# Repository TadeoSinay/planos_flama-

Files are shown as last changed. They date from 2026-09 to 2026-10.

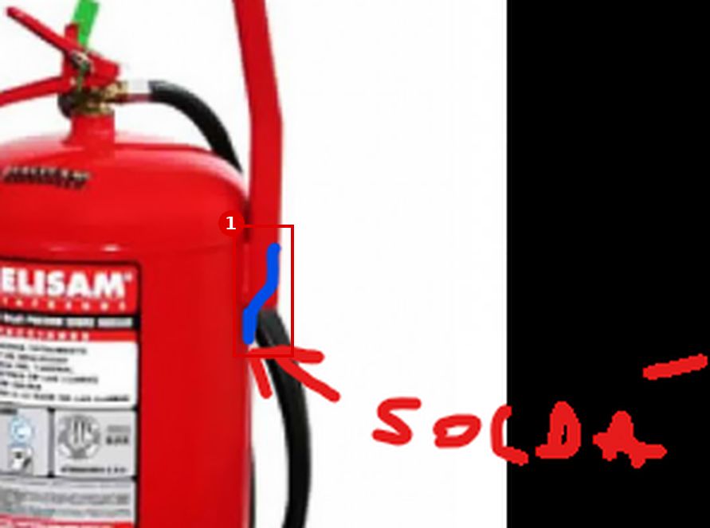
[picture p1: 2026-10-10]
tools/justificacion/figs/F43_c.jpg

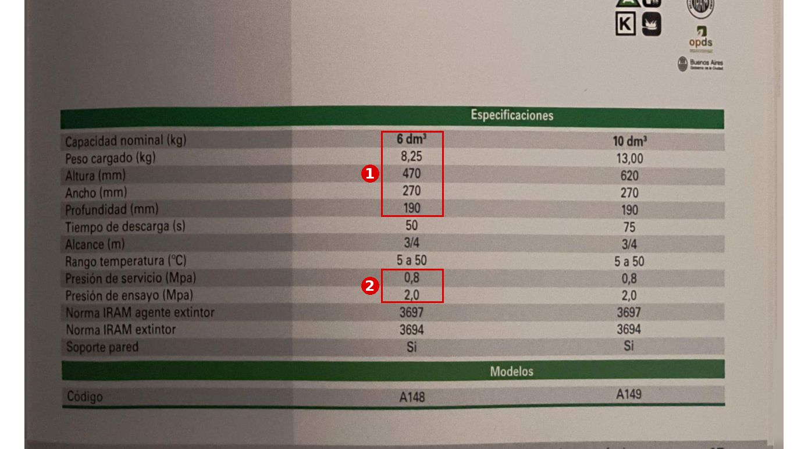
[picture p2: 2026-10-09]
tools/justificacion/figs/F21_c.jpg

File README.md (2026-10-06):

# planos_flama — Planos técnicos de la línea de extintores FLAMA S.A.

Planos de conjunto, cortes, detalles ampliados y modelos 3D de los 17 extintores
del catálogo FLAMA, con rótulo FLAMA S.A. y representación según las normas IRAM
de dibujo técnico y sus equivalentes ISO.

Todo se genera por código a partir de sólidos 3D reales (kernel OpenCascade):
las vistas salen de proyectar esos sólidos con eliminación de líneas ocultas.
Por eso las tres vistas, la isometría, el corte y los detalles son coherentes
entre sí y con el modelo 3D.

## Contenido por modelo (`salida/FL_MAT_<TIPO>_<tamaño>/`)

Nomenclatura: `FL_MAT_<TIPO>_<tamaño>`, por ejemplo `FL_MAT_ABC_10kg`, `FL_MAT_CO2_2kg`,
`FL_MAT_AFFF_50l`. El mismo código figura como N° de plano en el rótulo.

| Archivo | Contenido |
|---|---|
| `FL_MAT_….dxf` | **El plano**: las 3 láminas en un solo dibujo, una presentación por lámina: **Hoja1_Conjunto** (vistas anterior, superior y lateral izquierda en método ISO E, isometría, cotas, números de posición y lista de piezas), **Hoja2_Corte_Detalles** (A2: corte A-A del recipiente y detalles ampliados A–E) y **Hoja3_Especificaciones** (tabla técnica y normas) |
| `FL_MAT_….pdf` | El mismo plano en PDF de 3 páginas a tamaño real (A3/A2) |
| `FL_MAT_….dwg` | Se genera en tu PC con `autocad\1_convertir_DXF_a_DWG.bat` o con el MCP (`autocad_convert_flama_to_dwg`). DWG es un formato cerrado y en este entorno no hay conversor disponible |
| `FL_MAT_….step` | Ensamble 3D con sólidos exactos por pieza (AutoCAD: `IMPORT`) |
| `FL_MAT_…_3D.dxf` | Modelo 3D con una malla por pieza (AutoCAD: `CONVTOSOLID`) |

`salida/FLAMA_planos_completos.pdf` junta los 17 planos (51 láminas) y `salida/validacion.json`
tiene la verificación dimensional.

Los scripts para AutoCAD 2027 están en `autocad/` (ver `autocad/LEAME_AutoCAD.txt`):
convierten los DXF a DWG y abren los modelos 3D con
`"C:\Program Files\Autodesk\AutoCAD 2027\acad.exe" /product ACAD /language "es-ES"`.
Los scripts usan comandos con prefijo `_` (nombres globales en inglés), así que
funcionan igual con AutoCAD en español o en inglés.

## Planos y documentos complementarios

Base normativa leída en su texto completo: **IRAM 3517-2:2020** (dotación, elección, instalación,
señalización, control, mantenimiento y recarga) y **IRAM de Emergencia 3504:2001** (extintores de gases
limpios). Cada lámina y documento cita el apartado. Los PDF de las normas tienen licencia de IRAM y
**no se incluyen en el repositorio**.

Se generan con `python generar.py --complementarios` (o con `python generar.py` sin argumentos).
`salida/FLAMA_complementarios.pdf` junta las 22 láminas y los 5 documentos.

| Carpeta | Código | Contenido |
|---|---|---|
| `salida/cilindros/` | `FL_REC_ABC_1kg` … `FL_REC_ABC_100kg` + `despiece/FL_DES_REC_*` + `FLAMA_cilindros.pdf` | **Cilindros (recipientes ABC sueltos)**, plano de 3 hojas: (1) fabricación: vista, corte A-A, vista D, detalles, cotas con tolerancias; (2) verificación normativa contra IRAM 3523 / 3550 (material, espesor y fórmula 3550 4.1.3, costuras, abertura, estanquidad, expansión, rotura, niebla salina, marcado) y plan de inspección y ensayos por lote; (3) identificación, tapón, protocolo de ensayo y embalaje. Despiece con globos ligado al BOM. DXF + PDF + STEP |
| `salida/sustituto/` | `FL_SUS_00` … `FL_SUS_<tipo>` + `FLAMA_sustitutos.pdf` | **Extintores sustitutos** (IRAM 3517-2:2020 9.4.5; Res. 349/07 art. 32; Res. AGC 32/15): por modelo, faja amarilla ≤ 40 mm en la pollera acotada y desarrollada con sus 3 leyendas, isometría y lista; tarjeta DPS «sustituto habilitado» (PBA) y AGC «Es sustituto» (CABA). FL_SUS_00: equivalencias (igual clase, capacidad ≥) y ciclo de préstamo |
| `salida/senaletica/` | `FL_SEN_01` | Chapa baliza vertical 350 × 870 (y 260 × 870): franjas de 100 mm a 45°, borde fotoluminiscente de 15 mm, tipos de fuego 140 × 140, datos del PRS y n° de puesto (7.2.5, fig. 3); puesto de incendio con alturas (6.2.14, 7.3) |
| | `FL_SEN_02` | Cartel tridimensional de señalización en altura, caras ≥ 280 × 220 a 2,0-2,5 m (7.3, fig. 5) |
| | `FL_SEN_03` | Tipos de fuego: símbolo (letra en contorno) + pictograma, colores IRAM-DEF D 1054 (7.2.2, fig. 1); clases por modelo |
| | `FL_SEN_04` | Etiqueta de control celeste 35 × 50 con frecuencia (8.3.3), "fuera de servicio" 110 × 150 (fig. 8), oblea (9.4.14), numeración (fig. 2), rótulo de manguera 20 × 30 (9.7.1.4) |
| | `FL_SEN_05` | **Sistema de pictogramas NFPA 10 (Anexo B)** por modelo (referencia internacional) |
| | `FL_SEN_06` | Extintor de reserva (faja verde) y sustituto (faja amarilla) (5.3, 9.4.5); placa IRAM 3534 |
| | `FL_SEN_07` | Chapas horizontales o de piso 800 / 500 (fig. 4), chapa de baldes 500 × 500 (fig. 6) y balde 5-7 L (6.2.19) |
| | `FL_SEN_08` | Marbete (anillo plano y cónico, D 33/36/40/50, color por año, fig. 9, tabla 4) y marbete por modelo; traba y precinto (9.4.13) |
| `salida/accesorios/` | `FL_ACC_01` … `03` | Soporte de pared, soporte vehicular y gabinete (7.4), modelados en 3D, 3 vistas ISO E + isometría, STEP |
| `salida/esquemas/` | `FL_ESQ_01` … `03` | Banco de prueba hidrostática (9.7) con presiones de los 17 modelos; línea de carga ABC (9.4.8, 9.4.9); flujo de recarga |
| `salida/documentos/` | `DOC-01` | Tratamiento superficial y pintura: granallado Sa 2½, fosfatizado, polvo poliéster rojo 03-1-050, controles y **saponificación** |
| | `DOC-02` | **Ensayos de fabricación ABC**: rutina, lote y tipo |
| | `DOC-03` | **Control, mantenimiento y recarga por tipo** según IRAM 3517-2:2020 (frecuencias, PH, tabla 3, gas impulsor, recinto de polvo, marbete, inutilización) |
| | `DOC-04` | **NFPA 10 frente a IRAM**: símbolos y colores, pictogramas, NFPA 704, alturas, distancias, intervalos |
| | `DOC-05` | **Ensayos de fabricación HCFC/HFC** según IRAM 3504 |

Origen de cada valor en los documentos: **C** catálogo FLAMA, **N** norma leída, **N\*** norma hermana
aplicada por analogía (IRAM 3504 para criterios de rotura y expansión de los ABC), **R** valor de referencia
a confirmar con la norma de fabricación.

## Modelos

| Código / archivo | Denominación | Norma IRAM agente | Norma IRAM extintor | Fuente de datos |
|---|---|---|---|---|
| FL_MAT_ABC_1kg | Extintor ABC 1 kg | 3569 | 3523 | catálogo pág. 4 · recipiente 1 kg 3" R1 |
| FL_MAT_ABC_2.5kg | Extintor ABC 2,5 kg | 3569 | 3523 | catálogo pág. 4 · recipiente 2,5 kg R2 |
| FL_MAT_ABC_5kg | Extintor ABC 5 kg | 3569 | 3523 | catálogo pág. 4 · recipiente 5 kg R2 |
| FL_MAT_ABC_10kg | Extintor ABC 10 kg | 3569 | 3523 | catálogo pág. 4 · recipiente 10 kg R2 |
| FL_MAT_AGUA_10l | Extintor Agua 10 l | – | 3525 | catálogo pág. 8 |
| FL_MAT_AFFF_10l | Extintor AFFF 10 l | 3515 | 3527 | catálogo pág. 10 |
| FL_MAT_AFFF_50l | Extintor AFFF 50 l sobre ruedas | 3515 | 3541 | catálogo pág. 11 · recipiente 50 kg R2 |
| FL_MAT_BC_5kg | Extintor BC 5 kg | 3569 | 3523 | catálogo pág. 6 · recipiente 5 kg R2 |
| FL_MAT_SALESK_6l | Extintor Sales K 6 l | 3697 | 3694 | catálogo pág. 15 |
| FL_MAT_CO2_2kg | Extintor CO₂ 2 kg | 41170 | 3509 | catálogo pág. 16 |
| FL_MAT_CO2_5kg | Extintor CO₂ 5 kg | 41170 | 3509 | catálogo pág. 16 |
| FL_MAT_HCFC-HFC_5kg | Extintor HCFC/HFC 5 kg | 3526-1 / 3526-5 | 3504 | catálogo págs. 13–14 · recipiente 5 kg R2 |
| FL_MAT_CLASED_9l | Extintor Clase D 9 l | – | 3523 | catálogo pág. 17 · recipiente 10 kg R2 (**ver pendientes**) |
| FL_MAT_ABC_25kg | Extintor ABC 25 kg sobre ruedas | 3569 | 3550 | catálogo pág. 5 · recipiente 25 kg R3 |
| FL_MAT_ABC_50kg | Extintor ABC 50 kg sobre ruedas | 3569 | 3550 | catálogo pág. 5 · recipiente 50 kg R2 |
| FL_MAT_ABC_70kg | Extintor ABC 70 kg sobre ruedas | 3569 | 3550 | catálogo pág. 5 |
| FL_MAT_ABC_100kg | Extintor ABC 100 kg sobre ruedas | 3569 | 3550 | catálogo pág. 5 · rodante 100 kg R1 (Ø390) |

Las normas de producto se transcriben tal como figuran en las filas
"Norma IRAM agente extintor" y "Norma IRAM extintor" del catálogo de referencia.

## Normas de dibujo aplicadas

| Norma | Título | Qué se aplica en las láminas |
|---|---|---|
| IRAM 4501 | Dibujo técnico. Métodos de proyección | Método ISO E: superior (B) debajo de la anterior (A), lateral izquierda (C) a su derecha; símbolo junto a la escala en el rótulo |
| IRAM 4502 | Dibujo técnico. Líneas | Grupo 0,7: A continua gruesa 0,7 (visibles), E trazos **media** 0,35 (ocultas), B continua fina 0,18 (cotas, rayados, referencias, fondos de rosca), F trazo largo y corto fina 0,18 (ejes y centros), G fina con extremos gruesos (plano de corte). Relación 4:2:1 |
| IRAM 4503 | Dibujo técnico. Letras | Letra tipo B vertical; alturas 1,8 · 2,5 · 3,5 · 5 · 7 |
| IRAM 4504 | Formatos, elementos gráficos y plegado de láminas | A3 / A2; recuadro a **25 mm** del borde izquierdo y 10 mm de los demás; marcas de centrado y zonas |
| IRAM 4505 | Dibujo tecnológico. Escalas | Sólo 1:1, 1:2, 1:5, 1:10, 1:20 y 2:1, 5:1; se elige la mayor que entra en A3 o A2 |
| IRAM 4507 | Dibujo técnico. Representación de secciones y cortes | CORTE A-A por el plano de simetría, con letras y flechas |
| IRAM 4508 | Rótulo, lista de materiales y despiezo | Rótulo **175 × 51 mm**; lista de materiales del mismo ancho sobre el rótulo: posición, cantidad, denominación, código, material, **peso**, observaciones |
| IRAM 4509 | Dibujo técnico. Rayados indicadores de secciones y cortes | 45° con línea fina, orientación alternada en piezas contiguas, secciones delgadas ennegrecidas |
| IRAM 4513 | Dibujo técnico. Acotación | Flecha de triángulo lleno **1:4**; separación ≥ altura de cifra; cotas fuera del contorno; coma decimal |
| IRAM 4520 | Dibujo tecnológico. Representación de roscas y partes roscadas | Rosca interior en corte: cresta gruesa, fondo fino |
| IRAM 4540 | Dibujo técnico. Representación de vistas en perspectiva | Isometría con ejes a 120°, sin ocultas |
| ISO 2553 / 4063 | Soldaduras | Filete todo alrededor; proceso **131 MIG** (acero al carbono) o **141 TIG** (inoxidable) |
| ISO 2768-1 | Tolerancias generales | Clase m |

Los datos de las normas IRAM de dibujo (márgenes, rótulo, líneas, flechas, rayados)
se tomaron de resúmenes publicados de cada norma. El texto completo es material
protegido de IRAM y hay que consultarlo en la edición vigente.

## Qué distingue a cada tipo (no sólo las dimensiones)

| Tipo | Recipiente | Válvula | Descarga |
|---|---|---|---|
| ABC / BC / HCFC-HFC | chapa acero SAE 1010, costura MIG, fondo cóncavo con pollera | latón forjado, manómetro IRAM 3533 | manguera + tobera con portatobera (1 kg: tobera directa, sin manguera) |
| Clase D | idem 10 kg | idem | manguera + **lanza aplicadora de flujo suave** con empuñadura |
| Agua | **acero inoxidable AISI 304, costura TIG** | idem | manguera + **tobera de chorro pleno** |
| AFFF | inoxidable, TIG | idem | manguera + **lanza espumígena** con 4 tomas de aire |
| Sales K | inoxidable, TIG | idem | manguera + **lanza aplicadora larga** con boquilla de niebla |
| CO₂ | **cilindro sin costura 34CrMo4, cuello integral**, pie de apoyo | **sin manómetro, con disco de seguridad** | 2 kg: brazo giratorio + difusor; 5 kg: manga de alta presión + difusor con empuñadura y soporte |
| Rodantes ABC | recipiente con dos cabezales, bastidor de caño, ruedas de caucho macizo | idem con manómetro | manguera enrollada + válvula esférica + tobera campana |
| Rodante AFFF 50 l | idem | idem | válvula esférica + **lanza espumígena** |

## Verificaciones automáticas (`verificar.py`)

- Altura y ancho de cada modelo igual al catálogo (±0,05 mm). La profundidad incluye el suncho.
- **Masa**: la suma de la lista de materiales (volumen × densidad) + carga nominal se compara con el peso cargado del catálogo. Da entre −8 % y +12 % en los 17 modelos; el ABC 10 kg da −2 % y su recipiente 5,24 kg, contra 5,48 kg del plano de referencia.
- IRAM 4504 recuadro 25/10, IRAM 4508 rótulo 175 × 51, IRAM 4502 grupo de líneas, IRAM 4513 flecha 1:4, escalas normalizadas, 3 presentaciones, rótulos completos y ningún "A definir".

## Materiales

Ya no queda ningún "A definir". Se respetan los materiales que da el catálogo
(chapa de acero / inoxidable, válvula de latón forjado, manga de caucho sintético,
manómetro con sello IRAM 3533). Para el resto se especifican los materiales
habituales de cada componente: acero SAE 1010 en cuello, manijas y sunchos;
inoxidable AISI 304 en eje y pasador; PVC o polipropileno en el sifón;
polipropileno en toberas y lanzas; polietileno AD aislante en el difusor de CO₂;
caucho macizo y chapa en las ruedas. Ver `flama/materiales.py`.

## Pendientes a confirmar por FLAMA

1. **Clase D 9 l**: el catálogo de referencia sólo tiene clase D de 5 y 10 kg; se usa el recipiente de 10 kg.
2. **Rosca de la válvula de CO₂**: se indica cónica 25E (ISO 11363-1); confirmar con el proveedor del cilindro.
3. **Espesores derivados** (Agua, AFFF, Sales K: 0,8 mm inox; CO₂: 5,4 / 6,0 mm; 70 kg): elegidos para que la masa coincida con el catálogo; confirmar con cálculo a presión de ensayo.
4. Firmas "Revisó" y "Aprobó" del rótulo.
5. Normas de fabricación **IRAM 3523** (polvo manual) y **IRAM 3550** (polvo rodante): confirmar los valores
   N\* y R de DOC-02 (rotura, expansión, ensayos de tipo). **IRAM 3504**: se leyó la edición de emergencia 2001;
   confirmar la vigente. **IRAM 10005**: el archivo recibido es un resumen, no la norma.
6. Pictogramas de las figuras 1 y 5 de IRAM 3517-2 y de NFPA 10: los dibujos son esquemáticos; para imprimir,
   usar los originales de cada norma.

## Regenerar

```bash
python -m venv .venv && . .venv/bin/activate
pip install -r requirements.txt
python generar.py                 # todos
python generar.py FL_MAT_ABC_10kg      # uno
```

Estructura del código:
`flama/catalogo.py` (datos), `flama/modelo3d.py` (sólidos), `flama/vistas.py`
(proyección HLR y cortes), `flama/lamina.py` (formato, rótulo, capas, cotas,
soldadura), `flama/planos.py` (hojas 1–3), `flama/exportar.py` (DXF/PDF/STEP),
`flama/normas.py` (normativa), `flama/recipientes.py` (recipientes sueltos),
`flama/senaletica.py`, `flama/accesorios.py`, `flama/esquemas.py`, `flama/documentos.py`.

## BOM y planos de despiece

`python generar.py --bom` genera **`salida/bom/FLAMA_BOM.xlsx`** y `python generar.py --despiece` genera
**`salida/despiece/FL_DES_<modelo>.dxf/.pdf`** (más `FLAMA_despieces.pdf` con las 17 láminas). Ambos salen del
mismo modelo 3D que los planos FL_MAT / FL_REC, así que código, posición, material, medida y peso coinciden.

| Hoja del Excel | Contenido |
|---|---|
| `01_Indice` | Origen, alcance, niveles, subconjuntos, regla «Entra MRP», códigos, fuentes y **colores de estado** |
| `02_Decisiones` | Decisiones de diseño y abastecimiento con su fundamento (fabricación propia sólo ABC, MRP, polvo DEMSA / Polvex, MAG Arcal 21, varilla, carro propio, tapas, pintura, granallado, inoxidables) |
| `03_Resumen_Productos` | Los 17 productos: agente, carga, gas, pesos frente al catálogo, ítems que entran en MRP |
| `04_BOM_Matafuegos` / `05_BOM_Cilindros` / `06_BOM_Sustitutos` | Tablas planas filtrables (17 FL_MAT, 8 FL_REC, 17 FL_SUS) |
| `07_BOM_Recargas` | Kits RK-*-A/B/C por extintor y caso (IRAM 3517-2:2020), con MRP y proveedor |
| `08_Quimica_Agentes` / `09_Carga_N2` | Densidades (aparente y empacada) y volumen libre, gas impulsor y control de llenado por fórmula |
| `10_Proveedores` | Proveedores nacionales por ítem (principal y alternativa, domicilio, distancia a Avellaneda, precio de referencia, estado) y directorio |
| `11_Validacion_MP` | Respaldo documental y estado de cada materia prima y componente |
| `12_Maestro_Consolidado_MP` | Todo lo que lleva cada matafuego, cilindro, sustituto y kit de recarga por unidad (con Entra MRP, rubro, proveedor y proceso) + insumos de cada proceso con su inductor |
| `13_Fuentes` / `14_Comparacion_Mercado` / `15_Indice_Planos` | Documentos citados, peso contra fabricantes con sello IRAM, índice de planos |
| `BOM_FL_MAT_*` / `BOM_FL_REC_*` | Una hoja por plano: BOM multinivel plegable con fórmulas de peso |

Columnas del BOM: … Origen · **Entra MRP** · **Proveedor principal** · **Alternativa** · Operación · Norma · Fuente ·
Plano · Observaciones. Colores de fila: sin color = validado · **amarillo** = estimado con justificación (norma o
fuente técnica) · **naranja** = a validar (falta dato, cotización o confirmación) · **rojo** = no cumple o decisión
pendiente. Revendidos: el BOM queda completo como referencia y en MRP entra sólo la fila S0 «Equipo terminado
comprado». Proveedores en `flama/proveedores.py`.

Subconjuntos: S1 recipiente (en los ABC = plano FL_REC) · S2 válvula · S3 descarga · S4 carro · S5 carga ·
S6 identificación y precinto · S7 embalaje · S8 soporte · S0 equipo terminado comprado (revendidos).

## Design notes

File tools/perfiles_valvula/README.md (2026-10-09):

# Perfiles de manijas de válvula (planos Fadesa)

Genera `flama/perfiles_valvula.py` a partir de los planos vectoriales Fadesa (no incluidos en el repo).

1. `regiones.py <pdf> x0 y0 x1 y1 600 <salida.png>`: rasteriza la zona de la válvula a 600 dpi y numera las regiones
   cerradas del dibujo (componentes del fondo entre trazos).
2. Mirando la imagen numerada se eligen las regiones de cada pieza (palanca, manija, cuerpo) y en `perfiles.py` se
   pasan a contorno en mm: escala del rótulo (1 kg 1:2,5; 5 kg 1:4), x = 0 en el eje de la válvula, z = 0 en la cara
   superior del cuello (línea entre collarín y rosca).

Zonas usadas (puntos PDF): 1 kg `290 55 445 140`; 5 kg `395 70 525 120`.

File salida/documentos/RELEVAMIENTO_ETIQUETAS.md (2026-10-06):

# Relevamiento de rotulado: norma + mercado → especificación FLAMA

Fuentes. Las normas se citan por apartado y no se transcriben:
- IRAM 3534, 3523, 3550, 3504 y 3517-2.
- IRAM Anexo R.
- Res. OPDS 522/07 y Ord. 40.473.

El relevamiento son 24 fotos de equipos instalados y de la línea de etiquetado (2026):
- Fabricantes: Georgia, Melisam, Fadesa, Horizonte, De León y Maxiseguridad.
- Recargadores: Suyai y Firegram.

La especificación de cada modelo está en la **hoja 4** de su plano FL_MAT. Las piezas están en la BOM, subconjunto S6.

## 1. Etiqueta (placa de características)

| Tema | Norma | Mercado (fotos) | FLAMA adopta |
|---|---|---|---|
| Extensión | IRAM 3534 2.2.4.3: las instrucciones no superan un arco de 108° | La etiqueta envuelve ≈ 200–250°, con columnas laterales de datos y mantenimiento (Georgia, Melisam, Fadesa) | Panel central de 108° con instrucciones, más dos alas de 54° (72° si Ø < 100) |
| Encabezado | 2.2.1 2° marca; 3° a) tipo "MATAFUEGO…" | Marca grande y "EXTINTOR DE POLVO BAJO PRESIÓN" | "FLAMA" y la leyenda de tipo de la norma del producto ("MATAFUEGO A POLVO BAJO PRESIÓN") |
| Instrucciones | 2.2.1 1°: prominentes, con distancia; letra de 3–8 mm (< 9 kg) o 6,5–10 mm (≥ 9 kg) | 3 pasos numerados con ilustración: "ROMPA EL PRECINTO / QUITE EL SEGURO", "COLÓQUESE A 3 m" (1,5 m en 1 kg), "ACCIONE LA PALANCA Y DIRIJA EL CHORRO A LA BASE DEL FUEGO"; la AFFF rodante lleva 4 pasos | Los mismos pasos, adaptados por agente: CO₂, clase K, clase D, AFFF y rodantes |
| Clases | 2.2.2 símbolos ≥ 12 mm; 2.2.3 pictogramas ≥ 18 mm, tachados si no es apto | Fila "PARA FUEGOS CLASE" con el símbolo y el pictograma juntos | Igual |
| Uso eléctrico | — | "APTO PARA INSTALACIONES ELÉCTRICAS" / "NO APTO PARA USAR EN ELECTRICIDAD" | Leyenda en el panel central |
| Logos | 3523 5.2.4 p) Sello IRAM | IRAM, OPDS, GCBA, DPS y QR | Sello IRAM, OPDS, GCBA, DPS y QR a la ficha técnica |
| Datos (ala izq.) | 3534 3° b, c, d, h, i; 3523 5.2.4 (mes/año, n° de recipiente); 7.13 e) | Melisam muestra capacidad, potencial, año, marca del polvo, Ps y PH | Capacidad, agente y grado con marca, potencial + advertencia, Ps, PH, temperaturas, peso total, mes/año, n° de recipiente, "Industria Argentina" |
| Mantenimiento (ala der.) | 3534 3° e, f, g; 3523 5.2.4 j, n, o | Controles mensual, anual y PH cada 5 años; aviso de no mezclar polvos; "presurizar sólo con N₂ seco" | Igual, con el texto del agente por tipo |
| Pie | — | Fadesa: "Habilit. Ord. Mun. 40473 – C.H.A.S. – O.P.D.S. Registro" | FLAMA, domicilio, "Industria Argentina", Ord. 40.473 n°, OPDS n° y C.H.A.S. n° (1, 2,5 y 5 kg) |

## 2. Identificación debajo de la etiqueta y en la válvula

| Elemento | Norma | Mercado | FLAMA |
|---|---|---|---|
| Oblea PBA Ø46 | Res. 522/07 an. 1, 2 y 6: inmediatamente debajo de la placa | Lila con guilloche; anillo "único sello oficial obligatorio…", DPS, Ley 19.587; campo "próxima revisión de carga"; n° tipo "1H01036888" | Pieza `oblea_pba` y detalle R4 |
| Estampilla IRAM | Anexo R | Rosa con guilloche; n° vertical "A 25 1111053"; sello azul; QR; se aplica con etiquetadora. Georgia la pone entre la etiqueta y la oblea | Al costado de la oblea, para respetar la Res. 522/07 (detalle R5). Alternativa: etiqueta BV "MODELO APROBADO" (Horizonte) |
| Tarjeta CABA | Ord. 40.473 art. 6; Res. AGC 32/15 (dos módulos: papel con QR + etiqueta AGC) | Etiqueta autoadhesiva AGC "Tarjeta de Identificación de Extintor" con QR y campos de domicilio, fabricante, recargador, venc. mantenimiento, fecha de fabricación, venc. VU (fabricación + 20 años), n° de tarjeta, agente, capacidad y n° de extintor | Pieza `tarjeta_caba` ≈ 140 × 55 (detalle R8). Antes figuraba como tarjeta colgante: **corregido** |
| Etiqueta de serie | IRAM 3523 5.1 (trazabilidad) | Melisam: etiqueta blanca con QR GS1 "(01)779…" en el costado | Pieza `etiqueta_serie` 45 × 25 a 180° (detalle R7) |
| Faja de garantía | — (garantía comercial) | Georgia: cinta rayada roja y blanca, "ATENCIÓN – la rotura total de esta cinta interrumpe la garantía" | Pieza `faja_garantia` 30 × 40 sobre la unión válvula-cuello (detalle R6). Es el "precinto de apertura" que indica equipo nuevo |
| Precinto | IRAM 3517-2 9.4.13; 3523 3.3.2 | Precinto plástico de color con el nombre del fabricante o recargador (Suyai, Melisam) | Pieza `precinto`: color, "FLAMA" y lote |

## 3. Recargas (no van en el equipo nuevo, sí en la BOM de recargas)

Las fotos de Suyai y Firegram muestran estos elementos:
- Etiqueta de servicio del recargador: n° de extintor, serie, próxima recarga, próxima PH e IRAM 3517-2.
- Precinto de color con el nombre del recargador.

Las normas agregan dos más:
- Oblea PBA de recarga y estampilla-precinto de 1" × 200 mm (Res. 522/07).
- Tarjeta AGC (Ord. 40.473).

Todo esto se agregó a la hoja **Recargas** de la BOM.

## 4. Corrección de datos

- **Potencial del 1 kg con DEM-60:** la licencia IRAM 3523 de Drago (anexo I) dice **1A-5B**. 1A-3B corresponde al polvo Pyrochem. Se corrigió en `flama/agentes.py`, que antes decía 1A-3B:C.

## 5. Pendientes y supuestos

- Medidas reales de la estampilla IRAM (60 × 40), de la tarjeta AGC (140 × 55) y de la faja (30 × 40). Están estimadas a partir de las fotos; hay que confirmarlas con IRAM, con la AGC y con el proveedor.
- 1 kg: la tarjeta AGC no entra en el cuerpo. Se asume que el 1 kg de uso vehicular no la lleva; confirmarlo con la AGC.
- ~~Vida útil~~ RESUELTO: Res. 349/07 art. 26 (mod. 717/07) fija 20 años desde la fabricación (CO₂ 30) y obliga al fabricante a declararla; la tarjeta AGC la incluye. Se agregó a la etiqueta.
- C.H.A.S. (Res. 91/2001): pendiente de leer. Por ahora es un campo a completar en 1, 2,5 y 5 kg.
- Arte final de las ilustraciones de los pasos y de los pictogramas: lo hace el proveedor de etiquetas. El plano fija las posiciones y los tamaños mínimos.
- Números de registro de OPDS, Ord. 40.473 y C.H.A.S.: se completan cuando FLAMA esté inscripta.

## 6. Agregados posteriores (Res. 349/07 PBA y Res. AGC 32/15)

- Cuño DPS de 15 × 7 mm junto al n° del extintor, en pollera u ojiva (Res. 349/07 anexo IV): agregado al marcado grabado (hoja 4 y cilindros).
- Extintor sustituto (IRAM 3517-2:2020 9.4.5): faja amarilla de 40 mm como máximo en la pollera, con 3 leyendas; tarjeta DPS «sustituto habilitado» (Res. 349/07 art. 32); tarjeta AGC «Es sustituto». Planos FL_SUS_*.
- Identificación de recarga completa (IRAM 3517-2, Res. 522/07, Res. 349/07 art. 21 y 28-29, Res. AGC 32/15): lámina FL_SEN_09.

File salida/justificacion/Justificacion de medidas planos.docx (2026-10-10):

Justificación de medidas planos

FLAMA S.A. · origen de cada dimensión de los planos FL_MAT, FL_REC y FL_DES · octubre de 2026

- Cada captura tiene marcas rojas numeradas sobre el dato tomado; debajo, qué dice cada marca. En el Excel «Justificacion de medidas planos.xlsx» la fuente de cada valor se escribe «F10·3» (figura F10, marca 3).
- Lo que no sale de un documento es un valor de diseño FLAMA: figura en la tabla final (D01…) con el link a la línea del generador y en amarillo en el Excel. Naranja = a validar.
- Los procesos FLAMA que mandaste (carros y manuales) fijan el 70 kg (Ø390 × 680), el 100 kg (900), las placas de refuerzo, el tren rodante soldado, el bordón, el encastre del fondo, la muesca del cuello y el número en la cúpula del 1 kg.
- El portaeje con el eje adentro, las chapas triangulares, la manija y la lanza no figuran en los procesos: salen del plano Fadesa «Rodante 50kg 800mm R2» (F41, ángulo medido 30,1°) y de las fotos que mandaste (F42 a F45); sus medidas son de diseño (tabla D). La manija no lleva orejas: el extremo de cada pata se aplasta antes de soldarlo directo al cuerpo, y el doblez de 30° arranca a la altura de la base de la válvula.
- Fadesa es referencia de medidas, no de criterio: donde no cumple la norma manda la IRAM. Ej.: el tren de rodaje sigue la IRAM 3550 tabla III (rueda ≥ Ø300, banda ≥ 50 —Fadesa usa 49—, trocha ≥ 400 entre centros) y no el ancho del catálogo.

1157 dimensiones: con documento 763 (66 %), diseño FLAMA 306 (26 %), a validar 88 (8 %).

## Lo que falta validar

Pieza: dimensión | Modelos | Criterio usado / qué confirmar
Etiqueta / placa de características: Alas laterales (arco c/u) | los 17 | Relevamiento: la etiqueta envuelve ≈ 216° (72° si Ø < 100)
Estampilla IRAM de conformidad: Ancho × alto | los 17 | Anexo R IRAM + relevada (a confirmar)
Etiqueta de n° de serie GS1: Ancho × alto | los 17 | Relevada en Melisam
Faja de garantía válvula-cuello: Ancho × alto (relevada) / dibujada | los 17 | Relevada en la línea Georgia; se dibuja pegada sobre la unión (cuerpo de la válvula, tuerca y cuello), del lado donde no la tapan manómetro ni palancas; el ancho se limita al cuello
Tarjeta de identificación AGC (CABA): Ancho × alto | 16 (todos menos ABC 1 kg) | Relevada en un 10 kg (a confirmar con la AGC)
Cúpula: Altura del casquete | ABC 100 kg, ABC 70 kg | 0,656 × R (relación del cabezal Fadesa 50 kg: 105 / 160) = 0,656 × 195
Fondo: Altura del casquete | ABC 100 kg, ABC 70 kg | 0,656 × R (relación del cabezal Fadesa 50 kg: 105 / 160) = 0,656 × 195

# 1. Planos Fadesa de recipiente

Cotas de los recipientes de 1 a 50 kg y detalles de unión (bordón, fondo encastrado, casquete con borde reducido).

F01 · Plano Fadesa «1kg 3pulg R1» (código G809)

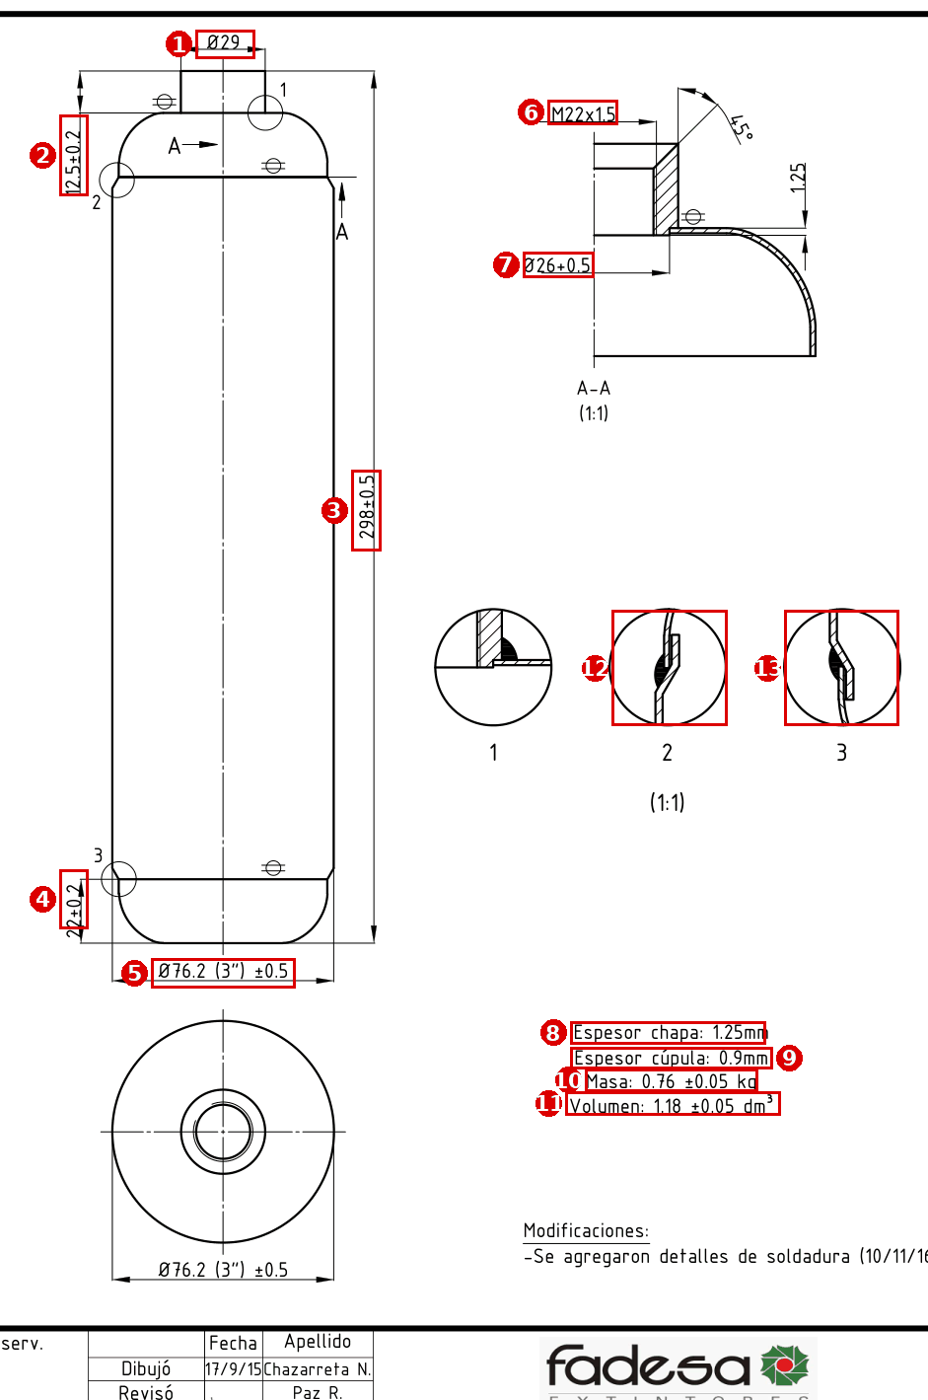
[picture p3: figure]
Plano Fadesa «1kg 3pulg R1» (código G809)

Página 1 (única), cotas y notas del plano

1 Ø29 — Ø exterior del cuello · 2 12,5 ± 0,2 — altura de cúpula · 3 298 ± 0,5 — altura total del recipiente · 4 22 ± 0,2 — altura del fondo · 5 Ø76,2 (3") ± 0,5 — Ø exterior · 6 M22x1,5 — rosca del cuello · 7 Ø26 ± 0,5 — asiento de la válvula · 8 Espesor chapa 1,25 — cuerpo y fondo · 9 Espesor cúpula 0,9 · 10 Masa 0,76 kg — masa del recipiente · 11 Volumen 1,18 dm³ · 12 Detalle 2 (1:1): bordón del caño bajo la cúpula — labio ≈ 5,5, escalón ≈ 4,5 · 13 Detalle 3 (1:1): bordón inferior del caño, fondo por fuera

Nota: El plano no acota la altura del cuello por separado: se tomó 12,5 mm para completar la altura total de 298.

F02 · Plano Fadesa «Recipiente_2.5kg_R2_sin_logo» (código G731)

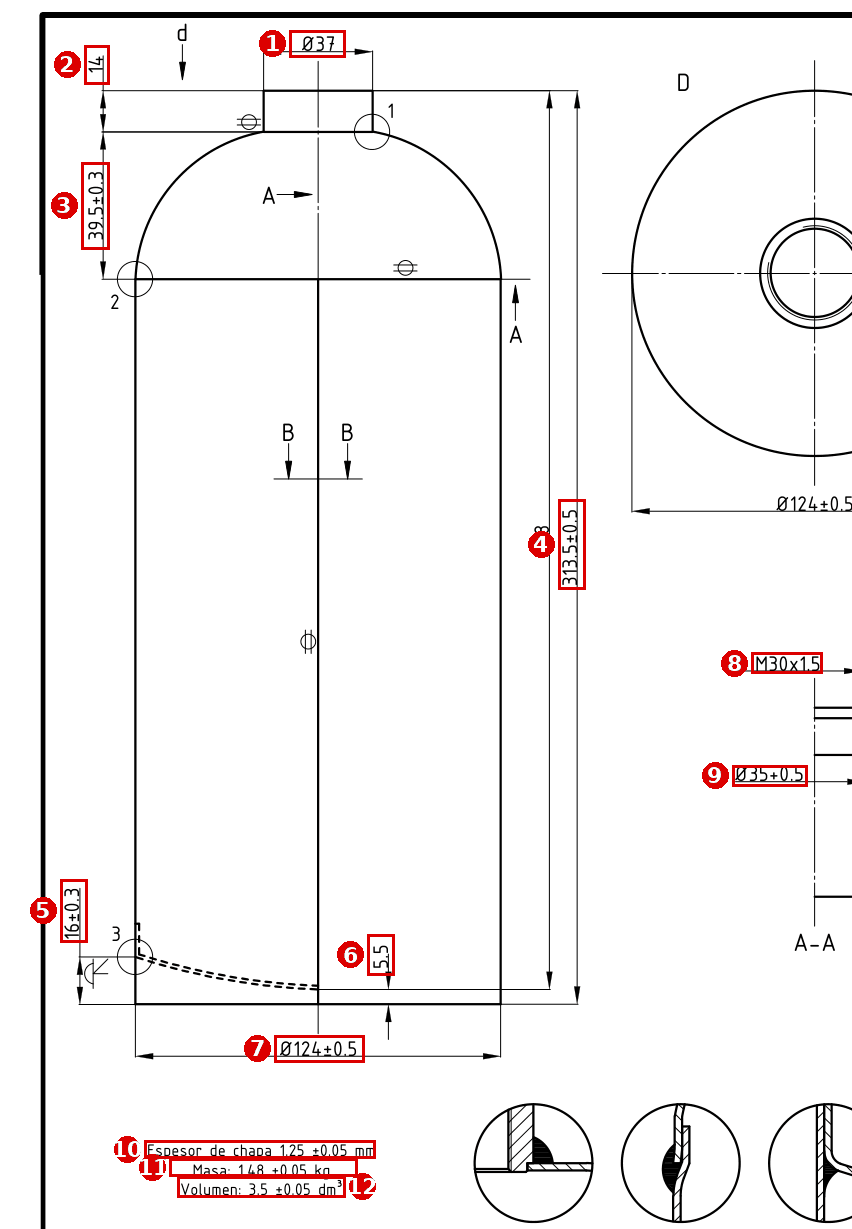
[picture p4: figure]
Plano Fadesa «Recipiente_2.5kg_R2_sin_logo» (código G731)

Página 1 (única), cotas y notas del plano

1 Ø37 — Ø exterior del cuello · 2 14 — altura del cuello · 3 39,5 ± 0,3 — altura de cúpula · 4 313,5 ± 0,5 — altura total · 5 16 ± 0,3 — pollera del fondo cóncavo · 6 5,5 — flecha del fondo cóncavo · 7 Ø124 ± 0,5 — Ø exterior · 8 M30x1,5 — rosca del cuello · 9 Ø35 ± 0,5 — asiento de la válvula · 10 Espesor de chapa 1,25 (cuerpo, cúpula y fondo) · 11 Masa 1,48 kg · 12 Volumen 3,5 dm³

F03 · Plano Fadesa «Recipiente_5kg_R2_sin_logo» (código G732)

Página 1 (única), cotas y notas del plano

1 Ø37 — Ø exterior del cuello · 2 15 ± 0,2 — altura del cuello · 3 54,5 ± 0,3 — altura de cúpula · 4 389,5 ± 0,5 — altura total · 5 21,5 ± 0,2 — pollera del fondo cóncavo · 6 5,5 ± 0,1 — flecha del fondo cóncavo · 7 Ø153 ± 0,5 — Ø exterior · 8 M30x1,5 — rosca del cuello · 9 Ø35 ± 0,5 — asiento de la válvula · 10 Espesor de chapa 1,6 (cuerpo, cúpula y fondo) · 11 Masa 2,78 kg · 12 Volumen 6 dm³ · 13 Detalle 2 (1:1): bordón del cuerpo, cúpula por fuera — labio ≈ 5,8, escalón ≈ 5,2 · 14 Detalle 3 (1:1): fondo encastrado con pestaña ≥ 10, filete por debajo

F04 · Plano Fadesa «Recipiente_10kg_R2_sin_logo» (código G733)

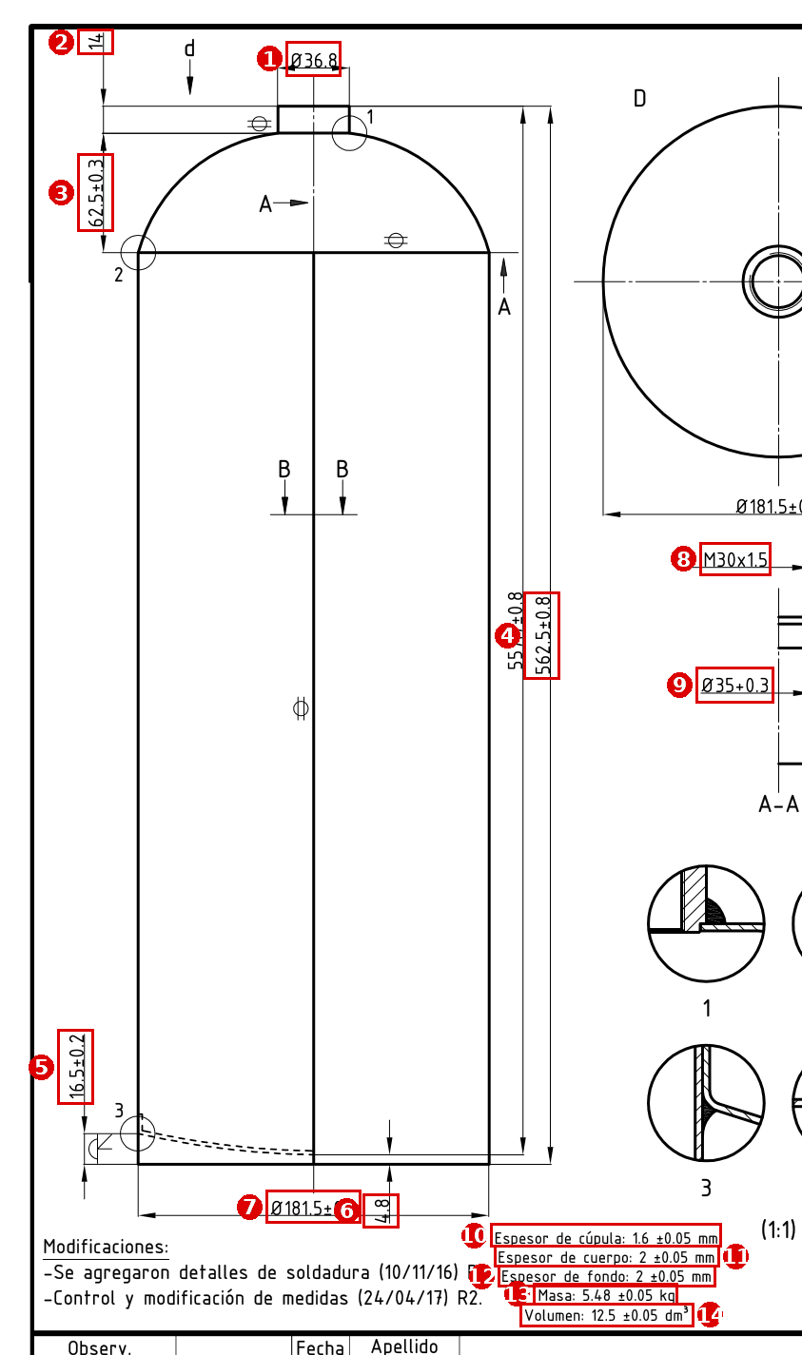
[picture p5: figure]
Plano Fadesa «Recipiente_10kg_R2_sin_logo» (código G733)

Página 1 (única), cotas y notas del plano

1 Ø36,8 — Ø exterior del cuello · 2 14 — altura del cuello · 3 62,5 ± 0,3 — altura de cúpula · 4 562,5 ± 0,8 — altura total · 5 16,5 ± 0,2 — pollera del fondo cóncavo · 6 4,8 — flecha del fondo cóncavo · 7 Ø181,5 ± 0,5 — Ø exterior · 8 M30x1,5 — rosca del cuello · 9 Ø35 + 0,3 — asiento de la válvula · 10 Espesor de cúpula 1,6 · 11 Espesor de cuerpo 2 · 12 Espesor de fondo 2 · 13 Masa 5,48 kg · 14 Volumen 12,5 dm³

F05 · Plano Fadesa «Recipiente 25kg R3» (código G690)

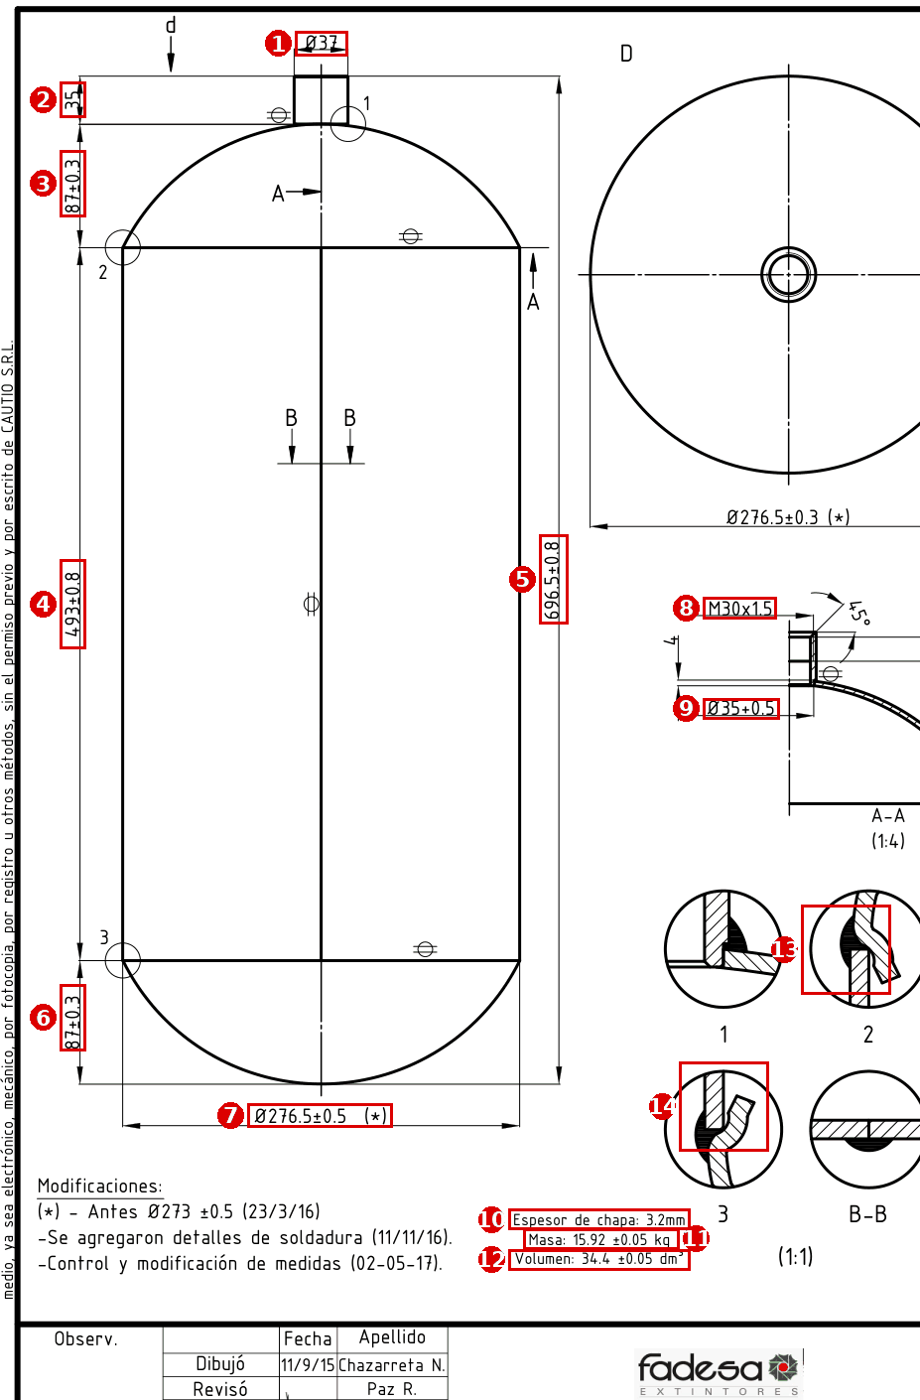
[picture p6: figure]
Plano Fadesa «Recipiente 25kg R3» (código G690)

Página 1 (única), cotas y notas del plano

1 Ø37 — Ø exterior del cuello · 2 35 — altura del cuello · 3 87 ± 0,3 — altura del cabezal superior · 4 493 ± 0,8 — largo del cuerpo entre cabezales · 5 696,5 ± 0,8 — altura total del recipiente · 6 87 ± 0,3 — altura del cabezal inferior · 7 Ø276,5 ± 0,5 — Ø exterior · 8 M30x1,5 — rosca del cuello · 9 Ø35 + 0,5 — asiento de la válvula · 10 Espesor de chapa 3,2 · 11 Masa 15,92 kg · 12 Volumen 34,4 dm³ · 13 Detalle 2 (1:1): casquete con borde reducido y tope dentro del cuerpo · 14 Detalle 3 (1:1): ídem en el casquete inferior

Nota: La altura total 696,5 no es igual a la suma de sus cotas parciales (87 + 493 + 87 + 35 = 702); el plano FLAMA usa las cotas parciales.

F06 · Plano Fadesa «Recipiente 50kg R2» (código G689)

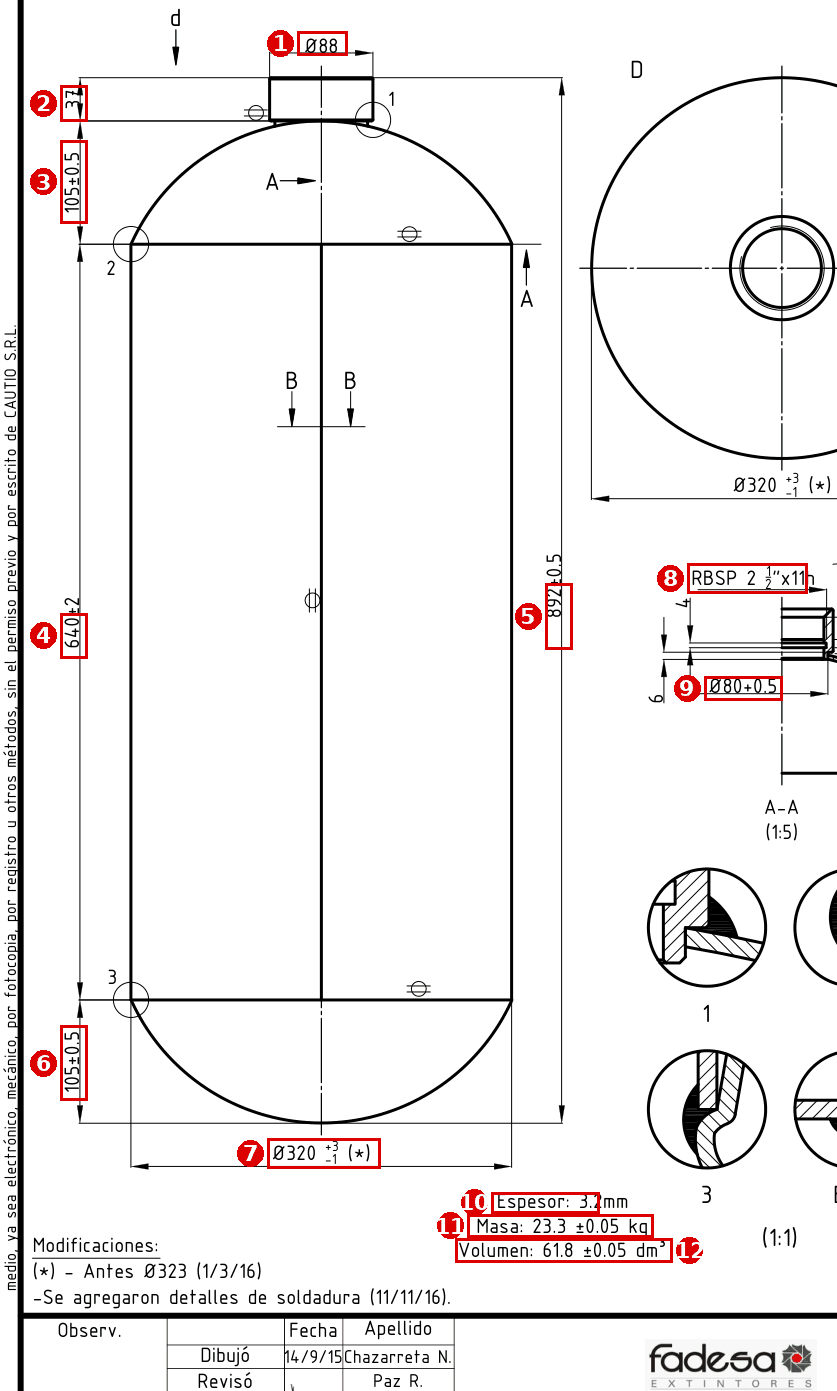
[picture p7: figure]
Plano Fadesa «Recipiente 50kg R2» (código G689)

Página 1 (única), cotas y notas del plano

1 Ø88 — Ø exterior del cuello (cupla) · 2 37 — altura del cuello · 3 105 ± 0,5 — altura del cabezal superior · 4 640 ± 2 — largo del cuerpo entre cabezales · 5 892 ± 0,5 — altura total del recipiente · 6 105 ± 0,5 — altura del cabezal inferior · 7 Ø320 +3/−1 — Ø exterior · 8 RBSP 2 ½" x 11 h — rosca del cuello · 9 Ø80 ± 0,5 — asiento de la válvula · 10 Espesor 3,2 · 11 Masa 23,3 kg · 12 Volumen 61,8 dm³

Nota: La altura total 892 no es igual a la suma de sus cotas parciales (105 + 640 + 105 + 37 = 887); el plano FLAMA usa las cotas parciales. Estas cotas también se usan para el 70 kg (proporción del cabezal y volumen por kg) y para el cuello de 70 y 100 kg.

# 2. Planos Fadesa de extintor completo

Válvula, manómetro, vástago, resorte, caño de pesca, racor, manguera, tobera y suncho medidos a escala; masa total.

F07 · Plano Fadesa «Extintor 1kg Ø76 (Válvula HZ) R1» (código A114/117/122/123/138)

Página 1 (única): notas, cotas generales y piezas del despiece medidas a escala

1 Masa total 1,84 kg (polvo) — referencia de verificación de masa · 2 Válvula HZ · 3 Válvula F510 (esc. 1:2,5): cuerpo 31 × 12 + horquilla 26,5; palanca 67; manija fija 49 + 27 (bajando 34,5); ancho de la válvula 109; espiga M22 Ø21 × 8,6 · 4 Manómetro F645: Ø36 · 5 O-ring F656: Ø24,8 × 3,5 · 6 Vástago F915: Ø5 × 21, asiento Ø9 · 7 Resorte F139: Ø9,8 × 19,9 · 8 Tubo de pesca F003/617: cabeza Ø18,1, tubo Ø14,4

Nota: Piezas medidas sobre el dibujo vectorial a la escala del rótulo (verificada con el Ø del recipiente acotado en su plano de recipiente). Precisión ≈ ±0,5 mm.

F08 · Plano Fadesa «Extintor_2.5kg_Valvula_HZ_R1_sin_logo» (código A101/139/151/128/135)

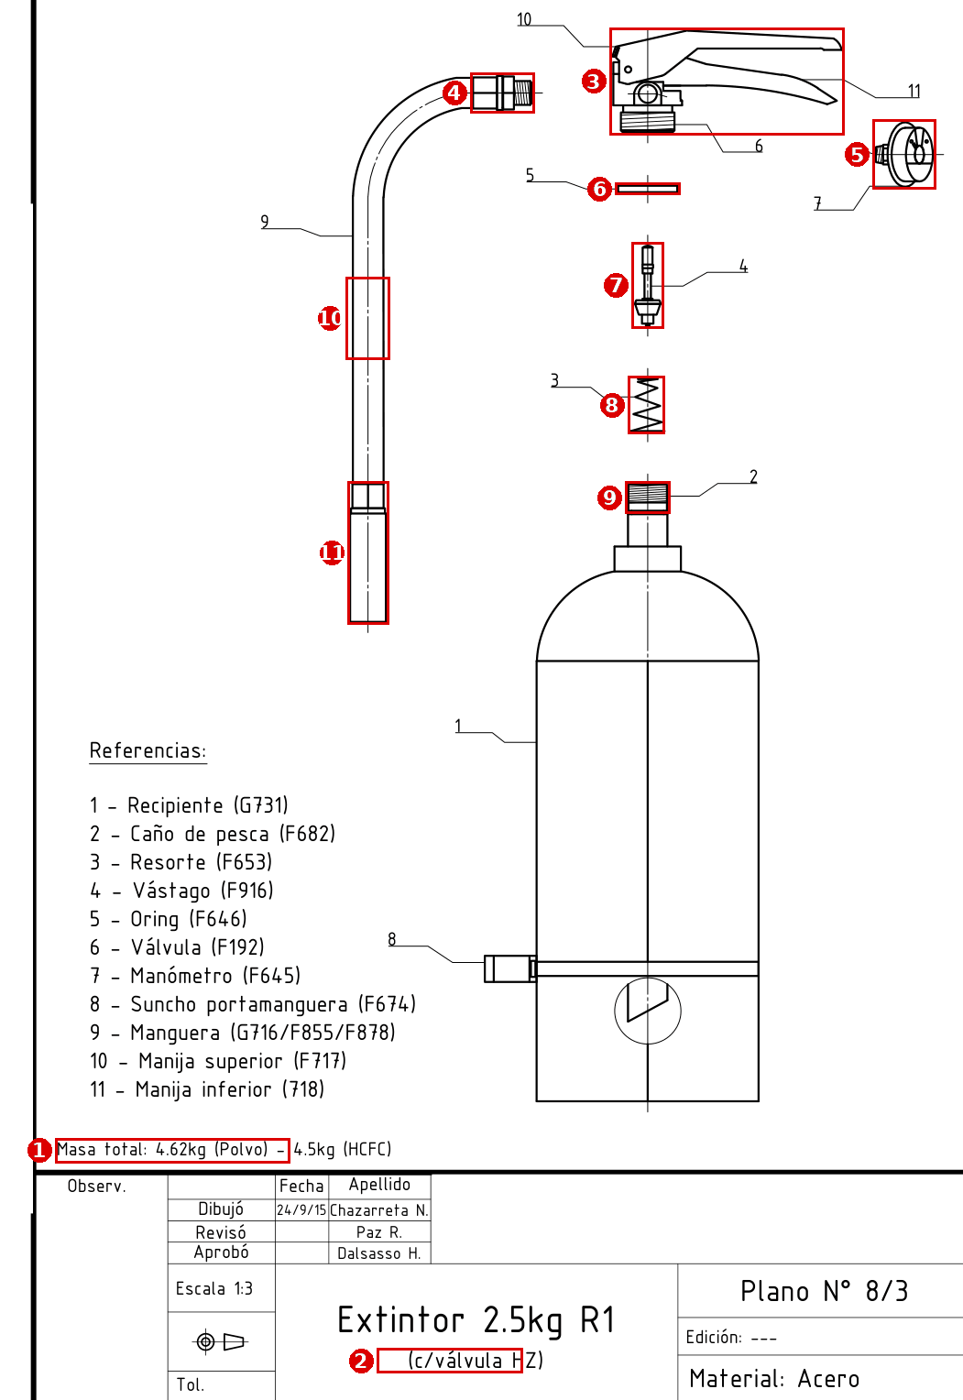
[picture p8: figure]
Plano Fadesa «Extintor_2.5kg_Valvula_HZ_R1_sin_logo» (código A101/139/151/128/135)

Página 1 (única): notas, cotas generales y piezas del despiece medidas a escala

1 Masa total 4,62 kg (polvo) · 2 Válvula HZ · 3 Válvula F192 (esc. 1:3): igual a la del 5 y 10 kg · 4 Racor: tuerca Ø18,8 × 5,9, casquillo Ø16,9 × 13,5, rosca Ø13,1 × 8,9 · 5 Manómetro F645: Ø36 (35,7) · 6 O-ring F646: Ø32,8 × 3,6 · 7 Vástago F916: Ø6 × 30,6, asiento Ø14 · 8 Resorte F653: Ø17,3 × 28,8 · 9 Caño de pesca F682: cabeza Ø21,3 · 10 Manguera: Ø17,4 · 11 Portatobera Ø18,8 × 13,4 + tobera Ø19,9 × 60,1

Nota: Piezas medidas sobre el dibujo vectorial a la escala del rótulo (verificada con el Ø del recipiente acotado en su plano de recipiente). Precisión ≈ ±0,5 mm.

F09 · Plano Fadesa «Extintor_5kg_Valvula_HZ_R1_sin_logo» (código A102/116/140/163/152/111/129/136)

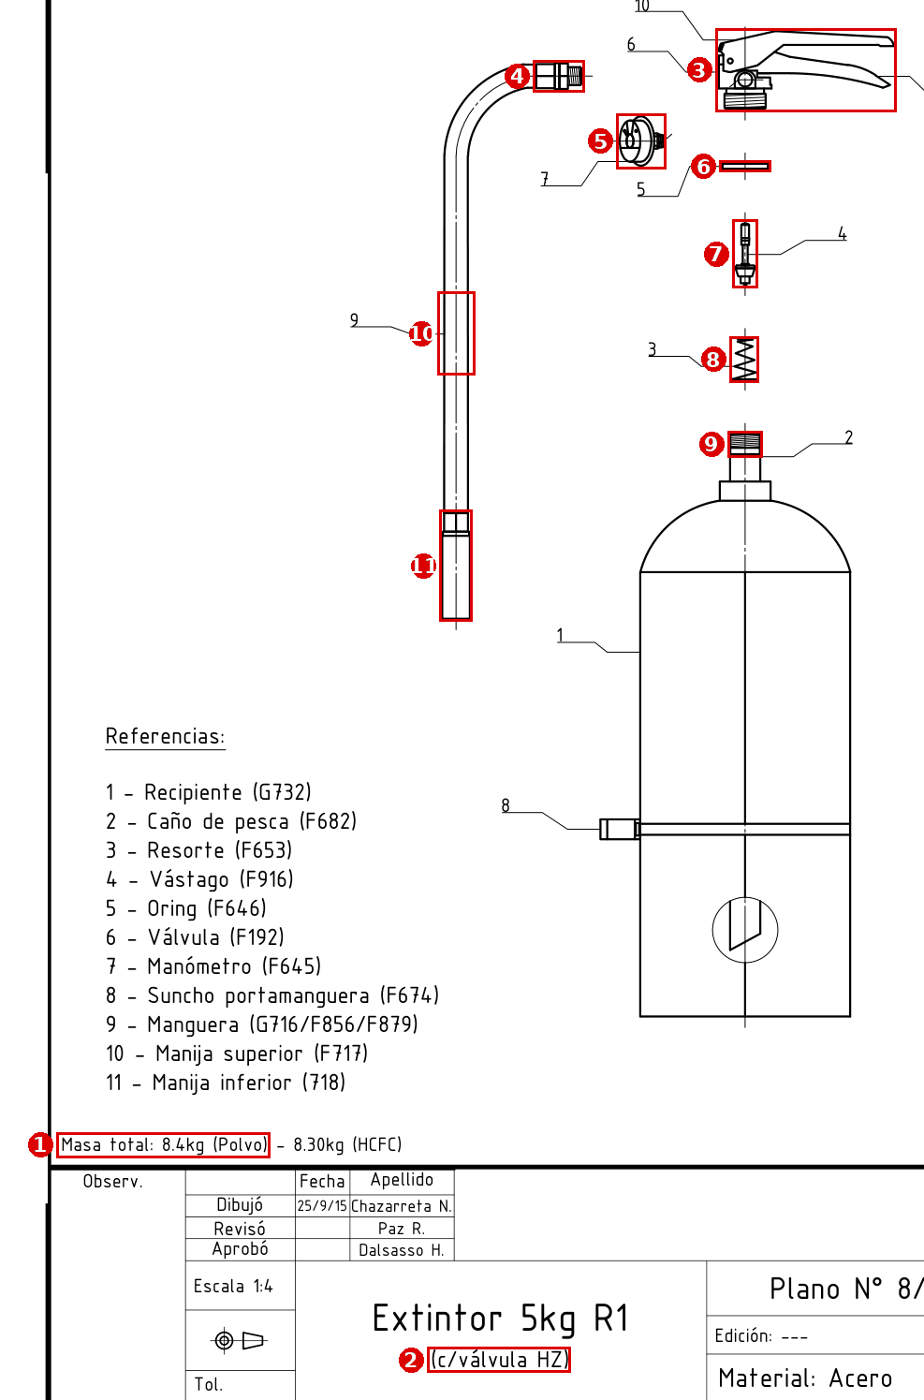
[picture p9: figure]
Plano Fadesa «Extintor_5kg_Valvula_HZ_R1_sin_logo» (código A102/116/140/163/152/111/129/136)

Página 1 (única): notas, cotas generales y piezas del despiece medidas a escala

1 Masa total 8,4 kg (polvo) · 2 Válvula HZ · 3 Válvula F192 (esc. 1:4): palanca 127 de largo, 41,5 de alto sobre el cuerpo; cuerpo 38 × 12,8 + horquilla 32,2; espiga M30 Ø29,8 × 10,8; cuello Ø27,2 × 4,1; manija fija 50 + 36 · 4 Racor: tuerca Ø18,8 × 5,9, casquillo Ø16,9 × 13,5, rosca Ø13,1 × 8,9 · 5 Manómetro F645: Ø36 (35,7) · 6 O-ring F646: Ø32,7 × 3,6 · 7 Vástago F916: Ø6 × 30,8, asiento Ø14 · 8 Resorte F653: Ø17,3 × 28,8 · 9 Caño de pesca F682: cabeza Ø21,3 · 10 Manguera: Ø17,4 · 11 Portatobera Ø19 × 13,3 + tobera Ø19,9 × 60

Nota: Piezas medidas sobre el dibujo vectorial a la escala del rótulo (verificada con el Ø del recipiente acotado en su plano de recipiente). Precisión ≈ ±0,5 mm. Esta válvula F192 es la que se usa también en los manuales revendidos (BC, HCFC, agua, AFFF, Sales K, clase D, CO₂ como referencia).

F10 · Plano Fadesa «Extintor_10kg_HZ_R1_sin_logo» (código A103/141/164/153/112/130/137)

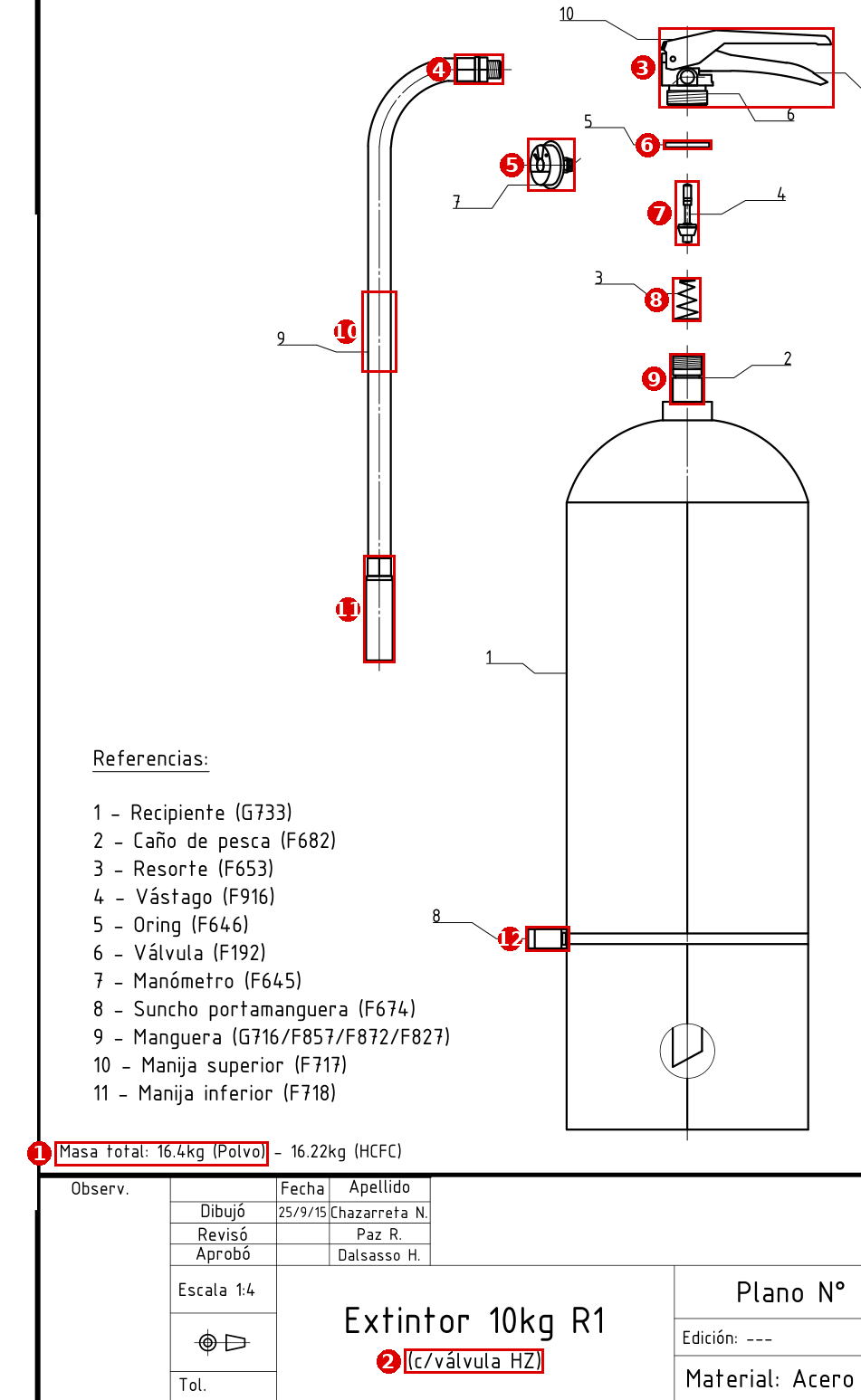
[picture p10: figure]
Plano Fadesa «Extintor_10kg_HZ_R1_sin_logo» (código A103/141/164/153/112/130/137)

Página 1 (única): notas, cotas generales y piezas del despiece medidas a escala

1 Masa total 16,4 kg (polvo) · 2 Válvula HZ · 3 Válvula F192 (esc. 1:4): 127 × 41,5; espiga M30 Ø29,8 × 10,8 · 4 Racor: tuerca Ø18,8, casquillo Ø16,9, rosca Ø13,1 · 5 Manómetro F645: Ø36 (35,7) × 31,5 con vástago · 6 O-ring F646: Ø32,7 × 3,6 · 7 Vástago F916: Ø6 × 30,6, asiento Ø14 × 14 · 8 Resorte F653: Ø17,3 × 28,8 · 9 Caño de pesca F682: cabeza Ø21,3 × 14,4 · 10 Manguera: Ø17,4 (líneas a 12,1 pt) · 11 Portatobera Ø18,8 × 13,4 + tobera Ø19,9 × 60,1 · 12 Suncho portamanguera F674: banda 14,4, sobresale 28,8

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

F11 · Plano Fadesa «Extintor rodante 25kg R1» (código B202/204/217/225/229/235)

Página 1 (única): notas, cotas generales y piezas del despiece medidas a escala

1 Masa total 53,2 kg — referencia de masa (calibración de llanta y sunchos) · 2 1140 — altura total (coincide con el catálogo) · 3 Ø300 — rueda (coincide con el catálogo) · 4 Válvula F192 (esc. 1:6): la misma de los manuales (cuello M30) · 5 Manómetro F645 + cubremanómetro G711: Ø47 · 6 O-ring F646: Ø32,8 · 7 Vástago F916: Ø6 × 30,6 · 8 Resorte F653: Ø17,5 × 29 · 9 Caño de pesca F226: cabeza Ø21,3

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

F12 · Plano Fadesa «Extintor rodante 50kg R1» (código B206/216/222/230/232/236/247)

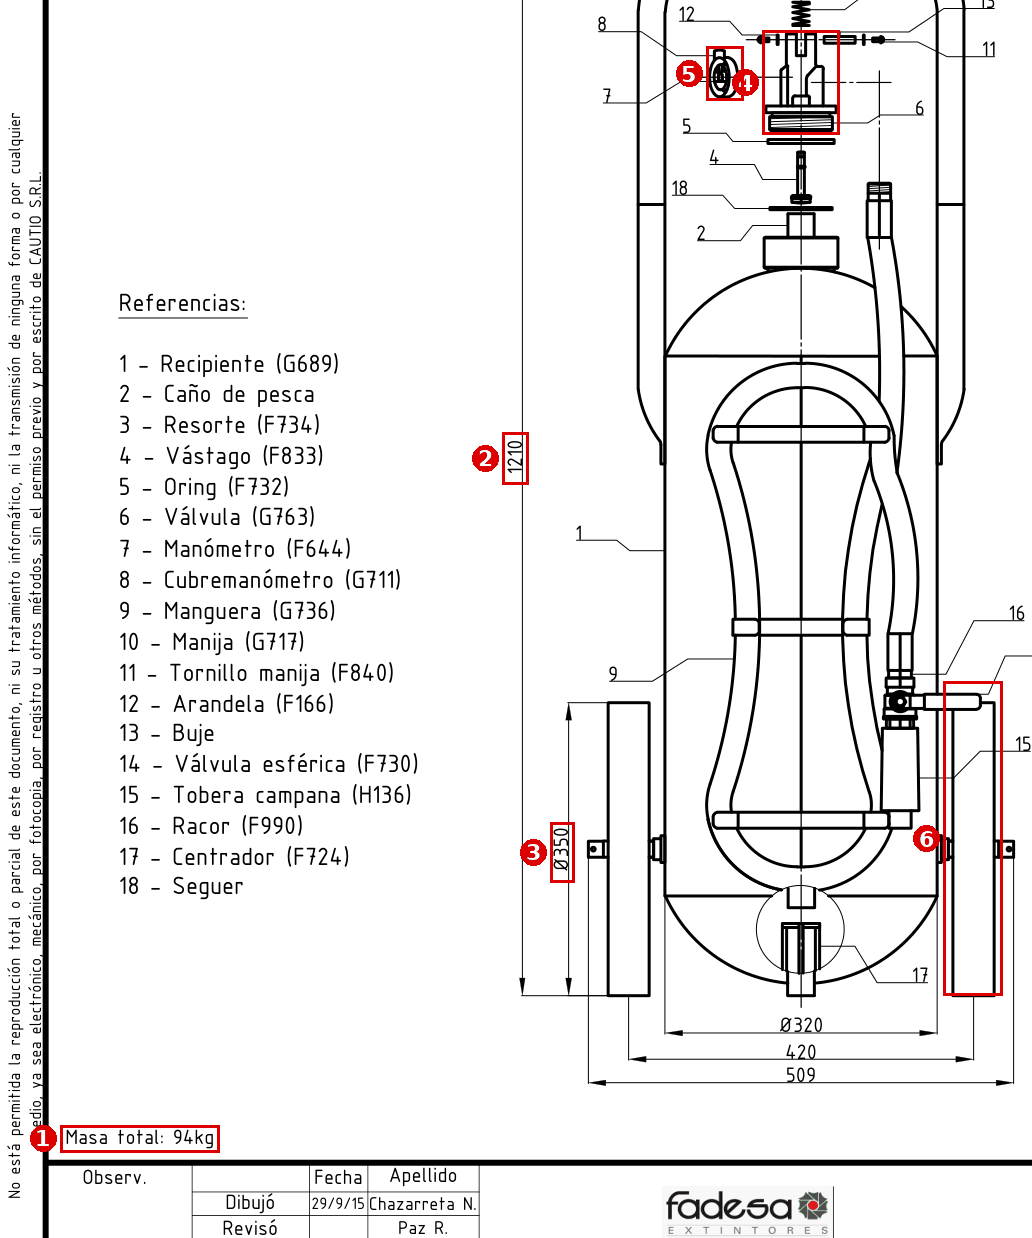
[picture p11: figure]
Plano Fadesa «Extintor rodante 50kg R1» (código B206/216/222/230/232/236/247)

Página 1 (única): notas, cotas generales y piezas del despiece medidas a escala

1 Masa total 94 kg · 2 1210 — altura total (coincide con el catálogo) · 3 Ø350 — rueda (coincide con el catálogo) · 4 Válvula G763 (esc. 1:7): brida Ø83 × 12 + rosca 2½" Ø75 × 17,6; cuerpo 49 × 67 · 5 Manómetro F644 + cubremanómetro G711: Ø47 · 6 Rueda Ø350: ancho de banda 48,9 (líneas a 19,8 pt)

Nota: Piezas medidas sobre el dibujo vectorial a la escala del rótulo (verificada con el Ø del recipiente acotado en su plano de recipiente). Precisión ≈ ±0,5 mm. Esta válvula y estas ruedas se usan también en el 70 kg y en el AFFF 50 l.

F13 · Plano Fadesa «Extintor rodante 100kg R1» (código B208/214/237/238/239/243/244/245)

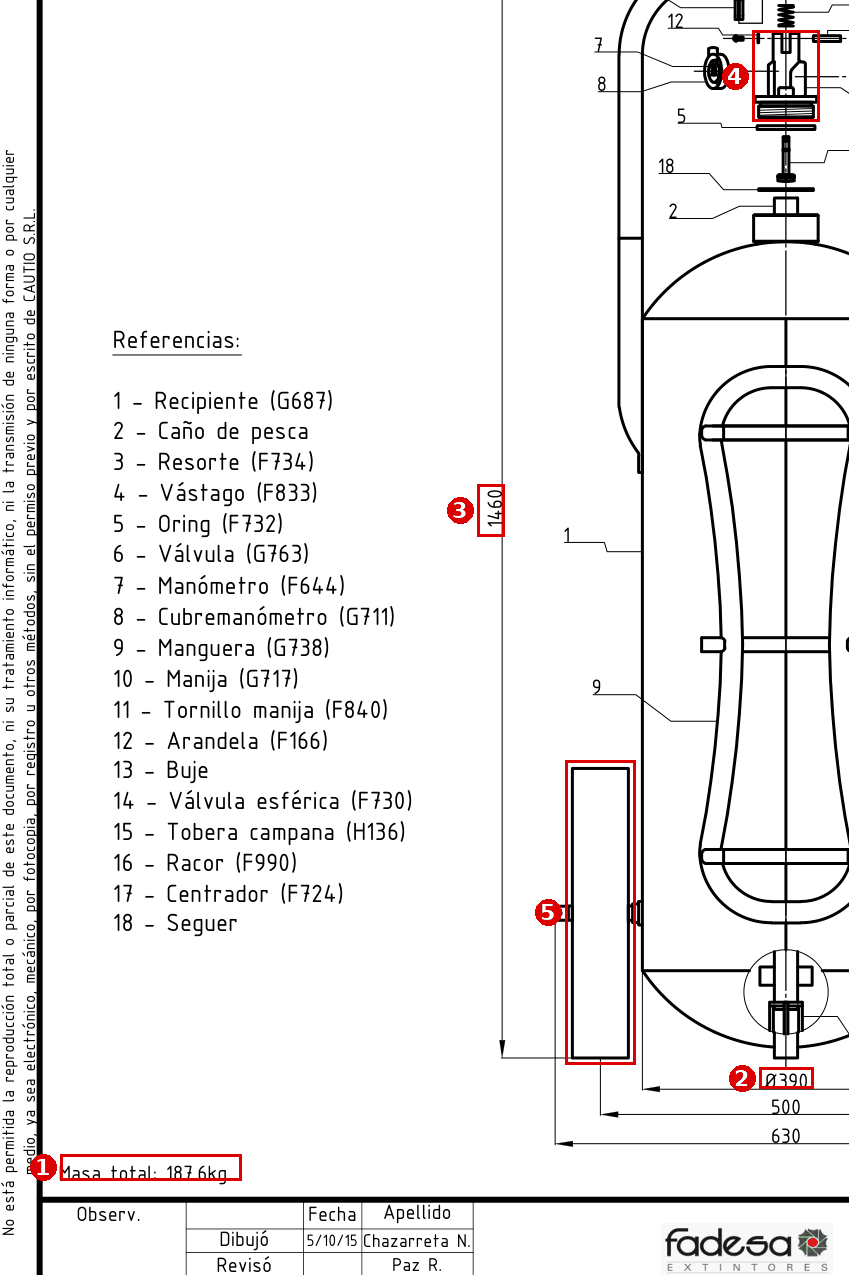
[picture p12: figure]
Plano Fadesa «Extintor rodante 100kg R1» (código B208/214/237/238/239/243/244/245)

Página 1 (única): notas, cotas generales y piezas del despiece medidas a escala

1 Masa total 187,6 kg · 2 Ø390 — Ø exterior del recipiente de 100 kg · 3 1460 — altura total del plano Fadesa (el catálogo dice 1400) · 4 Válvula G763 (esc. 1:8): igual a la del 50 kg · 5 Rueda Ø400: ancho de banda 76 (líneas a 26,9 pt); trocha 500

Nota: Del plano de 100 kg se tomó el Ø390, la masa total y el ancho de rueda; el plano no acota el recipiente: cuerpo y cabezales del 100 kg se calcularon (figura del código _g_rodante). Piezas medidas sobre el dibujo vectorial a la escala del rótulo (verificada con el Ø del recipiente acotado en su plano de recipiente). Precisión ≈ ±0,5 mm.

# 3. Catálogo Fadesa 3

Peso, altura, ancho, profundidad, rueda, manga y presiones de cada modelo.

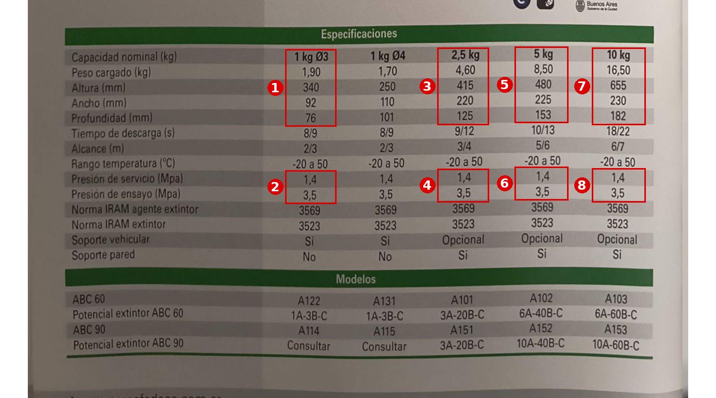
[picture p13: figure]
Catálogo Fadesa 3, pág. 4: tabla «Especificaciones»

F14 · Catálogo Fadesa 3, pág. 4: tabla «Especificaciones» Página 4, tabla Especificaciones 1 1 kg Ø3: peso cargado, altura, ancho, profundidad · 2 1 kg Ø3: presión de servicio y de ensayo (MPa) · 3 2,5 kg: peso cargado, altura, ancho, profundidad · 4 2,5 kg: presión de servicio y de ensayo (MPa) · 5 5 kg: peso cargado, altura, ancho, profundidad · 6 5 kg: presión de servicio y de ensayo (MPa) · 7 10 kg: peso cargado, altura, ancho, profundidad · 8 10 kg: presión de servicio y de ensayo (MPa) | F15 · Catálogo Fadesa 3, pág. 5: tabla «Especificaciones» Página 5, tabla Especificaciones 1 25 kg: peso cargado, altura, ancho, profundidad, Ø rueda, manga · 2 25 kg: presión de servicio y de ensayo (MPa) · 3 50 kg: peso cargado, altura, ancho, profundidad, Ø rueda, manga · 4 50 kg: presión de servicio y de ensayo (MPa) · 5 70 kg: peso cargado, altura, ancho, profundidad, Ø rueda, manga · 6 70 kg: presión de servicio y de ensayo (MPa) · 7 100 kg: peso cargado, altura, ancho, profundidad, Ø rueda, manga · 8 100 kg: presión de servicio y de ensayo (MPa)

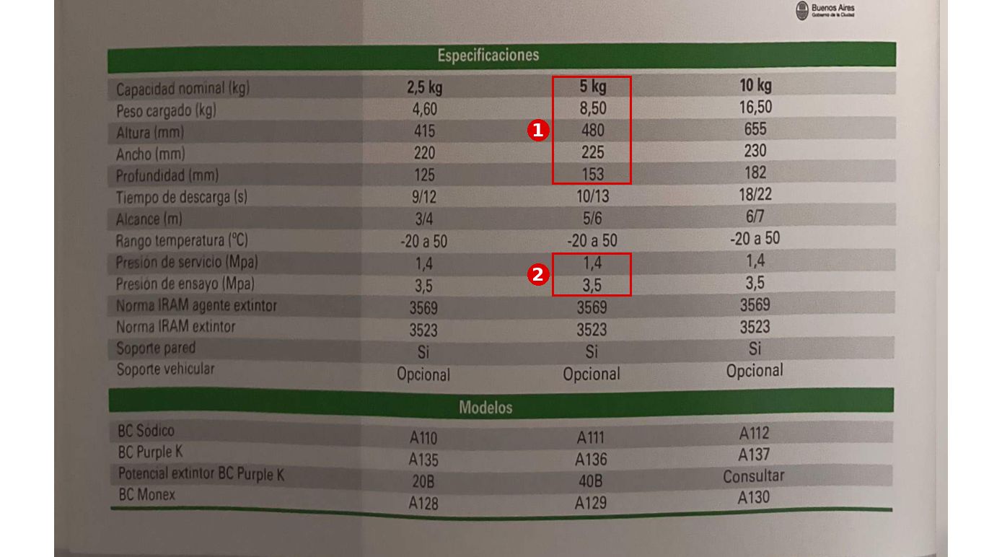
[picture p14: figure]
Catálogo Fadesa 3, pág. 6: tabla «Especificaciones»
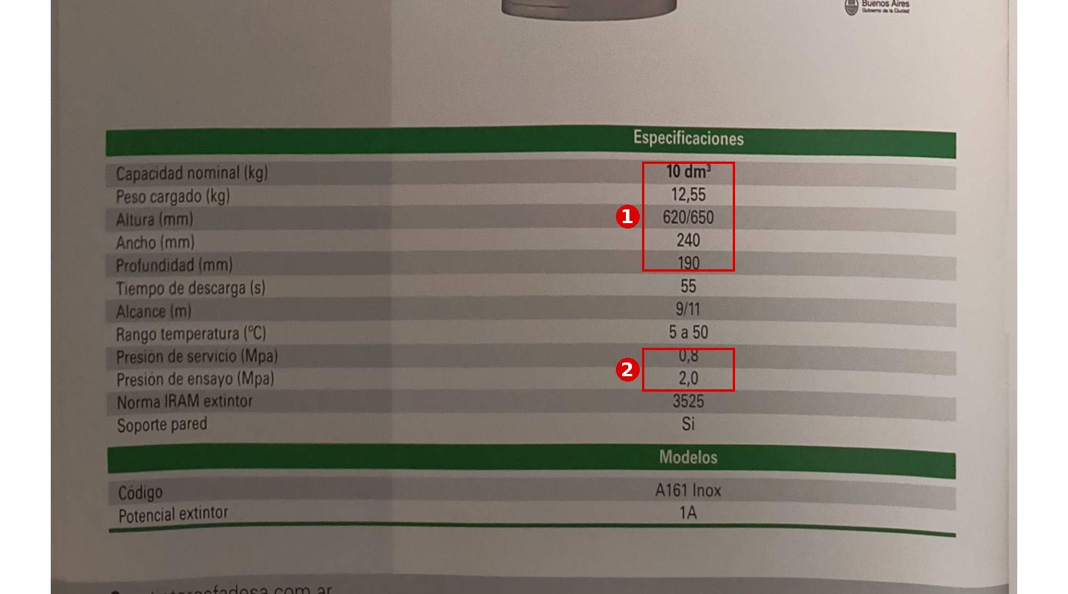
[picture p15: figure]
Catálogo Fadesa 3, pág. 8: tabla «Especificaciones»

F16 · Catálogo Fadesa 3, pág. 6: tabla «Especificaciones» Página 6, tabla Especificaciones 1 BC 5 kg: peso cargado, altura, ancho, profundidad · 2 BC 5 kg: presión de servicio y de ensayo (MPa) | F17 · Catálogo Fadesa 3, pág. 8: tabla «Especificaciones» Página 8, tabla Especificaciones 1 Agua 10 dm³: peso cargado, altura, ancho, profundidad · 2 Agua 10 dm³: presión de servicio y de ensayo (MPa) Nota: La altura figura como 620/650: el plano usa 650.

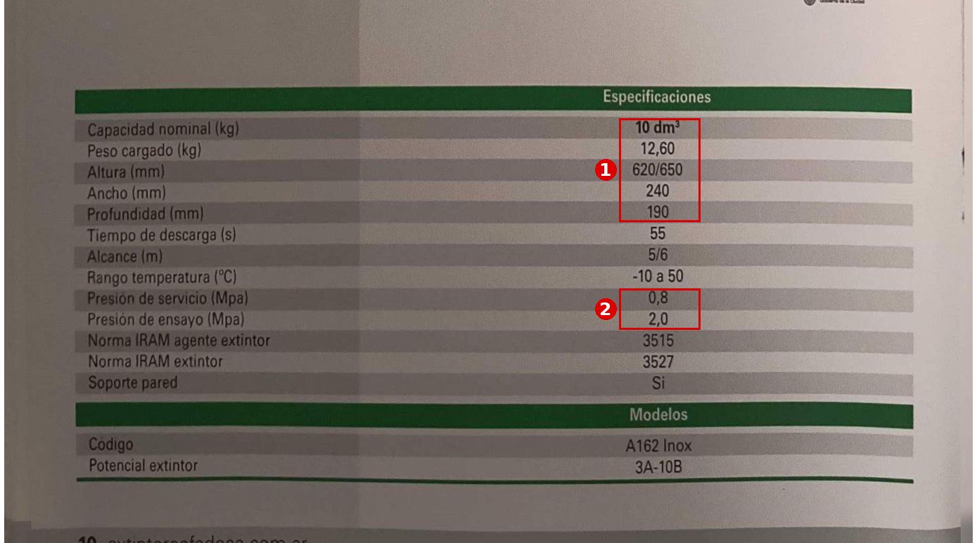
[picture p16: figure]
Catálogo Fadesa 3, pág. 10: tabla «Especificaciones»
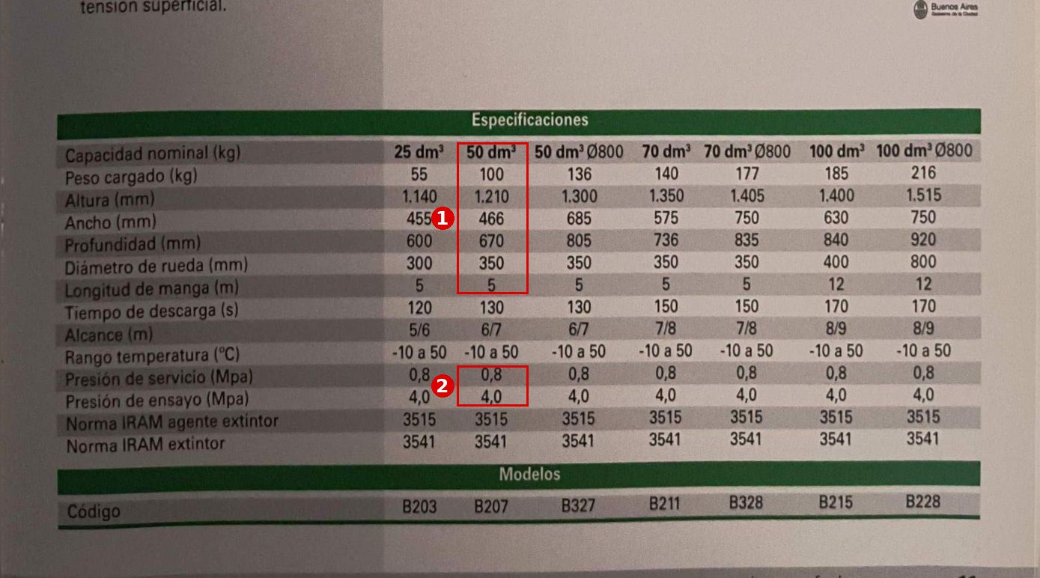
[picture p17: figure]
Catálogo Fadesa 3, pág. 11: tabla «Especificaciones»

F18 · Catálogo Fadesa 3, pág. 10: tabla «Especificaciones» Página 10, tabla Especificaciones 1 AFFF 10 dm³: peso cargado, altura, ancho, profundidad · 2 AFFF 10 dm³: presión de servicio y de ensayo (MPa) Nota: La altura figura como 620/650: el plano usa 650. | F19 · Catálogo Fadesa 3, pág. 11: tabla «Especificaciones» Página 11, tabla Especificaciones 1 AFFF 50 dm³: peso cargado, altura, ancho, profundidad, Ø rueda, manga · 2 AFFF 50 dm³: presión de servicio y de ensayo (MPa)

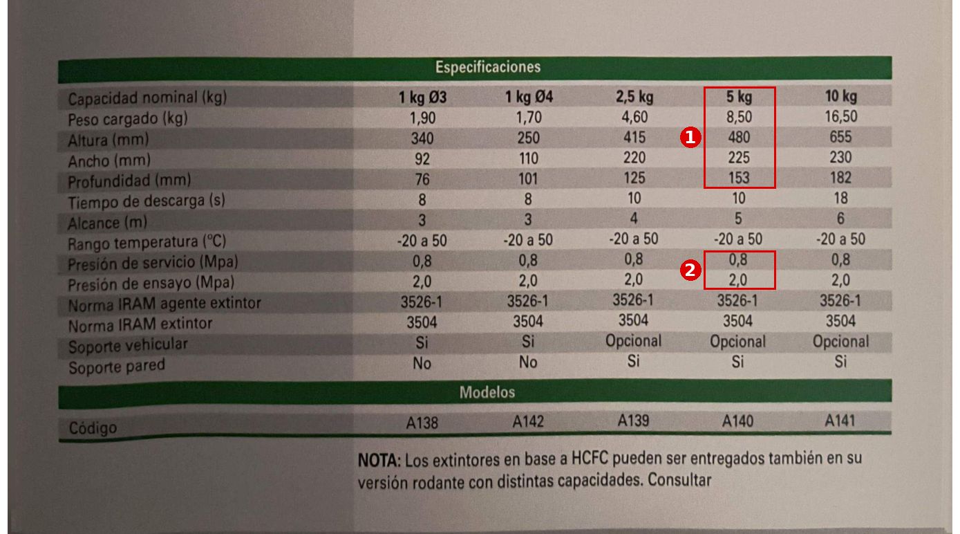
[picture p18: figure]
Catálogo Fadesa 3, pág. 13: tabla «Especificaciones»
Catálogo Fadesa 3, pág. 15: tabla «Especificaciones»

F20 · Catálogo Fadesa 3, pág. 13: tabla «Especificaciones» Página 13, tabla Especificaciones 1 HCFC 5 kg: peso cargado, altura, ancho, profundidad · 2 HCFC 5 kg: presión de servicio y de ensayo (MPa) Nota: La pág. 14 (HFC 236fa) repite los mismos valores para 5 kg. | F21 · Catálogo Fadesa 3, pág. 15: tabla «Especificaciones» Página 15, tabla Especificaciones 1 Sales K 6 dm³: peso cargado, altura, ancho, profundidad · 2 Sales K 6 dm³: presión de servicio y de ensayo (MPa)

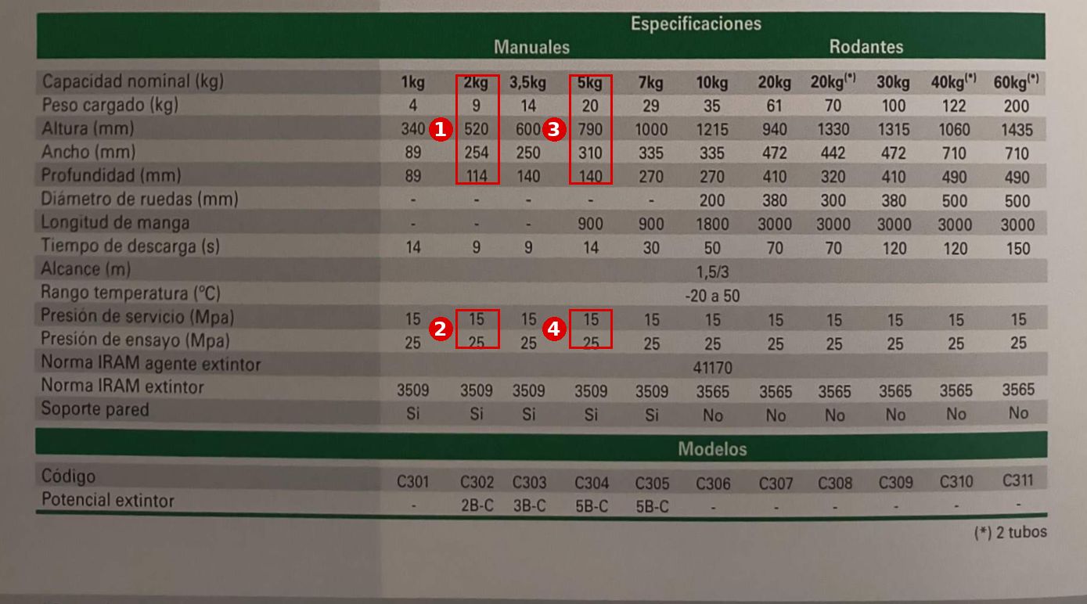
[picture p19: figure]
Catálogo Fadesa 3, pág. 16: tabla «Especificaciones»

F22 · Catálogo Fadesa 3, pág. 16: tabla «Especificaciones» Página 16, tabla Especificaciones 1 CO₂ 2 kg: peso cargado, altura, ancho, profundidad · 2 CO₂ 2 kg: presión de servicio y de ensayo (MPa) · 3 CO₂ 5 kg: peso cargado, altura, ancho, profundidad · 4 CO₂ 5 kg: presión de servicio y de ensayo (MPa) | F23 · Catálogo Fadesa 3, pág. 17: tabla «Especificaciones» Página 17, tabla Especificaciones 1 Clase D (se usa la columna 10 kg): peso cargado, altura, ancho, profundidad · 2 Clase D (se usa la columna 10 kg): presión de servicio y de ensayo (MPa) Nota: El catálogo sólo lista clase D de 5 y 10 kg; el 9 l de la lista FLAMA usa la columna de 10 kg (a confirmar).

# 4. Fichas de mercado y normas

Masas de referencia sin plano Fadesa; cláusulas IRAM y resoluciones usadas (se citan, no se transcriben).

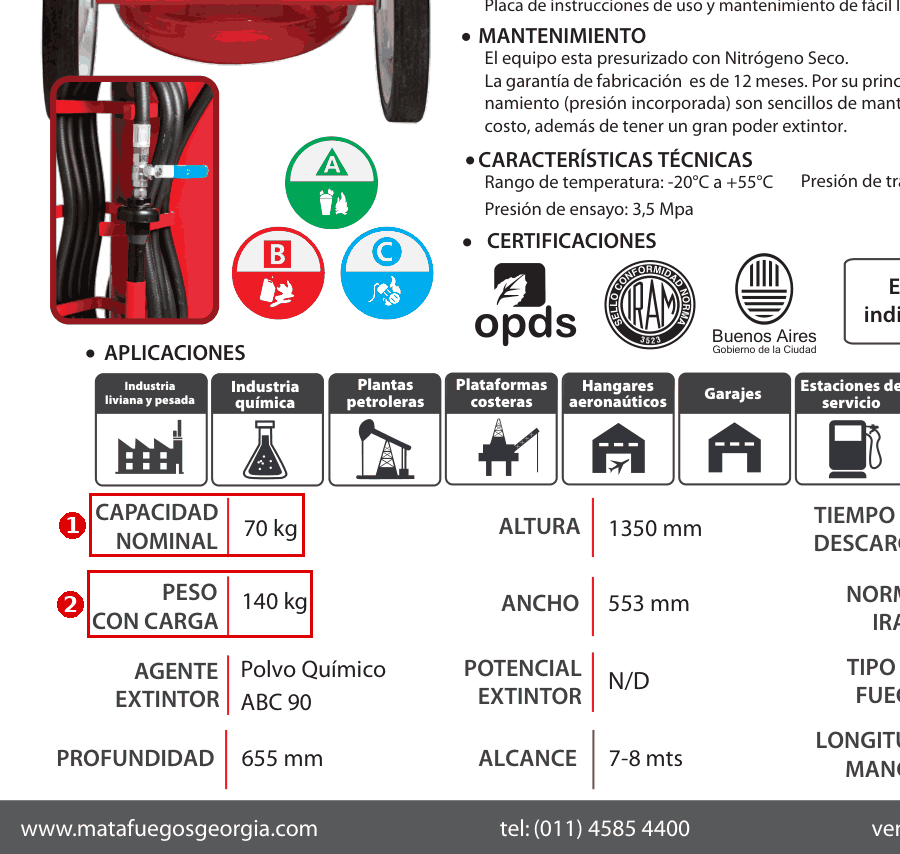
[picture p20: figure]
Ficha técnica Georgia ABC 90 — 70 kg

F24 · Ficha técnica Georgia ABC 90 — 70 kg Página 1, recuadro de datos 1 Capacidad nominal 70 kg · 2 Peso con carga 140 kg — referencia de masa del 70 kg Nota: No hay plano Fadesa de 70 kg: la masa de referencia es la de esta ficha. | F25 · Ficha técnica Melisam — acetato de potasio 6 L Página 2, tabla de especificaciones, fila «Peso bruto» 1 Peso bruto 9,5 kg (6 L) — referencia de masa del Sales K 6 l
F26 · IRAM 3550:1981, cláusula 4.1.3.2 (espesor mínimo del recipiente) Pág. 9 de la norma (hoja 11 del PDF), apartado 4.1.3.2 1 4.1.3.2 — mínimo 2,9 mm hasta Ø320 y 4,5 mm por encima → chapa 4,75 en 70 y 100 kg | F27 · IRAM 3534:1983, apartado 2.2.4.3 d) (longitud de la leyenda: arco de 108°) Pág. 8 de la norma (hoja 8 del PDF), apartado 2.2.4.3 d) 1 2.2.4.3 d) — máximo: arco de 108° → ancho del panel central de la etiqueta
F28 · IRAM 3525:1983, apartado 3.2.1 b) (espesor mínimo del recipiente inoxidable) Pág. 5 de la norma (hoja 5 del PDF), apartado 3.2.1 b) 1 3.2.1 b) — acero inoxidable de espesor no menor de 0,63 mm → se adoptó 0,8 | F29 · Res. OPDS 522/07, Anexo 2 (oblea de fabricación de extintores de más de 1 kg) Hoja 6 del PDF, Anexo 2, apartado «Oblea» 1 Anexo 2: oblea de fabricación de extintores de más de 1 kg · 2 «formato de 46…» · 3 «…milímetros de diámetro» → oblea Ø46 Nota: El Anexo 1 (hoja 4 del PDF) fija el mismo formato de 46 mm para la oblea de 1 kg.

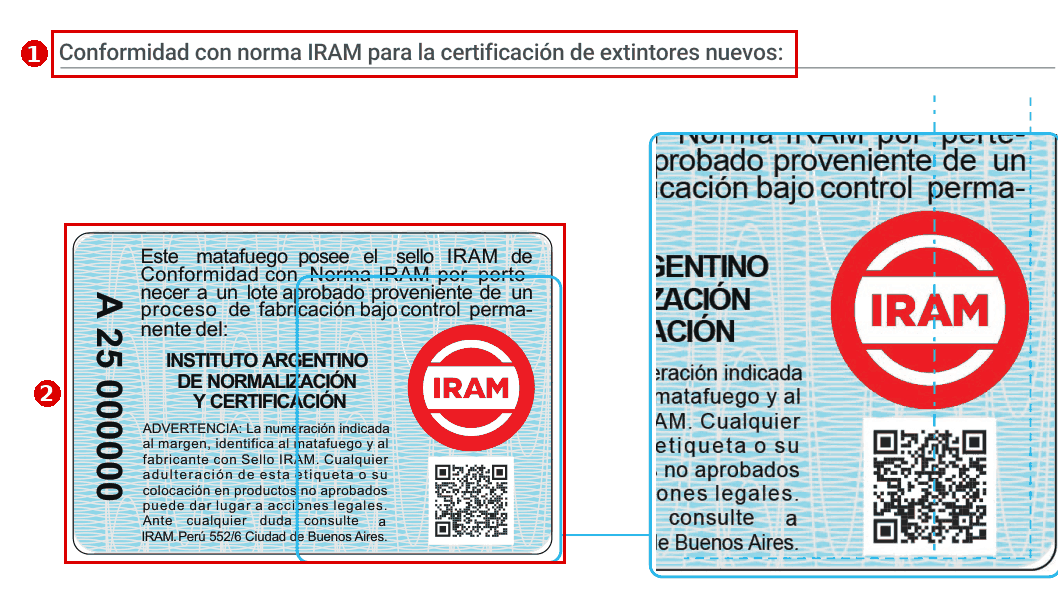
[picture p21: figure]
IRAM Anexo R — estampilla de conformidad de extintor nuevo

F30 · IRAM Anexo R — estampilla de conformidad de extintor nuevo Hoja 3 del PDF, «Conformidad con norma IRAM para la certificación de extintores nuevos» 1 Estampilla para la certificación de extintores nuevos · 2 Estampilla: proporción ≈ 3:2 → se adoptó 60 × 40 mm (sin cota en el documento; a confirmar con IRAM) | F40 · IRAM 3550:1981, 4.8.2 tabla III (medidas del tren de rodaje) Pág. 11 de la norma (hoja 13 del PDF), apartado 4.8.2, tabla III 1 Tabla III — rueda Ø ≥ 300, ancho de rodado ≥ 50, trocha entre centros ≥ 400 (Fadesa usa banda 49: no cumple)

# 5. Relevamiento y planilla MP

Identificación relevada en fotos (a validar) y celdas de la planilla de abastecimiento.

F31 · Relevamiento: tarjeta AGC (CABA) en un extintor de 10 kg Foto completa 1 Tarjeta de identificación AGC autoadhesiva con QR → 140 × 55 mm Nota: Medida estimada por proporción con el Ø del recipiente de 10 kg (181,5 mm); confirmar con la AGC. | F32 · Relevamiento: etiqueta envolvente y estampilla IRAM (línea Georgia) Foto completa 1 Etiqueta envolvente: panel central + alas (≈ 216° en total) · 2 Estampilla IRAM con n° vertical, logo y QR → 60 × 40 mm Nota: Medidas estimadas por proporción con el Ø del recipiente; confirmar.
F33 · Relevamiento: etiqueta de n° de serie GS1 (línea Melisam) Foto completa 1 Etiqueta GS1 con QR «(01)779…» → 45 × 25 mm Nota: Medida estimada por proporción; confirmar. | F34 · Relevamiento: faja de garantía rayada (línea de etiquetado Georgia) Foto completa 1 Faja de garantía rayada roja/blanca → 30 × 40 mm Nota: Medida estimada por proporción; confirmar.

F35 · Relevamiento: oblea circular PBA (DPS) aplicada

Foto completa

1 Oblea circular de la Provincia de Buenos Aires (ver Res. 522/07: Ø46)

F36 · Planilla MP FLAMA — geometría del acero por recipiente

Hoja «Geometria Acero», celdas marcadas (reproducción de los valores de las celdas)

1 C35: caño del 1 kg cortado a 255 mm · 2 D34:H35: desarrollo (fila 34) y alto (fila 35) del recorte del cuerpo 2,5 a 50 kg · 3 C38:F38: Ø del disco de cúpula 1 a 10 kg · 4 C44:F44: Ø del disco de fondo 1 a 10 kg · 5 J32: espesor de chapa 4,75 de 70 / 100 kg

Nota: Las filas 34-35 de 70 y 100 kg (1212 × 680 / 900) NO se usan: no corresponden al plano (ver BOM). Las filas 37 y 43 del 1 kg y del 10 kg difieren de los planos (cúpula 10 kg 1,6; fondo 1 kg 1,25): corregir la planilla.
F37 · Planilla MP FLAMA — MP-22 varilla de refuerzo Hoja «MP Abastecimiento», fila 25 (reproducción de los valores de las celdas) 1 MP-22: varilla de refuerzo de 70 / 100 kg · 2 «Barra de 6 m (medida a definir por cálculo)» → se adoptó Ø8 (decisión FLAMA, sin cálculo)

# 6. Procesos FLAMA

Documentos de proceso del usuario: medidas y uniones de carros, numerado, encastre y bordoneado de manuales.

F38 · Proceso FLAMA de carros (documento del usuario)

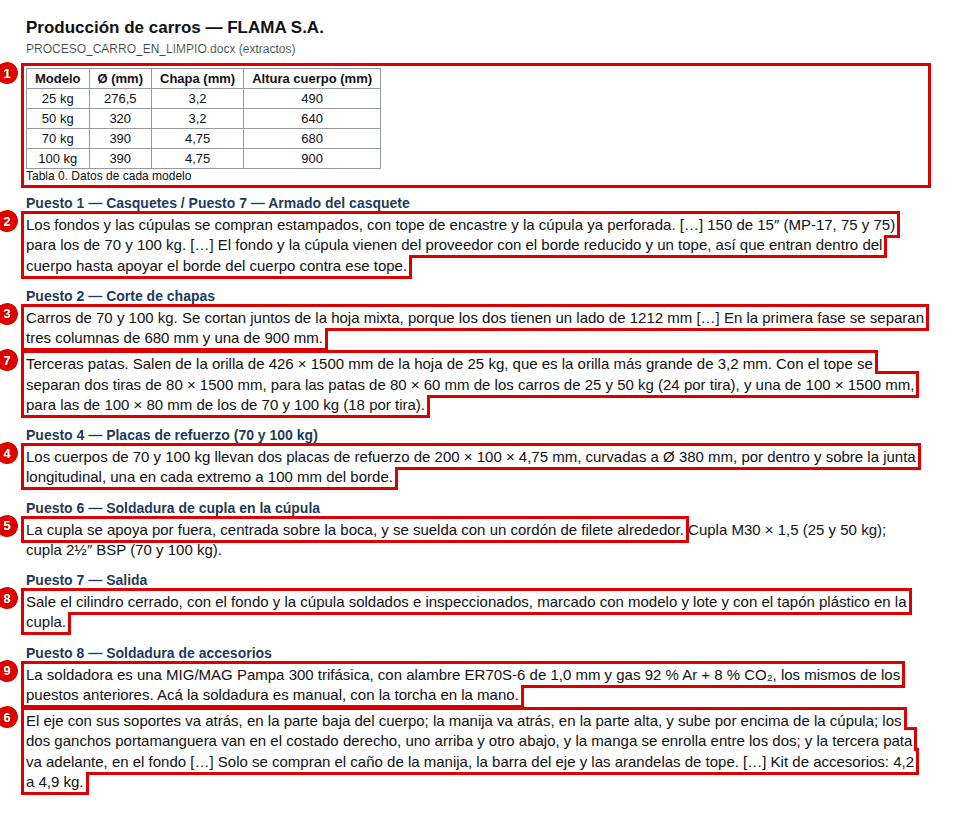
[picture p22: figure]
Proceso FLAMA de carros (documento del usuario)

Tabla 0; puestos 1, 2, 4, 6, 7 y 8

1 Tabla 0: Ø, chapa y alto del cuerpo de 25 / 50 / 70 / 100 kg · 2 Casquetes estampados con borde reducido y tope (15" para 70 y 100 kg) · 3 Hoja mixta 70 + 100 kg: lado de 1212, columnas de 680 y 900 · 4 Placas de refuerzo 200 × 100 × 4,75, Ø380, a 100 mm del borde · 5 Cupla apoyada por fuera y soldada con filete · 6 Accesorios soldados: eje con soportes y manija atrás, tercera pata adelante; los 2 ganchos y la manga, que el documento pone en el costado derecho, van adelante (corrección del usuario) · 7 Terceras patas 80 × 60 (25/50 kg) y 100 × 80 (70/100 kg) de la orilla de 3,2 de la hoja de 25 kg · 8 Cilindro cerrado marcado con modelo y lote y con tapón plástico en la cupla · 9 Soldadura de accesorios MIG/MAG manual, alambre ER70S-6 Ø1,0, gas 92 % Ar + 8 % CO₂

Nota: Documento del usuario (no es la fuente de verdad: se usa para el paso a paso y las medidas que fija).

F39 · Proceso FLAMA de manuales (documento del usuario)

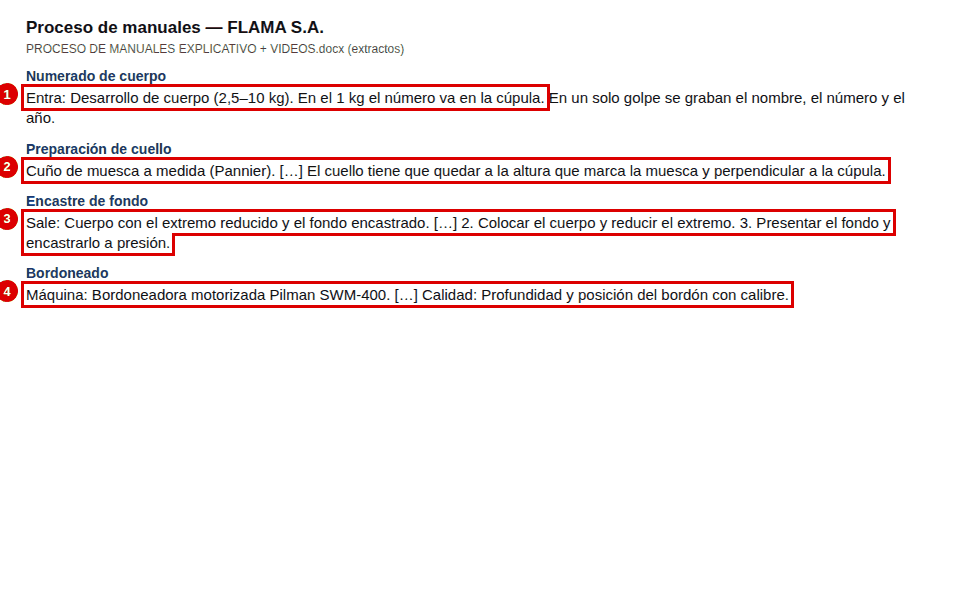
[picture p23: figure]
Proceso FLAMA de manuales (documento del usuario)

Preparación de cuello, numerado, encastre de fondo y bordoneado

1 Numerado en el cuerpo (desarrollo de 2,5-10 kg). El documento pone el del 1 kg en la cúpula; criterio FLAMA: va en el cuerpo en todos los modelos · 2 Muesca de altura en el cuello (prensa Pannier) · 3 Encastre: extremo del cuerpo reducido y fondo encastrado a presión · 4 Bordoneado: bordoneadora SWM-400; profundidad y posición del bordón

Nota: Documento del usuario (no es la fuente de verdad: se usa para el paso a paso y las medidas que fija).

# 7. Carro: portaeje, chapa, manija y lanza

Lo que los procesos no definen (el puesto 8.1 del proceso de carros está vacío): plano Fadesa del rodante de 800 mm (manija doblada 30°, pata afinada y soldada), foto del carro relevado (portaeje y chapa triangular) y las fotos que marcaste (soldadura de la barra lateral, altura del doblez y lanza con válvula esférica).

F41 · Plano Fadesa «Rodante 50kg 800mm R2» (código G692): vista lateral Página 1 (única): vista lateral, manija 1 Manija: tramo superior doblado 30° hacia atrás desde la altura de la cupla · 2 Extremo de la pata afinado (aplastado) y soldado al cuerpo Nota: Ángulo del tramo superior de la manija medido sobre el dibujo vectorial: 30.1° respecto de la vertical. El caño baja recto casi pegado al cuerpo y termina afinado (aplastado) contra la pared, donde se suelda; se dobla a la altura de la cupla. Fadesa además usa una oreja, que FLAMA no lleva (debilita la unión). | F42 · Carro relevado (foto enviada por el usuario) Vista trasera-lateral del tren rodante 1 Portaeje: caño cruzado atrás, con el eje de las ruedas adentro · 2 Chapa triangular soldada al cuerpo y al portaeje Nota: El eje pasa por un portaeje (caño) cruzado detrás del cuerpo, sostenido por chapas triangulares soldadas a la pared del recipiente.

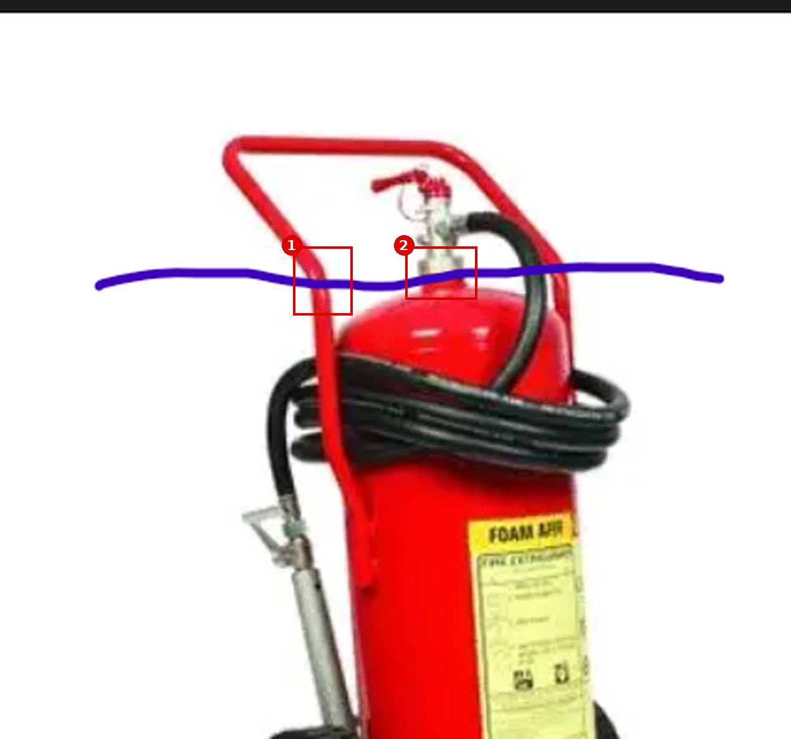
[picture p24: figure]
Carro AFFF marcado por el usuario: altura del doblez de 30°

F43 · Carro Elisam marcado por el usuario: soldadura de la barra lateral Costado del recipiente, debajo del hombro 1 Extremo de la barra afinado y soldado al cuerpo Nota: La barra lateral de la manija baja separada del cuerpo y su extremo se curva hacia la pared, se afina y se suelda directo al cuerpo (sin oreja). | F44 · Carro AFFF marcado por el usuario: altura del doblez de 30° Parte superior del carro 1 Doblez de la pata de la manija · 2 Base de la válvula (cupla): misma altura Nota: Las patas de la manija suben verticales y se doblan hacia atrás a la altura de la base de la válvula (línea azul del usuario).

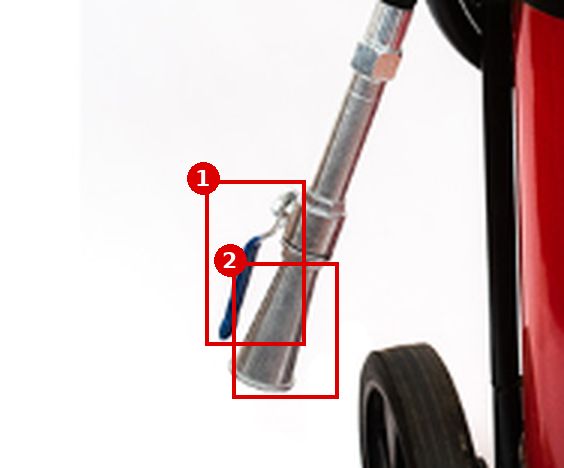
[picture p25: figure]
Lanza de carro con válvula esférica (foto del usuario)

F45 · Lanza de carro con válvula esférica (foto del usuario) Punta de la manga 1 Válvula esférica con palanca (empuñadura azul) · 2 Tobera cónica de salida Nota: Entre la manga y la tobera cónica va una válvula esférica con palanca de accionamiento.

# 7. Valores de diseño FLAMA (sin documento)

Línea exacta del generador de planos (commit d596f17). Amarillo = decisión de diseño a confirmar con el proveedor o el prototipo; naranja = a validar.

Id | Qué define | Criterio | Modelos | Código
D01 | Cuello roscado: Muesca de altura (ancho × prof. × alto) | El proceso pide la muesca (prensa Pannier) sin medidas: valor de diseño | 10 modelos | modelo3d.py:231 (https://github.com/TadeoSinay/planos_flama-/blob/d596f17/flama/modelo3d.py#L231)
D02 | Cuerpo de válvula: Fondo del cuerpo; Cuerpo de válvula: Salida a la manguera Ø × largo | No visible en la vista lateral Fadesa | ABC 1 kg | modelo3d.py:285 (https://github.com/TadeoSinay/planos_flama-/blob/d596f17/flama/modelo3d.py#L285)
D03 | Manómetro: Rango y sector verde | Rango ≈ 2,5 × presión de servicio (criterio); sello IRAM 3533 exigido en la compra | 15 modelos | bom.py:243 (https://github.com/TadeoSinay/planos_flama-/blob/d596f17/flama/bom.py#L243)
D04 | Eje de palanca: Ø × largo | Pasa por la oreja y la palanca en el agujero del plano Fadesa; Ø sin cota | 13 modelos | modelo3d.py:428 (https://github.com/TadeoSinay/planos_flama-/blob/d596f17/flama/modelo3d.py#L428)
D05 | Pasador de seguridad: Ø alambre × largo | Traba con anilla Ø18 y precinto (IRAM 3550 3.4.2) | los 17 | modelo3d.py:411 (https://github.com/TadeoSinay/planos_flama-/blob/d596f17/flama/modelo3d.py#L411)
D06 | Manija de accionamiento: Ancho (chapa estampada en U); Manija de transporte: Ancho (chapa estampada en U) | No visible en la vista lateral: a horcajadas del cuerpo (palanca) y de la palanca (manija) | 13 modelos | modelo3d.py:422 (https://github.com/TadeoSinay/planos_flama-/blob/d596f17/flama/modelo3d.py#L422)
D07 | Tobera: Boquilla Ø base / Ø punta × largo | F510: el plano Fadesa no muestra tobera aparte | ABC 1 kg | modelo3d.py:496 (https://github.com/TadeoSinay/planos_flama-/blob/d596f17/flama/modelo3d.py#L496)
D08 | Precinto de fábrica: Ø × largo | IRAM 3517-2 9.4.13 (precinto con id. del fabricante) | los 17 | modelo3d.py:1007 (https://github.com/TadeoSinay/planos_flama-/blob/d596f17/flama/modelo3d.py#L1007)
D09 | Cuerpo de válvula: Fondo del cuerpo | No visible en la vista lateral Fadesa | 12 modelos | modelo3d.py:289 (https://github.com/TadeoSinay/planos_flama-/blob/d596f17/flama/modelo3d.py#L289)
D10 | Cuerpo (virola): Espesor; Cúpula: Espesor; Fondo: Espesor | Inox 0,8 (≥ 0,63 mín. IRAM 3525 3.2.1 b) | AFFF 10 l, Agua 10 l, Sales K 6 l | catalogo.py:120 (https://github.com/TadeoSinay/planos_flama-/blob/d596f17/flama/catalogo.py#L120)
D11 | Cuello roscado: Ø exterior; Cuello roscado: Altura sobre la cúpula; Cuello roscado: Rosca; Cuello roscado: Ø del asiento | Supuesto de diseño | AFFF 10 l, Agua 10 l, Sales K 6 l | catalogo.py:81 (https://github.com/TadeoSinay/planos_flama-/blob/d596f17/flama/catalogo.py#L81)
D12 | Filtro del tubo de pesca: Envolvente L × A × H | Sólido dibujado | AFFF 10 l, Agua 10 l, Sales K 6 l | modelo3d.py:449 (https://github.com/TadeoSinay/planos_flama-/blob/d596f17/flama/modelo3d.py#L449)
D13 | Racor de manguera: Ø × largo | Sin cota en Fadesa | 10 modelos | modelo3d.py:527 (https://github.com/TadeoSinay/planos_flama-/blob/d596f17/flama/modelo3d.py#L527)
D14 | Manguera: Ø exterior | Sin cota en Fadesa | 5 modelos | modelo3d.py:462 (https://github.com/TadeoSinay/planos_flama-/blob/d596f17/flama/modelo3d.py#L462)
D15 | Tobera de chorro pleno: Ø mayor × largo; Lanza espumígena: Envolvente L × A × H; Lanza aplicadora clase K: Envolvente L × A × H; Brazo giratorio: Envolvente L × A × H (+3) | Ø de tobera por tipo; largo limitado por la altura disponible | 6 modelos | modelo3d.py:463 (https://github.com/TadeoSinay/planos_flama-/blob/d596f17/flama/modelo3d.py#L463)
D16 | Suncho portatobera: Fleje (alto × espesor) / Ø interior; Suncho soporte de difusor: Fleje (alto × espesor) / Ø interior | Banda que abraza el cuerpo por encima de las calcomanías (0,3 mm); 14,4 en el suncho portamanguera F674 del plano Fadesa | 5 modelos | modelo3d.py:579 (https://github.com/TadeoSinay/planos_flama-/blob/d596f17/flama/modelo3d.py#L579)
D17 | Neumático macizo: Ø interior del macizo; Rueda con cubierta neumática: Ø interior del macizo | 0,72 × Ø rueda | 5 modelos | modelo3d.py:659 (https://github.com/TadeoSinay/planos_flama-/blob/d596f17/flama/modelo3d.py#L659)
D18 | Llanta con cubo: Ø de la llanta | 0,72 × Ø rueda | 5 modelos | modelo3d.py:661 (https://github.com/TadeoSinay/planos_flama-/blob/d596f17/flama/modelo3d.py#L661)
D19 | Llanta con cubo: Espesor aro / disco | Chapa estampada; ajustado a la masa de los planos Fadesa | 5 modelos | modelo3d.py:660 (https://github.com/TadeoSinay/planos_flama-/blob/d596f17/flama/modelo3d.py#L660)
D20 | Llanta con cubo: Cubo Ø ext / Ø int | Cubo para eje Ø25 | 5 modelos | modelo3d.py:663 (https://github.com/TadeoSinay/planos_flama-/blob/d596f17/flama/modelo3d.py#L663)
D21 | Eje de ruedas: Ø × largo / posición | Barra SAE 1045 Ø25 comprada; recta, detrás de la pared trasera (luz 15) a la altura del centro de rueda; largo = trocha + banda + arandelas | 5 modelos | modelo3d.py:653 (https://github.com/TadeoSinay/planos_flama-/blob/d596f17/flama/modelo3d.py#L653)
D22 | Portaeje: Caño Ø × e × largo | Caño 1" comprado, cruzado detrás del cuerpo; el eje Ø25 pasa por dentro (Ø int. 27,2) y el caño llega a las arandelas interiores | 5 modelos | modelo3d.py:612 (https://github.com/TadeoSinay/planos_flama-/blob/d596f17/flama/modelo3d.py#L612)
D23 | Arandelas de tope (4): Ø ext × Ø int × e (4 u) | El proceso las compra; medidas de diseño | 5 modelos | modelo3d.py:613 (https://github.com/TadeoSinay/planos_flama-/blob/d596f17/flama/modelo3d.py#L613)
D24 | Chapas triangulares del portaeje (2): Chapa triangular: catetos × e (2 u) | Cateto vertical soldado a la pared trasera, cateto horizontal a la altura de la base del portaeje y punta redondeada que abraza el caño (carro relevado); chapa de orilla | 5 modelos | modelo3d.py:610 (https://github.com/TadeoSinay/planos_flama-/blob/d596f17/flama/modelo3d.py#L610)
D25 | Chapas triangulares del portaeje (2): Separación de las chapas | ± 0,7·R | 5 modelos | modelo3d.py:610 (https://github.com/TadeoSinay/planos_flama-/blob/d596f17/flama/modelo3d.py#L610)
D26 | Manija del carro: Caño; Manija del carro: Separación de las patas (ejes) / largo desarrollado | El proceso compra el caño de la manija | 5 modelos | modelo3d.py:614 (https://github.com/TadeoSinay/planos_flama-/blob/d596f17/flama/modelo3d.py#L614)
D27 | Manija del carro: Extremo aplastado: ancho × e × largo / transición | Sin orejas (una chapita con agujero debilita la unión: corrección del usuario): la punta del caño se aplasta en prensa antes de soldar y se suelda al cuerpo en todo su borde; ancho ≈ media vuelta del caño, e = 2 paredes + 1 | 5 modelos | modelo3d.py:615 (https://github.com/TadeoSinay/planos_flama-/blob/d596f17/flama/modelo3d.py#L615)
D28 | Manija del carro: Altura de la punta soldada | Por encima de la etiqueta (+20) y no menos del 45 % del cuerpo | 5 modelos | modelo3d.py:709 (https://github.com/TadeoSinay/planos_flama-/blob/d596f17/flama/modelo3d.py#L709)
D29 | Cuerpo de válvula: Fondo del cuerpo; Cuerpo de válvula: Salida a la manguera Ø × largo; Vástago: Vástago Ø × largo / asiento Ø; Resorte de válvula: Resorte Ø × largo libre (+1) | No visible en la vista lateral Fadesa | 4 modelos | modelo3d.py:293 (https://github.com/TadeoSinay/planos_flama-/blob/d596f17/flama/modelo3d.py#L293)
D30 | Palanca de accionamiento: Palanca largo × alto × espesor / empuñadura | Gira en la ranura de la horquilla (eje según X, plano Fadesa); hacia adelante (lado de la manga), 0,75·R; sin cota en Fadesa | 4 modelos | modelo3d.py:398 (https://github.com/TadeoSinay/planos_flama-/blob/d596f17/flama/modelo3d.py#L398)
D31 | Eje de palanca: Ø × largo | Tornillo F840 + buje + arandela del plano Fadesa, sin cota | 4 modelos | modelo3d.py:407 (https://github.com/TadeoSinay/planos_flama-/blob/d596f17/flama/modelo3d.py#L407)
D32 | Caño de pesca (sifón): Ø exterior | Sin cota en Fadesa | 7 modelos | modelo3d.py:482 (https://github.com/TadeoSinay/planos_flama-/blob/d596f17/flama/modelo3d.py#L482)
D33 | Ganchos portamanguera (2): Ancho × vuelo × labio × e (2 u) | Adelante (corrección del usuario al proceso, que decía costado derecho), arriba (90 %) y abajo (12 %) del cuerpo; vuelo = 2 Ø de manga + 10 | 5 modelos | modelo3d.py:618 (https://github.com/TadeoSinay/planos_flama-/blob/d596f17/flama/modelo3d.py#L618)
D34 | Manguera (tramo enrollado): Ø exterior; Manguera: Ø exterior | Sin cota en Fadesa | 5 modelos | modelo3d.py:637 (https://github.com/TadeoSinay/planos_flama-/blob/d596f17/flama/modelo3d.py#L637)
D35 | Válvula esférica: Cuerpo Ø × largo / palanca | Válvula esférica de paso total con palanca entre la manga y la tobera (foto del usuario); cerrada, la palanca queda atravesada al caño; comercial | 5 modelos | modelo3d.py:777 (https://github.com/TadeoSinay/planos_flama-/blob/d596f17/flama/modelo3d.py#L777)
D36 | Lanza espumígena: Ø × largo | Lanza espumígena de rodante | AFFF 50 l | modelo3d.py:793 (https://github.com/TadeoSinay/planos_flama-/blob/d596f17/flama/modelo3d.py#L793)
D37 | Cilindro sin costura: Espesor | Pared para presión de ensayo 25 MPa (supuesto) | CO2 2 kg, CO2 5 kg | catalogo.py:135 (https://github.com/TadeoSinay/planos_flama-/blob/d596f17/flama/catalogo.py#L135)
D38 | Disco de seguridad: Tapón hexagonal (entre caras × alto) | CO₂: disco de seguridad, rotura 18-21 MPa | CO2 2 kg, CO2 5 kg | modelo3d.py:368 (https://github.com/TadeoSinay/planos_flama-/blob/d596f17/flama/modelo3d.py#L368)
D39 | Pie de apoyo: Ø × alto | Ø del cilindro × 0,55·R | CO2 2 kg, CO2 5 kg | modelo3d.py:491 (https://github.com/TadeoSinay/planos_flama-/blob/d596f17/flama/modelo3d.py#L491)
D40 | Cúpula: Ø del disco (referencia; el casquete se compra embutido); Fondo: Ø del disco (referencia; el casquete se compra embutido) | Ø = 2·√(superficie media / π) × 1,03 (recorte de pestaña); la define Gockel | 4 modelos | bom.py:248 (https://github.com/TadeoSinay/planos_flama-/blob/d596f17/flama/bom.py#L248)
D41 | Tobera campana: Ø entrada / Ø boca × largo | Cono 16→34 de radio, 200 de largo | 4 modelos | modelo3d.py:804 (https://github.com/TadeoSinay/planos_flama-/blob/d596f17/flama/modelo3d.py#L804)

Justificación de medidas planos — FLAMA S.A. — pág. de

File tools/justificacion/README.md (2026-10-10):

# Justificación de medidas planos — herramientas

Genera `salida/justificacion/Justificacion de medidas planos.docx` (≈ 11 páginas) y `.xlsx` (matriz por familia).

| Paso | Archivo | Qué hace |
|---|---|---|
| 1 | `crudo.py` | Saca del modelo 3D cada dimensión de cada pieza de los 17 planos → `crudo.json` |
| 2 | `figs.py` | Marcas rojas numeradas sobre planos Fadesa, catálogo, fichas, normas, fotos y planilla MP → `figs/` + `figs.json` |
| 3 | `proc_figs.py` | Capturas marcadas de los procesos FLAMA de carros y de manuales (F38, F39) |
| 3b | `carro_figs.py` | Carro: plano Fadesa «Rodante 50kg 800mm R2» (manija doblada 30°, oreja) y foto del carro relevado (portaeje, chapa triangular) → F41, F42 |
| 4 | `compacto.py <sha>` | Une todo en `compacto.json`: fuente «F10·3» de cada valor, lista D01… de valores de diseño con link a la línea del commit `<sha>`, pendientes |
| 5 | `recorte.py` | Recorta cada captura a la zona de sus marcas (para el Word) |
| 6 | `xlsx_compacto.py` | Excel: hojas «Cómo leer», «Manuales ABC», «Rodantes ABC», «Revendidos» (pieza × modelo: valor + fuente, color por estado) y «Fuentes» |
| 7 | `word2.js` | Word con docx-js (`npm install docx`): capturas de a dos con sus marcas, pendientes y tabla de valores de diseño |

Colores (mismo criterio que el BOM): sin color = documento; amarillo = diseño FLAMA; naranja = a validar.

`figs/` tiene las capturas ya marcadas. Para volver a marcar desde cero, `figs.py` necesita las fuentes originales
(planos Fadesa, catálogo Fadesa 3, normas IRAM, Res. 522/07, Anexo R, fotos del relevamiento, planilla MP) y
`proc_figs.py` los dos documentos de proceso; no están en el repo (las normas no se suben). Ajustar las rutas `SP` /
`OUT` del principio de cada script a la máquina.

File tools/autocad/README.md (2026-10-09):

# DXF → DWG en AutoCAD

Los planos se generan como DXF R2018 (capas, tipos de línea, estilo de cotas FLAMA-IRAM, letra ISO3098 = isocpeur.ttf
y una presentación por lámina con su configuración de página). En la nube no hay AutoCAD ni convertidor ODA, así que
el DWG se saca en la PC:

1. Cerrar todos los dibujos y dejar uno nuevo vacío (el script usa SDI = 1).
2. Desde la raíz del repo: `python tools/autocad/armar_scr.py` (o `armar_scr.ps1` en PowerShell). Crea
   `salida/dxf_a_dwg.scr` con rutas absolutas y borra los DWG viejos.
3. En AutoCAD: `SCRIPT` → `salida/dxf_a_dwg.scr`. Por cada DXF: abre, `AUDIT` (corrige), `-PURGE` (dos pasadas) y
   `SAVEAS 2018` al lado del DXF. Al final vuelve SDI, FILEDIA y CMDDIA a 1 / 0 / 1.
4. Revisar uno por presentación (Hoja1… Hoja4) y subir los DWG al repo.

Alternativa sin AutoCAD: ODA File Converter (gratuito) — carpeta de entrada `salida`, salida `salida`, «ACAD2018 DWG»,
«Recurse folder» y «Audit each file».

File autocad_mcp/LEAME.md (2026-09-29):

# MCP de AutoCAD (local, Windows)

Servidor MCP propio que deja a Claude Code controlar tu AutoCAD 2027 por la API
COM oficial. Corre en tu PC; no manda nada a internet.

## Instalación (una vez)

En una terminal dentro de la carpeta del repo:

```bat
pip install -r autocad_mcp\requirements.txt
claude mcp add autocad -- python autocad_mcp\server.py
```

Reiniciá Claude Code y comprobá con `/mcp` que aparece **autocad** conectado.

## Herramientas (22)

| Grupo | Herramientas |
|---|---|
| Estado y archivos | `autocad_status`, `autocad_open_drawing`, `autocad_new_drawing`, `autocad_save_as`, `autocad_plot_pdf` |
| Consulta (solo lectura) | `autocad_list_layers`, `autocad_list_entities` (filtros + paginación), `autocad_mass_properties` |
| Dibujo 2D | `autocad_add_line`, `autocad_add_circle`, `autocad_add_text` |
| Sólidos 3D | `autocad_add_box`, `autocad_add_cylinder`, `autocad_add_revolved_solid` (perfil r-z girado sobre Z), `autocad_boolean`, `autocad_delete_entity` |
| Vista y comandos | `autocad_set_view`, `autocad_run_command` |
| Flujo FLAMA | `autocad_list_flama_models`, `autocad_open_flama_sheet`, `autocad_convert_flama_to_dwg`, `autocad_open_flama_3d` |

Cada herramienta declara si es de solo lectura o destructiva (anotaciones MCP),
valida sus parámetros y, si algo falla, devuelve el error con la acción sugerida.

`evaluacion.xml` tiene 10 preguntas de verificación con respuesta conocida para
comprobar que el MCP funciona de punta a punta con tu AutoCAD.

Después le podés pedir a Claude, por ejemplo: *"abrí el plano del ABC 10 kg en AutoCAD"*.

## Notas

- AutoCAD puede estar abierto o cerrado; si está cerrado lo inicia.
- `autocad_run_command` ejecuta comandos arbitrarios en AutoCAD: Claude Code te pedirá permiso
  en cada uso salvo que lo autorices.
- No fue probado contra un AutoCAD real desde el entorno donde se escribió; si una
  herramienta falla, el mensaje de error aparece en la respuesta.

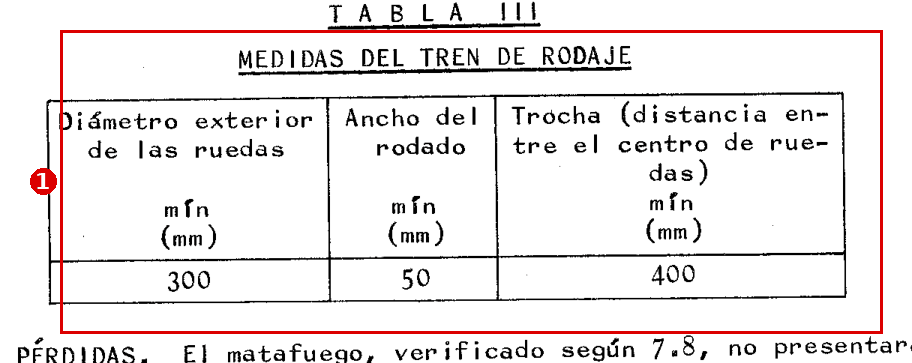
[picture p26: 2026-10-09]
tools/justificacion/figs/F40_c.png

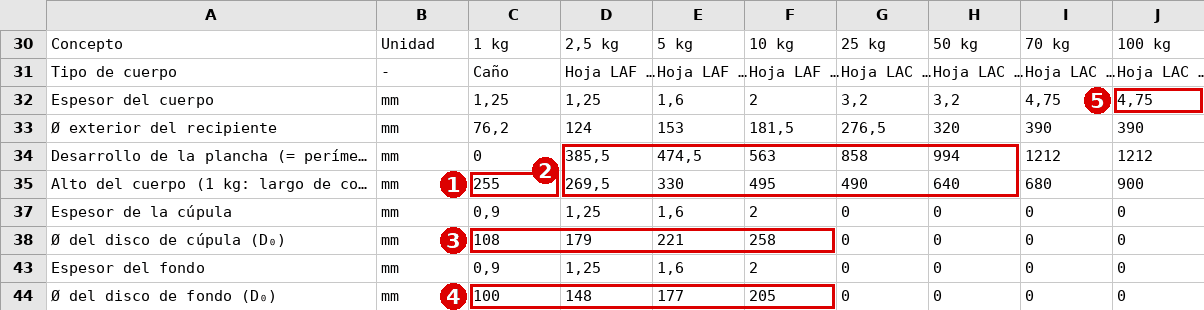
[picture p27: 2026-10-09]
tools/justificacion/figs/F36_c.png

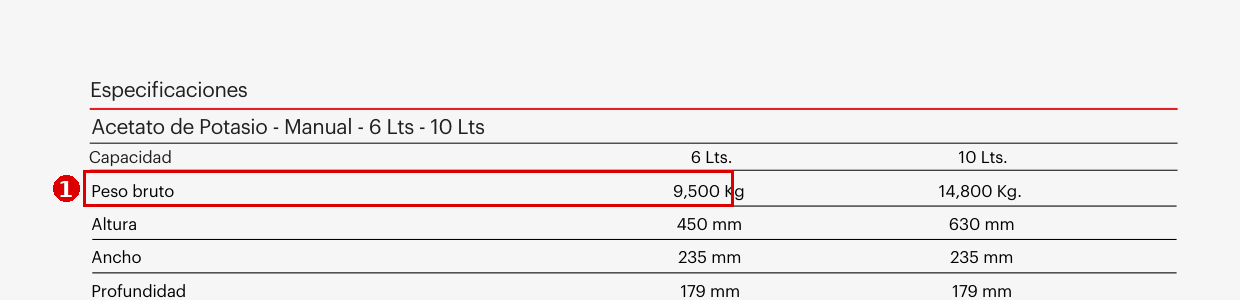
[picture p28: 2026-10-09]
tools/justificacion/figs/F25_c.png

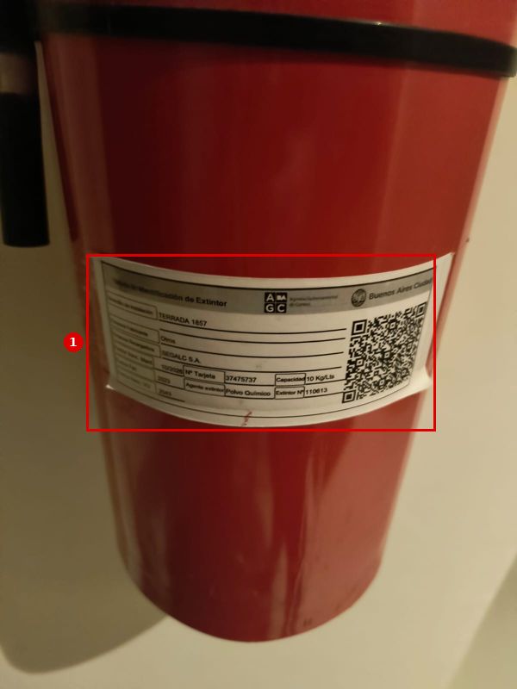
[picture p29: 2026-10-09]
tools/justificacion/figs/F31_c.jpg

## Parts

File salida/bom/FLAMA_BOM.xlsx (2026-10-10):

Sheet: 04_BOM_Matafuegos
BOM de matafuegos terminados FL_MAT (tabla plana filtrable)
Colores: | Validado |  | Estimado |  | A validar |  | No cumple o decisión pendiente
Producto | Nivel | Código | Descripción | Cant. | UM | Peso unit. (kg/UM) | Peso total (kg) | Material | Medida (mm) | Origen | Entra MRP | Proveedor principal | Alternativa | Operación / puesto (layout FLAMA) | Norma / referencia | Fte. | Plano | Observaciones
FL_MAT_ABC_1kg | 0 | FL_MAT_ABC_1kg | Extintor ABC 1 kg | 1 | u |  |  |  |  |  |  |  |  |  | IRAM 3523 | P | FL_MAT_ABC_1kg | Fabricación propia
FL_MAT_ABC_1kg | 1 | FL_REC_ABC_1kg | Recipiente (cilindro) | 1 | u |  |  |  |  | Fabricación |  |  |  |  | IRAM 3523 / 3550 (recipiente) | P | FL_REC_ABC_1kg
FL_MAT_ABC_1kg | 2 | ABC1-01 | Cuerpo (virola) | 1 | u | 0.607 |  | Caño c-c LF Ø76,2 e=1,25 (SAE 1010) | Ø76,2 × e1,25 × 263,4 de alto; desarrollo 235,5 × 263,4 | Fabricación | No |  |  | 5 Corte láser de caño (M15/M16) -> 2 numerado (en el cuerpo) -> 9 encastre -> 10 bordoneado (los dos extremos) |  | P | FL_DES_ABC_1kg | costura long. MAG
FL_MAT_ABC_1kg | 3 | MP-CANO | Caño Ø76,2 × 1,25 (tramo de barra de 6 m) | 0.0435 | barra | 14.288 |  | Caño acero SAE 1010 con costura | 255 mm por cuerpo; 23 cuerpos por barra (kg por barra) | Compra | Sí | Metalpri / Prilux | Comercial MID | AL-1T cantiléver |  | L | FL_PI_04 h2
FL_MAT_ABC_1kg | 2 | ABC1-02 | Cúpula | 1 | u | 0.034 |  | Chapa LAF IRAM-IAS U 500-05 e=0,9 | Ø76,2 × e0,9 × 12,1 de alto; disco Ø108 | Fabricación | No |  |  | 6 Desbobinado + embutido (M06-M08) |  | P | FL_DES_ABC_1kg | embutida
FL_MAT_ABC_1kg | 3 | MP-FLEJE | Fleje e=0,9 × 114 (paso 111) | 0.111 | m | 0.805 |  | Fleje SAE 1010 | disco Ø108 (kg por m de fleje) | Compra | Sí | Pacheco Chapas | Pradecon S.A. | AL-1F porta-flejes |  | L | FL_PI_04 h2
FL_MAT_ABC_1kg | 2 | ABC1-03 | Fondo | 1 | u | 0.066 |  | Chapa LAF IRAM-IAS U 500-05 e=1,25 | Ø76,2 × e1,25 × 22 de alto; disco Ø100 | Fabricación | No |  |  | 6 Desbobinado + embutido (M06-M08) |  | P | FL_DES_ABC_1kg | embutido
FL_MAT_ABC_1kg | 3 | MP-FLEJE | Fleje e=1,25 × 106 (paso 103) | 0.103 | m | 1.040 |  | Fleje SAE 1010 | disco Ø100 (kg por m de fleje) | Compra | Sí | Pacheco Chapas | Pradecon S.A. | AL-1F porta-flejes |  | L | FL_PI_04 h2
FL_MAT_ABC_1kg | 2 | ABC1-04 | Cuello roscado | 1 | u | 0.036 |  | Acero SAE 1010 | Ø29 × 12,5 de alto, rosca M22x1,5, asiento Ø26 | Compra (mecanizado, Eli-Met) | Sí | Eli-Met | - | Compra -> 8 soldadura de cuello |  | P | FL_DES_ABC_1kg | M22x1,5
FL_MAT_ABC_1kg | 2 | ABC1-C1 | Alambre MAG ER70S-6 Ø0,9 (AWS A5.18) | 0.0146 | kg | 0.950 |  | ER70S-6 | metal depositado de los cordones del plano 14 g / rendimiento 0,95 | Compra | Sí | Conarco (ESAB Argentina) | - | 4 sold. long. / 8 cuello / 11 circunferencial | IRAM 3523 3.2.4.2 · IRAM 3550 4.1.2 | C |  | Peso unit. = fracción que queda en la pieza (el resto es salpicadura). Depositado = volumen de los cordones del modelo × 7,85. Rendimiento de deposición del alambre macizo MAG 90-97 % (ESAB): se adopta 0,95. Medir en la prueba de soldadura del equipo (Getweld)
FL_MAT_ABC_1kg | 2 | ABC1-C2 | Gas de protección MAG Arcal 21 / ARCAL Speed (Ar + 8 % CO₂, M20) | 13.3 | L |  |  | EN ISO 14175 M20-ArC-8 | 14 L/min × 0,95 min de arco (cordones 570 mm: long. 0 + circ. 479 + cuello 91, a 600 mm/min) | Compra | Sí | Air Liquide Argentina - sucursal Piñeyro | Gogniat | Colector SC | IRAM 3523 3.2.4.2 · IRAM 3550 3.2.2.2 | C |  | Caudal 12-16 L/min para alambre 0,9-1,2 (Air Liquide; Ingemecánica): se adopta 14. Velocidad: Getweld 0-1500 mm/min; se adopta 600. Decisión FLAMA: MAG 135 con Arcal 21; la norma nombra «atmósfera inerte»: acreditar con el certificador en el ensayo de tipo. No incluye la soldadura del carro
FL_MAT_ABC_1kg | 2 | ABC1-C3 | Granalla de acero S330 / S390 (ISO 11124-3, SAE J444) | 0.08 | kg |  |  | Granalla esférica alto C | 0,073 m² a Sa 2½ (ISO 8501-1); 3,4 kg/h ÷ 42,5 u/h | Compra | Sí | CyM Materiales | Roca Ingeniería | 14 Granallado (B08) | DOC-01 | C |  | Consumo (desgaste) por turbina ≈ HP / 2 lb/h (The Fabricator, «aspectos básicos del granallado por turbina»): G-100 con 2 × 7,5 HP = 7,5 lb/h = 3,4 kg/h; ritmo 340 u por turno (Getweld) = 42,5 u/h. OJO: Ø76,2 fuera del rango de la Airblast G-100 (Ø80-200): definir soporte o equipo
FL_MAT_ABC_1kg | 2 | ABC1-C4 | Servicio de pintura en polvo al horno, rojo 03-1-050 | 1 | u |  |  | Servicio tercerizado | superficie exterior 0,073 m² | Compra (servicio) | Sí | Prymax | Pintor de carros (cotización por mensaje) | 17 Pintura tercerizada | IRAM 3523 5.3 / IRAM 3550 3.11 · IRAM 121 | Q |  | Q-PRYMAX (precio por cilindro); exigir informe de niebla salina del sistema de pintura; tercerización aceptada por el Ministerio (Res. 349/07 art. 18)
FL_MAT_ABC_1kg | 1 | ABC1-S2 | Conjunto de válvula | 1 | u |  |  |  |  | Compra / armado |  |  |  |  | Manómetro IRAM 3533 | P | FL_DES_ABC_1kg
FL_MAT_ABC_1kg | 2 | ABC1-05 | Espiga roscada | 1 | u | 0.012 |  | Latón forjado | 21 × 21 × 8,6 | Incluido en válvula HZ | No |  |  | 19 Ensamblaje de válvula (T03/T04) |  | P | FL_DES_ABC_1kg
FL_MAT_ABC_1kg | 2 | ABC1-06 | Collarín de válvula | 1 | u | 0.003 |  | Latón forjado | 19 × 19 × 3 | Incluido en válvula HZ | No |  |  | 19 Ensamblaje de válvula (T03/T04) |  | P | FL_DES_ABC_1kg
FL_MAT_ABC_1kg | 2 | ABC1-07 | Cuerpo de válvula | 1 | u | 0.093 |  | Latón forjado | 32,3 × 28 × 22,9 | Incluido en válvula HZ | No |  |  | 19 Ensamblaje de válvula (T03/T04) |  | P | FL_DES_ABC_1kg
FL_MAT_ABC_1kg | 2 | ABC1-08 | Manómetro | 1 | u |  |  | Comercial | Ø36 esfera, rango 0-3,5 MPa, sector verde en 1,4 | Compra | Sí | Yukon / MatafuegosYa S.R.L. | Matafuegos Iglesias | 19 Ensamblaje de válvula (T03/T04) | IRAM 3533 | P | FL_DES_ABC_1kg | Pieza comercial; sello IRAM 3533; peso: completar con la ficha del proveedor (no afecta el MRP)
FL_MAT_ABC_1kg | 2 | ABC1-09 | Vástago | 1 | u | 0.004 |  | Latón | 22,8 × 9 × 9 | Incluido en válvula HZ | No |  |  | 19 Ensamblaje de válvula (T03/T04) |  | P | FL_DES_ABC_1kg | con junta tórica
FL_MAT_ABC_1kg | 2 | ABC1-10 | Resorte de válvula | 1 | u | 0.002 |  | Alambre acero inox. AISI 302 | 19,9 × 9,8 × 9,8 | Incluido en válvula HZ | No |  |  | 19 Ensamblaje de válvula (T03/T04) |  | P | FL_DES_ABC_1kg | cierre del vástago
FL_MAT_ABC_1kg | 2 | ABC1-11 | Eje de palanca | 1 | u | 0.002 |  | Acero inox. AISI 304 | 29 × 3,6 × 3,6 | Incluido en válvula HZ | No |  |  | 19 Ensamblaje de válvula (T03/T04) |  | P | FL_DES_ABC_1kg
FL_MAT_ABC_1kg | 2 | ABC1-12 | Pasador de seguridad | 1 | u | 0.005 |  | Alambre acero inox. AISI 304 | 41,9 × 21 × 20,8 | Incluido en válvula HZ | No |  |  | 19 Ensamblaje de válvula (T03/T04) |  | P | FL_DES_ABC_1kg | con precinto
FL_MAT_ABC_1kg | 2 | ABC1-13 | Manija de accionamiento | 1 | u | 0.025 |  | Chapa acero SAE 1010 pintada | 67,1 × 27 × 11 | Incluido en válvula HZ | No |  |  | 19 Ensamblaje de válvula (T03/T04) |  | P | FL_DES_ABC_1kg
FL_MAT_ABC_1kg | 2 | ABC1-14 | Manija de transporte | 1 | u | 0.050 |  | Chapa acero SAE 1010 pintada | 91,7 × 60 × 31 | Incluido en válvula HZ | No |  |  | 19 Ensamblaje de válvula (T03/T04) |  | P | FL_DES_ABC_1kg
FL_MAT_ABC_1kg | 2 | ABC1-15 | Caño de pesca (sifón) | 1 | u | 0.023 |  | Tubo PVC rígido | Ø14,4 × 270,1 de largo | Incluido en válvula HZ | No |  |  | 19 Ensamblaje de válvula (T03/T04) |  | P | FL_DES_ABC_1kg
FL_MAT_ABC_1kg | 2 | ABC1-21 | Junta tórica de asiento | 1 | u | 0.001 |  | NBR 70 Shore A | Ø24 ext. × cordón 3 | Compra | Sí | Argensold | Matafuegos Iglesias | 19 Ensamblaje de válvula (T03/T04) |  | P | FL_DES_ABC_1kg | cambio c/recarga
FL_MAT_ABC_1kg | 2 | ABC1-K2 | Válvula HZ armada M-22 1 kg c/tubo de pesca plástico | 1 | u |  |  | Latón forjado (HZ) | rosca M22x1,5 | Compra | Sí | Polvex S.R.L. / Sancibrao | Mozart S.R.L. | 19 Ensamblaje de válvula | IRAM 3523 3.3 | Q | FL_DES_ABC_1kg | Lista de precios HZ (Q-AGENTES); plano Fadesa usa válvula HZ (R-FADESA). Trae las piezas marcadas «Incluido en válvula HZ»
FL_MAT_ABC_1kg | 2 | ABC1-V2 | Resorte de retorno del vástago | 1 | u |  |  | Acero para resortes | incluido en la válvula | Incluido en válvula HZ | No |  |  | 19 Ensamblaje |  | Q |  | Lista de precios HZ: válvula «c/resorte» (Q-AGENTES)
FL_MAT_ABC_1kg | 2 | ABC1-V3 | Junta tórica del vástago | 1 | u |  |  | NBR 70 Shore A | incluida en la válvula | Incluido en válvula HZ | No |  |  | 19 Ensamblaje |  | P |  | Figura en el plano como «vástago con junta tórica»
FL_MAT_ABC_1kg | 1 | ABC1-S3 | Dispositivo de descarga | 1 | u |  |  |  |  | Compra / armado |  |  |  |  |  | P | FL_DES_ABC_1kg
FL_MAT_ABC_1kg | 2 | ABC1-16 | Tobera | 1 | u | 0.001 |  | Polipropileno | 12 × 12 × 10 | Compra | Sí | Yukon / MatafuegosYa S.R.L. | Matafuegos Iglesias | 19 Ensamblaje (T03/T04) |  | P | FL_DES_ABC_1kg
FL_MAT_ABC_1kg | 1 | ABC1-S5 | Carga: agente extintor y gas impulsor | 1 | u |  |  |  |  | Carga en planta |  |  |  | 18 Carga de polvo (T01) / C8 (T02)
FL_MAT_ABC_1kg | 2 | ABC1-A1 | Polvo químico seco ABC 60 (Sello IRAM 3569) | 1.05 | kg | 1.000 |  | Polvo químico seco ABC 60 (Sello IRAM 3569) | nominal 1 kg; tolerancia 0 / +100 g (IRAM 3517-2:2020 tabla 3 · IRAM 3523 tabla II) | Compra | Sí | DEM S.A. (DEMSA) | Polvex S.R.L. / Sancibrao | SP-1 almacén previo a la carga | IRAM 3569 | N |  | Composición declarada del polvo ABC 60: MAP 60 % (IRAM 3569: 57-63 %) = 0,63 kg MAP + 0,389 kg sulfato de amonio + 0,032 kg aditivos · potencial de referencia 1A-5B:C (licencia Drago con DEM-60/90, L-DRAGO) · Decisión: DEMSA principal (sello IRAM 3569 y potencial de referencia); Polvex/Sancibrao alternativa sujeta a sello IRAM 3569 y ensayo de tipo de FLAMA (IRAM 3542/3543) · Lote único por extintor; prohibido mezclar ABC con BC (3517-2 9.9.1.6)
FL_MAT_ABC_1kg | 2 | ABC1-A2 | Gas impulsor: N₂ | 0.0047 | kg | 1.000 |  | N₂ | 3,7 L normales para 1,4 MPa a 20 °C en 0,27 dm³ libres | Compra | Sí | Air Liquide Argentina - sucursal Piñeyro | Gogniat | 20 Presurización (T05) / C10 | IRAM 3517-2 9.4.9 (tabla 2) · IRAM 3523 2.3 y 3.10 | C |  | N₂ ≥ 99,8 %, H₂O ≤ 40 ppm (Q-N2, Air Liquide) · volumen libre con ρ empacada mínima 1,1 kg/dm³ (NOM-104-STPS-2001); confirmar con descarga ≥ 85 % (IRAM 3523 4.9.1)
FL_MAT_ABC_1kg | 1 | ABC1-S6 | Identificación y precinto | 1 | u |  |  |  |  | Compra |  |  |  | 22 Etiquetado (T07)
FL_MAT_ABC_1kg | 2 | ABC1-17 | Etiqueta / placa de características | 1 | u | 0.010 |  | Vinilo autoadhesivo laminado | 168 × 137 (desarrollo × alto: panel central 108° + 2 alas laterales), e ≈ 0,3, laminado UV | Compra | Sí | Astuprint | Multilabel Argentina S.A. | 22 Etiquetado (T07) | IRAM 3534 · IRAM 3523 cap. 5 · relevamiento de mercado | P | FL_DES_ABC_1kg | IRAM 3534
FL_MAT_ABC_1kg | 2 | ABC1-18 | Oblea de fabricación (PBA) | 1 | u | 0.001 |  | Papel de seguridad autodestructible | Ø46 (Res. OPDS 522/07), numerada, autodestructible | Compra | Sí | Ministerio de Ambiente PBA (ex OPDS) | - | 22 Etiquetado (T07) | Res. OPDS 522/07 anexos 1, 2 y 6 | P | FL_DES_ABC_1kg | Res. 522/07
FL_MAT_ABC_1kg | 2 | ABC1-19 | Estampilla IRAM de conformidad | 1 | u | 0.001 |  | Provista por IRAM (Anexo R) | 60 × 40 | Compra | Sí | IRAM - Instituto Argentino de Normalización | - | 22 Etiquetado (T07) | IRAM Anexo R (DC-PG-129) | P | FL_DES_ABC_1kg | numerada
FL_MAT_ABC_1kg | 2 | ABC1-20 | Etiqueta de n° de serie GS1 | 1 | u | 0.001 |  | Poliéster autoadhesivo impreso térmico | 45 × 25 | Compra | Sí | Astuprint | GS1 Argentina | 22 Etiquetado (T07) | GS1 Argentina (GTIN 779) · trazabilidad IRAM 3523 5.1 | P | FL_DES_ABC_1kg | QR GTIN + serie
FL_MAT_ABC_1kg | 2 | ABC1-22 | Faja de garantía válvula-cuello | 1 | u | 0.0001 |  | Vinilo destructible rayado rojo/blanco | 17 × 20 (ancho × largo desarrollado), pegada sobre la unión: cuerpo de la válvula, tuerca y cuello | Compra | Sí | Astuprint | Multilabel Argentina S.A. | 22 Etiquetado (T07) | Sin norma: práctica de mercado (garantía de fábrica) | P | FL_DES_ABC_1kg | nuevo sin abrir
FL_MAT_ABC_1kg | 2 | ABC1-23 | Precinto de fábrica | 1 | u | 0.0002 |  | Polipropileno color | Ø5 × 10, numerado, rotura 30-50 N | Compra | Sí | SonFuertes (vía Papelera Damián) | Precinter S.R.L. | 20 Presurización (T05) | IRAM 3523 3.3.2 · IRAM 3517-2:2020 9.4.13 | P | FL_DES_ABC_1kg | id. FLAMA y lote
FL_MAT_ABC_1kg | 1 | ABC1-S8 | Soporte (accesorio de montaje) | 1 | u |  |  |  |  | Compra |  |  |  | 23 Embalaje (va dentro de la caja) | IRAM 3517-2 7.4
FL_MAT_ABC_1kg | 2 | ABC1-I7 | Soporte vehicular con cierre rápido (FL_ACC_02) | 1 | u | 0.631 |  | Chapa acero SAE 1010 e=2,5 pintada | base 80 de ancho, 2 aros con hebilla | Compra | Sí | Maxiseguridad | CM Representaciones | 23 Embalaje | IRAM 3517-2 7.4 | P | FL_ACC_02
FL_MAT_ABC_1kg | 1 | ABC1-S7 | Embalaje | 1 | u |  |  |  |  | Compra |  |  |  | 23 Embalaje -> 24 envolvedora (T11)
FL_MAT_ABC_1kg | 2 | ABC1-E1 | Caja de cartón corrugado simple | 1 | u |  |  | Cartón corrugado | 160 × 107 × 347 interior (envolvente del plano + 15 por lado) | Compra | Sí | Maxipack | Cartocan | 23 Embalaje |  | P |  | Medida del plano
FL_MAT_ABC_1kg | 2 | ABC1-E2 | Instructivo de uso y mantenimiento | 1 | u |  |  | Papel | A5 | Compra | Sí | Astuprint | - | 23 Embalaje |  | I |  | Decisión comercial de FLAMA (las instrucciones de uso obligatorias van en la etiqueta, IRAM 3534)
FL_MAT_ABC_1kg | 2 | ABC1-E3 | Pallet 1200 × 1000 (fracción) | 0.0038 | u |  |  | Madera | 264 u por pallet | Compra | Sí | IndusPallets | - | 23 Embalaje |  | C |  | u por pallet = acomodo de la caja (plano) en 1200 × 1000 × 1450 de alto
FL_MAT_ABC_1kg | 2 | ABC1-E4 | Film stretch (fracción del pallet) | 0.0005 | kg | 1.000 |  | PE lineal 23 µm | 0,12 kg por pallet / 264 u | Compra | Sí | MV Embalajes | Embalpack | 24 Envolvedora (T11) |  | C |  | Perímetro del pallet 4,4 m × 9 vueltas = 40 m aplicados; con pre-estirado 250 % (1 m de bobina = 3,5 m aplicados) = 11,4 m de bobina × 0,5 m × 23 µm × 0,92 g/cm³ = 0,12 kg. Fuentes: fichas de film 23 µm × 500 mm (MV Embalajes / Embalpack) y pre-estirado de la envolvedora. Medir en la puesta en marcha
FL_MAT_ABC_1kg | 2 | ABC1-E5 | Etiqueta de pallet (lote y destino, fracción) | 0.0038 | u |  |  | Papel térmico | 100 × 150 | Compra | Sí | Astuprint | Multilabel Argentina S.A. | 24 Envolvedora |  | C
FL_MAT_ABC_1kg | 2 | ABC1-E6 | Cinta de embalaje PP 48 mm (cierre de la caja) | 0.6 | m |  |  | Polipropileno con adhesivo acrílico | cierre en I arriba y abajo: 2 × (160 + 2 × 70 de solapa) | Compra | Sí | MV Embalajes | Embalpack | 23 Embalaje |  | C |  | Solapa de 70 mm por lado: práctica de cierre de cajas (medir en la línea)
FL_MAT_ABC_1kg | 2 | ABC1-E7 | Esquineros de cartón 50 × 50 × 1200 (fracción del pallet) | 0.0152 | u |  |  | Cartón | 4 por pallet / 264 u | Compra | Sí | Maxipack | Cartocan | 24 Envolvedora (T11) |  | C |  | Planilla MP-64
FL_MAT_ABC_2.5kg | 0 | FL_MAT_ABC_2.5kg | Extintor ABC 2,5 kg | 1 | u |  |  |  |  |  |  |  |  |  | IRAM 3523 | P | FL_MAT_ABC_2.5kg | Fabricación propia
FL_MAT_ABC_2.5kg | 1 | FL_REC_ABC_2.5kg | Recipiente (cilindro) | 1 | u |  |  |  |  | Fabricación |  |  |  |  | IRAM 3523 / 3550 (recipiente) | P | FL_REC_ABC_2.5kg
FL_MAT_ABC_2.5kg | 2 | ABC2.5-01 | Cuerpo (virola) | 1 | u | 1.011 |  | Chapa LAF IRAM-IAS U 500-05 e=1,25 | Ø124 × e1,25 × 267,4 de alto; desarrollo 385,6 × 267,4 | Fabricación | No |  |  | 1 Guillotina -> 2 numerado -> 3 cilindrado -> 4 soldadura longitudinal -> 9 encastre del fondo -> 10 bordoneado |  | P | FL_DES_ABC_2.5kg | costura long. MAG
FL_MAT_ABC_2.5kg | 3 | MP-HOJA | Recorte de hoja LAF 1220 × 2440 e=1,25 | 1 | u | 1.082 |  | Chapa LAF IRAM-IAS U 500-05 LAF | 385,5 × 269,5 (aprovech. 94,2 %) | Compra | Sí | Pradecon S.A. | Pacheco Chapas | AL-1H paquetes de hojas |  | L | FL_PI_04 h2
FL_MAT_ABC_2.5kg | 2 | ABC2.5-02 | Cúpula | 1 | u | 0.173 |  | Chapa LAF IRAM-IAS U 500-05 e=1,25 | Ø124 × e1,25 × 38,1 de alto; disco Ø179 | Fabricación | No |  |  | 6 Desbobinado + embutido (M06-M08) |  | P | FL_DES_ABC_2.5kg | embutida
FL_MAT_ABC_2.5kg | 3 | MP-FLEJE | Fleje e=1,25 × 200 (paso 182) | 0.182 | m | 1.962 |  | Fleje SAE 1010 | disco Ø179 (kg por m de fleje) | Compra | Sí | Pacheco Chapas | Pradecon S.A. | AL-1F porta-flejes |  | L | FL_PI_04 h2
FL_MAT_ABC_2.5kg | 2 | ABC2.5-03 | Fondo | 1 | u | 0.166 |  | Chapa LAF IRAM-IAS U 500-05 e=1,25 | Ø124 × e1,25 × 20,5 de alto; disco Ø148 | Fabricación | No |  |  | 6 Desbobinado + embutido (M06-M08) |  | P | FL_DES_ABC_2.5kg | embutido
FL_MAT_ABC_2.5kg | 3 | MP-FLEJE | Fleje e=1,25 × 200 (paso 151) | 0.151 | m | 1.962 |  | Fleje SAE 1010 | disco Ø148 (kg por m de fleje) | Compra | Sí | Pacheco Chapas | Pradecon S.A. | AL-1F porta-flejes |  | L | FL_PI_04 h2
FL_MAT_ABC_2.5kg | 2 | ABC2.5-04 | Cuello roscado | 1 | u | 0.054 |  | Acero SAE 1010 | Ø37 × 14 de alto, rosca M30x1,5, asiento Ø35 | Compra (mecanizado, Eli-Met) | Sí | Eli-Met | - | Compra -> 8 soldadura de cuello |  | P | FL_DES_ABC_2.5kg | M30x1,5
FL_MAT_ABC_2.5kg | 2 | ABC2.5-C1 | Alambre MAG ER70S-6 Ø0,9 (AWS A5.18) | 0.0292 | kg | 0.950 |  | ER70S-6 | metal depositado de los cordones del plano 28 g / rendimiento 0,95 | Compra | Sí | Conarco (ESAB Argentina) | - | 4 sold. long. / 8 cuello / 11 circunferencial | IRAM 3523 3.2.4.2 · IRAM 3550 4.1.2 | C |  | Peso unit. = fracción que queda en la pieza (el resto es salpicadura). Depositado = volumen de los cordones del modelo × 7,85. Rendimiento de deposición del alambre macizo MAG 90-97 % (ESAB): se adopta 0,95. Medir en la prueba de soldadura del equipo (Getweld)
FL_MAT_ABC_2.5kg | 2 | ABC2.5-C2 | Gas de protección MAG Arcal 21 / ARCAL Speed (Ar + 8 % CO₂, M20) | 27.1 | L |  |  | EN ISO 14175 M20-ArC-8 | 14 L/min × 1,94 min de arco (cordones 1.163 mm: long. 267 + circ. 779 + cuello 116, a 600 mm/min) | Compra | Sí | Air Liquide Argentina - sucursal Piñeyro | Gogniat | Colector SC | IRAM 3523 3.2.4.2 · IRAM 3550 3.2.2.2 | C |  | Caudal 12-16 L/min para alambre 0,9-1,2 (Air Liquide; Ingemecánica): se adopta 14. Velocidad: Getweld 0-1500 mm/min; se adopta 600. Decisión FLAMA: MAG 135 con Arcal 21; la norma nombra «atmósfera inerte»: acreditar con el certificador en el ensayo de tipo. No incluye la soldadura del carro
FL_MAT_ABC_2.5kg | 2 | ABC2.5-C3 | Granalla de acero S330 / S390 (ISO 11124-3, SAE J444) | 0.08 | kg |  |  | Granalla esférica alto C | 0,138 m² a Sa 2½ (ISO 8501-1); 3,4 kg/h ÷ 42,5 u/h | Compra | Sí | CyM Materiales | Roca Ingeniería | 14 Granallado (B08) | DOC-01 | C |  | Consumo (desgaste) por turbina ≈ HP / 2 lb/h (The Fabricator, «aspectos básicos del granallado por turbina»): G-100 con 2 × 7,5 HP = 7,5 lb/h = 3,4 kg/h; ritmo 340 u por turno (Getweld) = 42,5 u/h.
FL_MAT_ABC_2.5kg | 2 | ABC2.5-C4 | Servicio de pintura en polvo al horno, rojo 03-1-050 | 1 | u |  |  | Servicio tercerizado | superficie exterior 0,138 m² | Compra (servicio) | Sí | Prymax | Pintor de carros (cotización por mensaje) | 17 Pintura tercerizada | IRAM 3523 5.3 / IRAM 3550 3.11 · IRAM 121 | Q |  | Q-PRYMAX (precio por cilindro); exigir informe de niebla salina del sistema de pintura; tercerización aceptada por el Ministerio (Res. 349/07 art. 18)
FL_MAT_ABC_2.5kg | 1 | ABC2.5-S2 | Conjunto de válvula | 1 | u |  |  |  |  | Compra / armado |  |  |  |  | Manómetro IRAM 3533 | P | FL_DES_ABC_2.5kg
FL_MAT_ABC_2.5kg | 2 | ABC2.5-05 | Espiga roscada | 1 | u | 0.025 |  | Latón forjado | 29,8 × 29,8 × 10,8 | Incluido en válvula HZ | No |  |  | 19 Ensamblaje de válvula (T03/T04) |  | P | FL_DES_ABC_2.5kg
FL_MAT_ABC_2.5kg | 2 | ABC2.5-06 | Collarín de válvula | 1 | u | 0.005 |  | Latón forjado | 27,2 × 27,2 × 4,1 | Incluido en válvula HZ | No |  |  | 19 Ensamblaje de válvula (T03/T04) |  | P | FL_DES_ABC_2.5kg
FL_MAT_ABC_2.5kg | 2 | ABC2.5-07 | Cuerpo de válvula | 1 | u | 0.133 |  | Latón forjado | 43,9 × 32 × 24,5 | Incluido en válvula HZ | No |  |  | 19 Ensamblaje de válvula (T03/T04) |  | P | FL_DES_ABC_2.5kg
FL_MAT_ABC_2.5kg | 2 | ABC2.5-08 | Manómetro | 1 | u |  |  | Comercial | Ø36 esfera, rango 0-3,5 MPa, sector verde en 1,4 | Compra | Sí | Yukon / MatafuegosYa S.R.L. | Matafuegos Iglesias | 19 Ensamblaje de válvula (T03/T04) | IRAM 3533 | P | FL_DES_ABC_2.5kg | Pieza comercial; sello IRAM 3533; peso: completar con la ficha del proveedor (no afecta el MRP)
FL_MAT_ABC_2.5kg | 2 | ABC2.5-09 | Vástago | 1 | u | 0.014 |  | Latón | 35,6 × 14 × 14 | Incluido en válvula HZ | No |  |  | 19 Ensamblaje de válvula (T03/T04) |  | P | FL_DES_ABC_2.5kg | con junta tórica
FL_MAT_ABC_2.5kg | 2 | ABC2.5-10 | Resorte de válvula | 1 | u | 0.005 |  | Alambre acero inox. AISI 302 | 28,8 × 17,3 × 17,3 | Incluido en válvula HZ | No |  |  | 19 Ensamblaje de válvula (T03/T04) |  | P | FL_DES_ABC_2.5kg | cierre del vástago
FL_MAT_ABC_2.5kg | 2 | ABC2.5-11 | Eje de palanca | 1 | u | 0.003 |  | Acero inox. AISI 304 | 33 × 4 × 4 | Incluido en válvula HZ | No |  |  | 19 Ensamblaje de válvula (T03/T04) |  | P | FL_DES_ABC_2.5kg
FL_MAT_ABC_2.5kg | 2 | ABC2.5-12 | Pasador de seguridad | 1 | u | 0.005 |  | Alambre acero inox. AISI 304 | 45,9 × 21 × 20,8 | Incluido en válvula HZ | No |  |  | 19 Ensamblaje de válvula (T03/T04) |  | P | FL_DES_ABC_2.5kg | con precinto
FL_MAT_ABC_2.5kg | 2 | ABC2.5-13 | Manija de accionamiento | 1 | u | 0.096 |  | Chapa acero SAE 1010 pintada | 124,6 × 31 × 29,3 | Incluido en válvula HZ | No |  |  | 19 Ensamblaje de válvula (T03/T04) |  | P | FL_DES_ABC_2.5kg
FL_MAT_ABC_2.5kg | 2 | ABC2.5-14 | Manija de transporte | 1 | u | 0.076 |  | Chapa acero SAE 1010 pintada | 102,6 × 35 × 25,4 | Incluido en válvula HZ | No |  |  | 19 Ensamblaje de válvula (T03/T04) |  | P | FL_DES_ABC_2.5kg
FL_MAT_ABC_2.5kg | 2 | ABC2.5-15 | Caño de pesca (sifón) | 1 | u | 0.036 |  | Tubo PVC rígido | Ø21,3 × 277,9 de largo | Incluido en válvula HZ | No |  |  | 19 Ensamblaje de válvula (T03/T04) |  | P | FL_DES_ABC_2.5kg
FL_MAT_ABC_2.5kg | 2 | ABC2.5-25 | Junta tórica de asiento | 1 | u | 0.001 |  | NBR 70 Shore A | Ø32,8 ext. × cordón 3 | Compra | Sí | Argensold | Matafuegos Iglesias | 19 Ensamblaje de válvula (T03/T04) |  | P | FL_DES_ABC_2.5kg | cambio c/recarga
FL_MAT_ABC_2.5kg | 2 | ABC2.5-K2 | Válvula HZ armada M-30 c/resorte y tubo 7/8 | 1 | u |  |  | Latón forjado (HZ) | rosca M30x1,5 | Compra | Sí | Polvex S.R.L. / Sancibrao | Mozart S.R.L. | 19 Ensamblaje de válvula | IRAM 3523 3.3 | Q | FL_DES_ABC_2.5kg | Lista de precios HZ (Q-AGENTES); plano Fadesa usa válvula HZ (R-FADESA). Trae las piezas marcadas «Incluido en válvula HZ»
FL_MAT_ABC_2.5kg | 2 | ABC2.5-V2 | Resorte de retorno del vástago | 1 | u |  |  | Acero para resortes | incluido en la válvula | Incluido en válvula HZ | No |  |  | 19 Ensamblaje |  | Q |  | Lista de precios HZ: válvula «c/resorte» (Q-AGENTES)
FL_MAT_ABC_2.5kg | 2 | ABC2.5-V3 | Junta tórica del vástago | 1 | u |  |  | NBR 70 Shore A | incluida en la válvula | Incluido en válvula HZ | No |  |  | 19 Ensamblaje |  | P |  | Figura en el plano como «vástago con junta tórica»
FL_MAT_ABC_2.5kg | 1 | ABC2.5-S3 | Dispositivo de descarga | 1 | u |  |  |  |  | Compra / armado |  |  |  |  |  | P | FL_DES_ABC_2.5kg
FL_MAT_ABC_2.5kg | 2 | ABC2.5-16 | Racor de manguera | 1 | u | 0.039 |  | Latón | 19,4 × 18,8 × 18,8 | Compra | Sí | Yukon / MatafuegosYa S.R.L. | Matafuegos Iglesias | 19 Ensamblaje (T03/T04) |  | P | FL_DES_ABC_2.5kg
FL_MAT_ABC_2.5kg | 2 | ABC2.5-17 | Manguera | 1 | u | 0.037 |  | Caucho sintético | Ø16 × 238 de largo desarrollado | Compra | Sí | Yukon / MatafuegosYa S.R.L. | Matafuegos Iglesias | 19 Ensamblaje (T03/T04) |  | P | FL_DES_ABC_2.5kg
FL_MAT_ABC_2.5kg | 2 | ABC2.5-18 | Tobera con portatobera | 1 | u | 0.017 |  | Polipropileno | 73,5 × 19,9 × 19,9 | Compra | Sí | Yukon / MatafuegosYa S.R.L. | Matafuegos Iglesias | 19 Ensamblaje (T03/T04) |  | P | FL_DES_ABC_2.5kg
FL_MAT_ABC_2.5kg | 2 | ABC2.5-19 | Suncho portatobera | 1 | u | 0.079 |  | Fleje acero SAE 1010 pintado | 137,6 × 127,6 × 14,4 | Compra (estructura) | Sí | Yukon / MatafuegosYa S.R.L. | Matafuegos Iglesias | 19 Ensamblaje (T03/T04) |  | P | FL_DES_ABC_2.5kg
FL_MAT_ABC_2.5kg | 1 | ABC2.5-S5 | Carga: agente extintor y gas impulsor | 1 | u |  |  |  |  | Carga en planta |  |  |  | 18 Carga de polvo (T01) / C8 (T02)
FL_MAT_ABC_2.5kg | 2 | ABC2.5-A1 | Polvo químico seco ABC 60 (Sello IRAM 3569) | 2.55 | kg | 1.000 |  | Polvo químico seco ABC 60 (Sello IRAM 3569) | nominal 2,5 kg; tolerancia 0 / +100 g (IRAM 3517-2:2020 tabla 3 · IRAM 3523 tabla II) | Compra | Sí | DEM S.A. (DEMSA) | Polvex S.R.L. / Sancibrao | SP-1 almacén previo a la carga | IRAM 3569 | N |  | Composición declarada del polvo ABC 60: MAP 60 % (IRAM 3569: 57-63 %) = 1,53 kg MAP + 0,943 kg sulfato de amonio + 0,076 kg aditivos · potencial de referencia 3A-20B:C (licencia Drago con DEM-60/90, L-DRAGO) · Decisión: DEMSA principal (sello IRAM 3569 y potencial de referencia); Polvex/Sancibrao alternativa sujeta a sello IRAM 3569 y ensayo de tipo de FLAMA (IRAM 3542/3543) · Lote único por extintor; prohibido mezclar ABC con BC (3517-2 9.9.1.6)
FL_MAT_ABC_2.5kg | 2 | ABC2.5-A2 | Gas impulsor: N₂ | 0.0212 | kg | 1.000 |  | N₂ | 16,9 L normales para 1,4 MPa a 20 °C en 1,23 dm³ libres | Compra | Sí | Air Liquide Argentina - sucursal Piñeyro | Gogniat | 20 Presurización (T05) / C10 | IRAM 3517-2 9.4.9 (tabla 2) · IRAM 3523 2.3 y 3.10 | C |  | N₂ ≥ 99,8 %, H₂O ≤ 40 ppm (Q-N2, Air Liquide) · volumen libre con ρ empacada mínima 1,1 kg/dm³ (NOM-104-STPS-2001); confirmar con descarga ≥ 85 % (IRAM 3523 4.9.1)
FL_MAT_ABC_2.5kg | 1 | ABC2.5-S6 | Identificación y precinto | 1 | u |  |  |  |  | Compra |  |  |  | 22 Etiquetado (T07)
FL_MAT_ABC_2.5kg | 2 | ABC2.5-20 | Etiqueta / placa de características | 1 | u | 0.015 |  | Vinilo autoadhesivo laminado | 234 × 152 (desarrollo × alto: panel central 108° + 2 alas laterales), e ≈ 0,3, laminado UV | Compra | Sí | Astuprint | Multilabel Argentina S.A. | 22 Etiquetado (T07) | IRAM 3534 · IRAM 3523 cap. 5 · relevamiento de mercado | P | FL_DES_ABC_2.5kg | IRAM 3534
FL_MAT_ABC_2.5kg | 2 | ABC2.5-21 | Oblea de fabricación (PBA) | 1 | u | 0.001 |  | Papel de seguridad autodestructible | Ø46 (Res. OPDS 522/07), numerada, autodestructible | Compra | Sí | Ministerio de Ambiente PBA (ex OPDS) | - | 22 Etiquetado (T07) | Res. OPDS 522/07 anexos 1, 2 y 6 | P | FL_DES_ABC_2.5kg | Res. 522/07
FL_MAT_ABC_2.5kg | 2 | ABC2.5-22 | Estampilla IRAM de conformidad | 1 | u | 0.001 |  | Provista por IRAM (Anexo R) | 60 × 40 | Compra | Sí | IRAM - Instituto Argentino de Normalización | - | 22 Etiquetado (T07) | IRAM Anexo R (DC-PG-129) | P | FL_DES_ABC_2.5kg | numerada
FL_MAT_ABC_2.5kg | 2 | ABC2.5-23 | Tarjeta de identificación AGC (CABA) | 1 | u | 0.003 |  | Etiqueta autoadhesiva emitida por la AGC | 140 × 55 | Compra | Sí | Agencia Gubernamental de Control (CABA) | - | 22 Etiquetado (T07) | Ordenanza 40.473 art. 6 · Res. AGC 32/15 | P | FL_DES_ABC_2.5kg | sólo destino CABA
FL_MAT_ABC_2.5kg | 2 | ABC2.5-24 | Etiqueta de n° de serie GS1 | 1 | u | 0.001 |  | Poliéster autoadhesivo impreso térmico | 45 × 25 | Compra | Sí | Astuprint | GS1 Argentina | 22 Etiquetado (T07) | GS1 Argentina (GTIN 779) · trazabilidad IRAM 3523 5.1 | P | FL_DES_ABC_2.5kg | QR GTIN + serie
FL_MAT_ABC_2.5kg | 2 | ABC2.5-26 | Faja de garantía válvula-cuello | 1 | u | 0.0001 |  | Vinilo destructible rayado rojo/blanco | 22 × 22 (ancho × largo desarrollado), pegada sobre la unión: cuerpo de la válvula, tuerca y cuello | Compra | Sí | Astuprint | Multilabel Argentina S.A. | 22 Etiquetado (T07) | Sin norma: práctica de mercado (garantía de fábrica) | P | FL_DES_ABC_2.5kg | nuevo sin abrir
FL_MAT_ABC_2.5kg | 2 | ABC2.5-27 | Precinto de fábrica | 1 | u | 0.0002 |  | Polipropileno color | Ø5 × 10, numerado, rotura 30-50 N | Compra | Sí | SonFuertes (vía Papelera Damián) | Precinter S.R.L. | 20 Presurización (T05) | IRAM 3523 3.3.2 · IRAM 3517-2:2020 9.4.13 | P | FL_DES_ABC_2.5kg | id. FLAMA y lote
FL_MAT_ABC_2.5kg | 1 | ABC2.5-S8 | Soporte (accesorio de montaje) | 1 | u |  |  |  |  | Compra |  |  |  | 23 Embalaje (va dentro de la caja) | IRAM 3517-2 7.4
FL_MAT_ABC_2.5kg | 2 | ABC2.5-I5 | Soporte de pared (FL_ACC_01) | 1 | u | 0.264 |  | Chapa acero SAE 1010 e=2 pintada | placa 60 × 180, ala con ranura Ø cuello + 3 | Compra | Sí | Maxiseguridad | CM Representaciones | 23 Embalaje | IRAM 3517-2 7.4 | P | FL_ACC_01
FL_MAT_ABC_2.5kg | 2 | ABC2.5-I6 | Tornillo y tarugo de fijación | 2 | u |  |  | Acero cincado / nylon | 2 agujeros Ø8,5 del plano FL_ACC_01 → tornillo M8 + tarugo | Compra | Sí | Würth Argentina | - | 23 Embalaje |  | P | FL_ACC_01
FL_MAT_ABC_2.5kg | 2 | ABC2.5-I8 | Soporte opcional (pared o vehicular, según pedido) | 0 | u |  |  | - | - | Compra | Sí | Maxiseguridad | CM Representaciones |  | IRAM 3517-2 7.4 | N |  | Sólo si el pedido lo incluye
FL_MAT_ABC_2.5kg | 1 | ABC2.5-S7 | Embalaje | 1 | u |  |  |  |  | Compra |  |  |  | 23 Embalaje -> 24 envolvedora (T11)
FL_MAT_ABC_2.5kg | 2 | ABC2.5-E1 | Caja de cartón corrugado simple | 1 | u |  |  | Cartón corrugado | 229 × 158 × 379 interior (envolvente del plano + 15 por lado) | Compra | Sí | Maxipack | Cartocan | 23 Embalaje |  | P |  | Medida del plano
FL_MAT_ABC_2.5kg | 2 | ABC2.5-E2 | Instructivo de uso y mantenimiento | 1 | u |  |  | Papel | A5 | Compra | Sí | Astuprint | - | 23 Embalaje |  | I |  | Decisión comercial de FLAMA (las instrucciones de uso obligatorias van en la etiqueta, IRAM 3534)
FL_MAT_ABC_2.5kg | 2 | ABC2.5-E3 | Pallet 1200 × 1000 (fracción) | 0.0111 | u |  |  | Madera | 90 u por pallet | Compra | Sí | IndusPallets | - | 23 Embalaje |  | C |  | u por pallet = acomodo de la caja (plano) en 1200 × 1000 × 1450 de alto
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

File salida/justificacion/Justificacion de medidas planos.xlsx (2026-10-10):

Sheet: Cómo leer
Justificación de medidas planos — FLAMA S.A.
• Valores crudos de cada pieza de los 17 planos FL_MAT (las piezas del recipiente son las de los planos FL_REC).
• Hojas «Manuales ABC», «Rodantes ABC» y «Revendidos»: una fila por pieza y dimensión; por modelo, el valor del plano y su fuente.
• Fuente «F10·3» = figura F10 del Word, marca roja n° 3. «D07» = valor de diseño FLAMA (hoja «Fuentes», con link a la línea del código).
• «cálculo» = sale de otros valores de la misma fila o de la pieza (la cuenta está en la columna «Criterio»; si cambia por modelo, en el comentario de la celda).
• Hacé clic en la fuente para ir a su fila en «Fuentes». El Word «Justificacion de medidas planos.docx» tiene la captura con la marca.
Colores (mismo criterio que el BOM)
Sin color: tomado de un documento (plano Fadesa, catálogo, norma, planilla MP) o calculado sólo con esos datos
Amarillo: valor de diseño FLAMA, sin documento (confirmar con el proveedor o el prototipo)
Naranja: a validar (derivado o relevado en fotos)
Total: 1157 dimensiones — con documento 763 (66 %), diseño FLAMA 306 (26 %), a validar 88 (8 %).
Lo que falta validar (naranja)
Pieza: dimensión | Modelos | Criterio usado / qué confirmar
Etiqueta / placa de características: Alas laterales (arco c/u) | los 17 | Relevamiento: la etiqueta envuelve ≈ 216° (72° si Ø < 100)
Estampilla IRAM de conformidad: Ancho × alto | los 17 | Anexo R IRAM + relevada (a confirmar)
Etiqueta de n° de serie GS1: Ancho × alto | los 17 | Relevada en Melisam
Faja de garantía válvula-cuello: Ancho × alto (relevada) / dibujada | los 17 | Relevada en la línea Georgia; se dibuja pegada sobre la unión (cuerpo de la válvula, tuerca y cuello), del lado donde no la tapan manómetro ni palancas; el ancho se limita al cuello
Tarjeta de identificación AGC (CABA): Ancho × alto | 16 (todos menos ABC 1 kg) | Relevada en un 10 kg (a confirmar con la AGC)
Cúpula: Altura del casquete | ABC 100 kg, ABC 70 kg | 0,656 × R (relación del cabezal Fadesa 50 kg: 105 / 160) = 0,656 × 195
Fondo: Altura del casquete | ABC 100 kg, ABC 70 kg | 0,656 × R (relación del cabezal Fadesa 50 kg: 105 / 160) = 0,656 × 195

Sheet: Manuales ABC
Manuales ABC — valor de cada dimensión en el plano y su fuente
Pieza | Dimensión | Unidad | ABC 1 kg |  | ABC 2.5 kg |  | ABC 5 kg |  | ABC 10 kg |  | Criterio (cómo se obtiene)
 |  |  | Valor | Fuente | Valor | Fuente | Valor | Fuente | Valor | Fuente
Conjunto | Altura total | mm | 327.4 | F07·3 + F14·1 | 358.7 | F08·3 + F14·3 | 434.7 | F09·3 + F14·5 | 607.7 | F10·3 + F14·7 | ABC 1 kg: Resulta de las piezas medidas en el plano Fadesa (catálogo: 340; diferencia -4 %) (cada modelo con sus valores: ver el comentario)
 | Ancho total | mm | 130.0 | F07·3 + F14·1 | 199.2 | F08·3 + F14·3 | 213.7 | F09·3 + F14·5 | 228.0 | F10·3 + F14·7 | ABC 1 kg: Resulta de las piezas medidas en el plano Fadesa (catálogo: 92; diferencia +41 %) · ABC 2.5 kg: Resulta de las piezas medidas en el plano Fadesa (catálogo: 220; diferencia -9 %) · ABC 5 kg: Resulta de las piezas medidas en el plano Fadesa (catálogo: 225; diferencia -5 %) · ABC 10 kg: Resulta de las piezas medidas en el plano Fadesa (catálogo: 230; diferencia -1 %)
 | Profundidad total | mm | 77.0 | F07·3 + F14·1 | 127.6 | F08·3 + F14·3 | 156.6 | F09·3 + F14·5 | 185.1 | F10·3 + F14·7 | ABC 1 kg: Resulta de las piezas medidas en el plano Fadesa (catálogo: 76; diferencia +1 %) (cada modelo con sus valores: ver el comentario)
 | Peso cargado según catálogo | kg | 1.9 | F14·1 | 4.6 | F14·3 | 8.5 | F14·5 | 16.5 | F14·7 | Transcripto del catálogo
 | Equipo vacío (suma de la lista de materiales) | kg | 0.98 | cálculo | 2.0 | cálculo | 3.32 | cálculo | 6.14 | cálculo | Σ (volumen del sólido × densidad × factor de llenado) de cada pieza de la lista
 | Masa total de referencia (verificación) | kg | 1.84 | F07·1 | 4.62 | F08·1 | 8.4 | F09·1 | 16.4 | F10·1 | ABC 1 kg: Referencia de verificación de masa del BOM: Plano Fadesa «Extintor 1 kg Ø76 (válvula HZ) R1» · ABC 2.5 kg: Referencia de verificación de masa del BOM: Plano Fadesa «Extintor 2,5 kg válvula HZ R1» · ABC 5 kg: Referencia de verificación de masa del BOM: Plano Fadesa «Extintor 5 kg válvula HZ R1» · ABC 10 kg: Referencia de verificación de masa del BOM: Plano Fadesa «Extintor 10 kg HZ R1»
 | Presión de servicio | MPa | 1.4 | F14·2 | 1.4 | F14·4 | 1.4 | F14·6 | 1.4 | F14·8 | Transcripto del catálogo
 | Presión de ensayo | MPa | 3.5 | F14·2 | 3.5 | F14·4 | 3.5 | F14·6 | 3.5 | F14·8 | Transcripto del catálogo
Recipiente | Volumen interior | dm³ | 1.18 | F01·11 | 3.5 | F02·12 | 6.0 | F03·12 | 12.5 | F04·14 | Cota del plano Fadesa de recipiente
 | Altura total del recipiente (apoyo a boca del cuello) | mm | 298.0 | F01·3 | 313.5 | F02·4 | 389.5 | F03·4 | 562.5 | F04·4 | Cota del plano Fadesa
 | Masa del recipiente (calculada, sin cordones) | kg | 0.74 | F01·10 | 1.4 | F02·11 | 2.69 | F03·11 | 5.43 | F04·13 | Σ volumen de cuerpo, cúpula, fondo, cuello y placas × 7,85 kg/dm³; comparar con la masa del plano Fadesa
Cuerpo (virola) | Ø exterior | mm | 76.2 | F01·5 | 124.0 | F02·7 | 153.0 | F03·7 | 181.5 | F04·7 | Cota del plano Fadesa
 | Espesor | mm | 1.25 | F01·8 | 1.25 | F02·10 | 1.6 | F03·10 | 2.0 | F04·11 | Cota/nota de espesor del plano Fadesa
 | Alto del cuerpo (piso o fondo a unión con la cúpula) | mm | 263.4 | F01·3 + F01·2 + F01 nota | 267.4 | F02·4 + F02·3 + F02·2 | 327.3 | F03·4 + F03·3 + F03·2 | 493.1 | F04·4 + F04·3 + F04·2 | ABC 1 kg: Altura total 298.0 − cuello 12.5 − cúpula en la boca − fondo 22 · ABC 2.5 kg: Altura total 313.5 − cuello 14 − cúpula en la boca · ABC 5 kg: Altura total 389.5 − cuello 15 − cúpula en la boca · ABC 10 kg: Altura total 562.5 − cuello 14 − cúpula en la boca
 | Bordón (escalón × labio; escalón de 1 e) | mm | 5,0 × 6,0 (los dos extremos) | F01·12 + F39·4 | 5,0 × 6,0 | F03·13 + F39·4 | 5,0 × 6,0 | F03·13 + F39·4 | 5,0 × 6,0 | F03·13 + F39·4 | Medido a escala 1:1 en el detalle 2 del plano Fadesa (labio 5,5-5,8; escalón 4,5-5,2); lo forma la bordoneadora (proceso de manuales)
 | Largo de corte del caño | mm | 255 | F36·1 | — |  | — |  | — |  | Planilla MP (caño cortado a 255 mm)
 | Desarrollo de la chapa π·(Ø − e) | mm | 235.5 | cálculo | 385.6 | cálculo | 475.6 | cálculo | 563.9 | cálculo | ABC 1 kg: π × (76.2 − 1.25) (cada modelo con sus valores: ver el comentario)
 | Masa de la pieza | kg | 0.607 | cálculo | 1.011 | cálculo | 1.954 | cálculo | 4.364 | cálculo | Volumen del sólido × 7,85 kg/dm³
 | Recorte de hoja (alto × desarrollo) | mm | — |  | 385,5 × 269,5 | F36·2 | 330 × 474,5 | F36·2 | 495 × 563 | F36·2 | Planilla MP fila 34 (desarrollo) y 35 (alto)
Cúpula | Ø exterior | mm | 76.2 | F01·5 | 124.0 | F02·7 | 153.0 | F03·7 | 181.5 | F04·7 | Cota del plano Fadesa
 | Espesor | mm | 0.9 | F01·9 | 1.25 | F02·10 | 1.6 | F03·10 | 1.6 | F04·10 | Cota/nota de espesor del plano Fadesa
 | Altura del casquete | mm | 12.5 | F01·2 | 39.5 | F02·3 | 54.5 | F03·3 | 62.5 | F04·3 | Cota del plano Fadesa
 | Ø del disco a embutir | mm | 108.0 | F36·3 | 179.0 | F36·3 | 221.0 | F36·3 | 258.0 | F36·3 | Planilla MP fila 38 (Ø del disco de cúpula)
 | Masa de la pieza | kg | 0.033 | cálculo | 0.173 | cálculo | 0.361 | cálculo | 0.501 | cálculo | Volumen del sólido × 7,85 kg/dm³
Fondo | Ø exterior | mm | 76.2 | F01·5 | 124.0 | F02·7 | 153.0 | F03·7 | 181.5 | F04·7 | Cota del plano Fadesa
 | Espesor | mm | 1.25 | F01·8 | 1.25 | F02·10 | 1.6 | F03·10 | 2.0 | F04·12 | Cota/nota de espesor del plano Fadesa
 | Altura del fondo | mm | 22 | F01·4 | — |  | — |  | — |  | Cota del plano Fadesa
 | Ø del disco a embutir | mm | 100.0 | F36·4 | 148.0 | F36·4 | 177.0 | F36·4 | 205.0 | F36·4 | Planilla MP fila 44 (Ø del disco de fondo)
 | Masa de la pieza | kg | 0.066 | cálculo | 0.166 | cálculo | 0.317 | cálculo | 0.508 | cálculo | Volumen del sólido × 7,85 kg/dm³
 | Altura de la pollera (borde del fondo) | mm | — |  | 16.0 | F02·5 | 21.5 | F03·5 | 16.5 | F04·5 | Cota del plano Fadesa
 | Pestaña del fondo encastrado (contra la pared) | mm | — |  | 10.0 | F03·14 + F39·3 | 10.0 | F03·14 + F39·3 | 10.0 | F03·14 + F39·3 | Detalle 3 del plano Fadesa (pestaña ≥ 10 a escala 1:1); fondo encastrado a presión (proceso de manuales); filete por debajo
 | Flecha del fondo cóncavo (centro sobre el piso) | mm | — |  | 5.5 | F02·6 | 5.5 | F03·6 | 4.8 | F04·6 | Cota del plano Fadesa
Cuello roscado | Ø exterior | mm | 29 | F01·1 | 37 | F02·1 | 37 | F03·1 | 36.8 | F04·1 | Cota del plano Fadesa
 | Altura sobre la cúpula | mm | 12.5 | F01 nota | 14 | F02·2 | 15 | F03·2 | 14 | F04·2 | Cota del plano Fadesa
 | Rosca |  | M22x1,5 | F01·6 | M30x1,5 | F02·8 | M30x1,5 | F03·8 | M30x1,5 | F04·8 | Rótulo del corte A-A del plano Fadesa
 | Ø del asiento | mm | 26 | F01·7 | 35 | F02·9 | 35 | F03·9 | 35 | F04·9 | Cota del corte A-A del plano Fadesa
 | Muesca de altura (ancho × prof. × alto) | mm | 2 × 1 × 2 | F39·2 + D01 | 2 × 1 × 2 | F39·2 + D01 | 2 × 1 × 2 | F39·2 + D01 | 2 × 1 × 2 | F39·2 + D01 | El proceso pide la muesca (prensa Pannier) sin medidas: valor de diseño

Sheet: Fuentes
Fuentes — capturas del Word (F) y valores de diseño FLAMA (D)
Id | Documento | Dónde | Datos tomados (n° de marca roja: valor) | Link
F01 | Plano Fadesa «1kg 3pulg R1» (código G809) | Página 1 (única), cotas y notas del plano | 1: Ø29 — Ø exterior del cuello; 2: 12,5 ± 0,2 — altura de cúpula; 3: 298 ± 0,5 — altura total del recipiente; 4: 22 ± 0,2 — altura del fondo; 5: Ø76,2 (3") ± 0,5 — Ø exterior; 6: M22x1,5 — rosca del cuello; 7: Ø26 ± 0,5 — asiento de la válvula; 8: Espesor chapa 1,25 — cuerpo y fondo; 9: Espesor cúpula 0,9; 10: Masa 0,76 kg — masa del recipiente; 11: Volumen 1,18 dm³; 12: Detalle 2 (1:1): bordón del caño bajo la cúpula — labio ≈ 5,5, escalón ≈ 4,5; 13: Detalle 3 (1:1): bordón inferior del caño, fondo por fuera — Nota: El plano no acota la altura del cuello por separado: se tomó 12,5 mm para completar la altura total de 298.
F02 | Plano Fadesa «Recipiente_2.5kg_R2_sin_logo» (código G731) | Página 1 (única), cotas y notas del plano | 1: Ø37 — Ø exterior del cuello; 2: 14 — altura del cuello; 3: 39,5 ± 0,3 — altura de cúpula; 4: 313,5 ± 0,5 — altura total; 5: 16 ± 0,3 — pollera del fondo cóncavo; 6: 5,5 — flecha del fondo cóncavo; 7: Ø124 ± 0,5 — Ø exterior; 8: M30x1,5 — rosca del cuello; 9: Ø35 ± 0,5 — asiento de la válvula; 10: Espesor de chapa 1,25 (cuerpo, cúpula y fondo); 11: Masa 1,48 kg; 12: Volumen 3,5 dm³
F03 | Plano Fadesa «Recipiente_5kg_R2_sin_logo» (código G732) | Página 1 (única), cotas y notas del plano | 1: Ø37 — Ø exterior del cuello; 2: 15 ± 0,2 — altura del cuello; 3: 54,5 ± 0,3 — altura de cúpula; 4: 389,5 ± 0,5 — altura total; 5: 21,5 ± 0,2 — pollera del fondo cóncavo; 6: 5,5 ± 0,1 — flecha del fondo cóncavo; 7: Ø153 ± 0,5 — Ø exterior; 8: M30x1,5 — rosca del cuello; 9: Ø35 ± 0,5 — asiento de la válvula; 10: Espesor de chapa 1,6 (cuerpo, cúpula y fondo); 11: Masa 2,78 kg; 12: Volumen 6 dm³; 13: Detalle 2 (1:1): bordón del cuerpo, cúpula por fuera — labio ≈ 5,8, escalón ≈ 5,2; 14: Detalle 3 (1:1): fondo encastrado con pestaña ≥ 10, filete por debajo
F04 | Plano Fadesa «Recipiente_10kg_R2_sin_logo» (código G733) | Página 1 (única), cotas y notas del plano | 1: Ø36,8 — Ø exterior del cuello; 2: 14 — altura del cuello; 3: 62,5 ± 0,3 — altura de cúpula; 4: 562,5 ± 0,8 — altura total; 5: 16,5 ± 0,2 — pollera del fondo cóncavo; 6: 4,8 — flecha del fondo cóncavo; 7: Ø181,5 ± 0,5 — Ø exterior; 8: M30x1,5 — rosca del cuello; 9: Ø35 + 0,3 — asiento de la válvula; 10: Espesor de cúpula 1,6; 11: Espesor de cuerpo 2; 12: Espesor de fondo 2; 13: Masa 5,48 kg; 14: Volumen 12,5 dm³
F05 | Plano Fadesa «Recipiente 25kg R3» (código G690) | Página 1 (única), cotas y notas del plano | 1: Ø37 — Ø exterior del cuello; 2: 35 — altura del cuello; 3: 87 ± 0,3 — altura del cabezal superior; 4: 493 ± 0,8 — largo del cuerpo entre cabezales; 5: 696,5 ± 0,8 — altura total del recipiente; 6: 87 ± 0,3 — altura del cabezal inferior; 7: Ø276,5 ± 0,5 — Ø exterior; 8: M30x1,5 — rosca del cuello; 9: Ø35 + 0,5 — asiento de la válvula; 10: Espesor de chapa 3,2; 11: Masa 15,92 kg; 12: Volumen 34,4 dm³; 13: Detalle 2 (1:1): casquete con borde reducido y tope dentro del cuerpo; 14: Detalle 3 (1:1): ídem en el casquete inferior — Nota: La altura total 696,5 no es igual a la suma de sus cotas parciales (87 + 493 + 87 + 35 = 702); el plano FLAMA usa las cotas parciales.
F06 | Plano Fadesa «Recipiente 50kg R2» (código G689) | Página 1 (única), cotas y notas del plano | 1: Ø88 — Ø exterior del cuello (cupla); 2: 37 — altura del cuello; 3: 105 ± 0,5 — altura del cabezal superior; 4: 640 ± 2 — largo del cuerpo entre cabezales; 5: 892 ± 0,5 — altura total del recipiente; 6: 105 ± 0,5 — altura del cabezal inferior; 7: Ø320 +3/−1 — Ø exterior; 8: RBSP 2 ½" x 11 h — rosca del cuello; 9: Ø80 ± 0,5 — asiento de la válvula; 10: Espesor 3,2; 11: Masa 23,3 kg; 12: Volumen 61,8 dm³ — Nota: La altura total 892 no es igual a la suma de sus cotas parciales (105 + 640 + 105 + 37 = 887); el plano FLAMA usa las cotas parciales. Estas cotas también se usan para el 70 kg (proporción del cabezal y volumen por kg) y para el cuello de 70 y 100 kg.
F07 | Plano Fadesa «Extintor 1kg Ø76 (Válvula HZ) R1» (código A114/117/122/123/138) | Página 1 (única): notas, cotas generales y piezas del despiece medidas a escala | 1: Masa total 1,84 kg (polvo) — referencia de verificación de masa; 2: Válvula HZ; 3: Válvula F510 (esc. 1:2,5): cuerpo 31 × 12 + horquilla 26,5; palanca 67; manija fija 49 + 27 (bajando 34,5); ancho de la válvula 109; espiga M22 Ø21 × 8,6; 4: Manómetro F645: Ø36; 5: O-ring F656: Ø24,8 × 3,5; 6: Vástago F915: Ø5 × 21, asiento Ø9; 7: Resorte F139: Ø9,8 × 19,9; 8: Tubo de pesca F003/617: cabeza Ø18,1, tubo Ø14,4 — Nota: Piezas medidas sobre el dibujo vectorial a la escala del rótulo (verificada con el Ø del recipiente acotado en su plano de recipiente). Precisión ≈ ±0,5 mm.
F08 | Plano Fadesa «Extintor_2.5kg_Valvula_HZ_R1_sin_logo» (código A101/139/151/128/135) | Página 1 (única): notas, cotas generales y piezas del despiece medidas a escala | 1: Masa total 4,62 kg (polvo); 2: Válvula HZ; 3: Válvula F192 (esc. 1:3): igual a la del 5 y 10 kg; 4: Racor: tuerca Ø18,8 × 5,9, casquillo Ø16,9 × 13,5, rosca Ø13,1 × 8,9; 5: Manómetro F645: Ø36 (35,7); 6: O-ring F646: Ø32,8 × 3,6; 7: Vástago F916: Ø6 × 30,6, asiento Ø14; 8: Resorte F653: Ø17,3 × 28,8; 9: Caño de pesca F682: cabeza Ø21,3; 10: Manguera: Ø17,4; 11: Portatobera Ø18,8 × 13,4 + tobera Ø19,9 × 60,1 — Nota: Piezas medidas sobre el dibujo vectorial a la escala del rótulo (verificada con el Ø del recipiente acotado en su plano de recipiente). Precisión ≈ ±0,5 mm.
F09 | Plano Fadesa «Extintor_5kg_Valvula_HZ_R1_sin_logo» (código A102/116/140/163/152/111/129/136) | Página 1 (única): notas, cotas generales y piezas del despiece medidas a escala | 1: Masa total 8,4 kg (polvo); 2: Válvula HZ; 3: Válvula F192 (esc. 1:4): palanca 127 de largo, 41,5 de alto sobre el cuerpo; cuerpo 38 × 12,8 + horquilla 32,2; espiga M30 Ø29,8 × 10,8; cuello Ø27,2 × 4,1; manija fija 50 + 36; 4: Racor: tuerca Ø18,8 × 5,9, casquillo Ø16,9 × 13,5, rosca Ø13,1 × 8,9; 5: Manómetro F645: Ø36 (35,7); 6: O-ring F646: Ø32,7 × 3,6; 7: Vástago F916: Ø6 × 30,8, asiento Ø14; 8: Resorte F653: Ø17,3 × 28,8; 9: Caño de pesca F682: cabeza Ø21,3; 10: Manguera: Ø17,4; 11: Portatobera Ø19 × 13,3 + tobera Ø19,9 × 60 — Nota: Piezas medidas sobre el dibujo vectorial a la escala del rótulo (verificada con el Ø del recipiente acotado en su plano de recipiente). Precisión ≈ ±0,5 mm. Esta válvula F192 es la que se usa también en los manuales revendidos (BC, HCFC, agua, AFFF, Sales K, clase D, CO₂ como referencia).
F10 | Plano Fadesa «Extintor_10kg_HZ_R1_sin_logo» (código A103/141/164/153/112/130/137) | Página 1 (única): notas, cotas generales y piezas del despiece medidas a escala | 1: Masa total 16,4 kg (polvo); 2: Válvula HZ; 3: Válvula F192 (esc. 1:4): 127 × 41,5; espiga M30 Ø29,8 × 10,8; 4: Racor: tuerca Ø18,8, casquillo Ø16,9, rosca Ø13,1; 5: Manómetro F645: Ø36 (35,7) × 31,5 con vástago; 6: O-ring F646: Ø32,7 × 3,6; 7: Vástago F916: Ø6 × 30,6, asiento Ø14 × 14; 8: Resorte F653: Ø17,3 × 28,8; 9: Caño de pesca F682: cabeza Ø21,3 × 14,4; 10: Manguera: Ø17,4 (líneas a 12,1 pt); 11: Portatobera Ø18,8 × 13,4 + tobera Ø19,9 × 60,1; 12: Suncho portamanguera F674: banda 14,4, sobresale 28,8 — Nota: Piezas medidas sobre el dibujo vectorial a la escala del rótulo (verificada con el Ø del recipiente acotado en su plano de recipiente). Precisión ≈ ±0,5 mm.
F11 | Plano Fadesa «Extintor rodante 25kg R1» (código B202/204/217/225/229/235) | Página 1 (única): notas, cotas generales y piezas del despiece medidas a escala | 1: Masa total 53,2 kg — referencia de masa (calibración de llanta y sunchos); 2: 1140 — altura total (coincide con el catálogo); 3: Ø300 — rueda (coincide con el catálogo); 4: Válvula F192 (esc. 1:6): la misma de los manuales (cuello M30); 5: Manómetro F645 + cubremanómetro G711: Ø47; 6: O-ring F646: Ø32,8; 7: Vástago F916: Ø6 × 30,6; 8: Resorte F653: Ø17,5 × 29; 9: Caño de pesca F226: cabeza Ø21,3 — Nota: Piezas medidas sobre el dibujo vectorial a la escala del rótulo (verificada con el Ø del recipiente acotado en su plano de recipiente). Precisión ≈ ±0,5 mm.
F12 | Plano Fadesa «Extintor rodante 50kg R1» (código B206/216/222/230/232/236/247) | Página 1 (única): notas, cotas generales y piezas del despiece medidas a escala | 1: Masa total 94 kg; 2: 1210 — altura total (coincide con el catálogo); 3: Ø350 — rueda (coincide con el catálogo); 4: Válvula G763 (esc. 1:7): brida Ø83 × 12 + rosca 2½" Ø75 × 17,6; cuerpo 49 × 67; 5: Manómetro F644 + cubremanómetro G711: Ø47; 6: Rueda Ø350: ancho de banda 48,9 (líneas a 19,8 pt) — Nota: Piezas medidas sobre el dibujo vectorial a la escala del rótulo (verificada con el Ø del recipiente acotado en su plano de recipiente). Precisión ≈ ±0,5 mm. Esta válvula y estas ruedas se usan también en el 70 kg y en el AFFF 50 l.
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

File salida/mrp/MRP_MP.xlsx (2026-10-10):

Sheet: Indexado Dim Técnico
PRODUCCION DE MATAFUEGOS TERMINADOS
Demanda | 2026 | 2027 | 2028 | 2029 | 2030 | 2031 | 2032 | 2033 | 2034 | 2035 | %
ABC 1 kg | 4178.736543 | 5997.303977 | 6851.747758 | 8467.135549 | 12680.63271 | 15620.25307 | 20332.55326 | 25132.07848 | 28573.33614 | 32072.63913 | 43.40%
ABC 2,5 kg | 295.0303572 | 709.7274503 | 986.8680576 | 1500.638174 | 2312.627726 | 3252.869887 | 4102.315524 | 5104.306587 | 6195.186243 | 7424.858444 | 10.05%
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

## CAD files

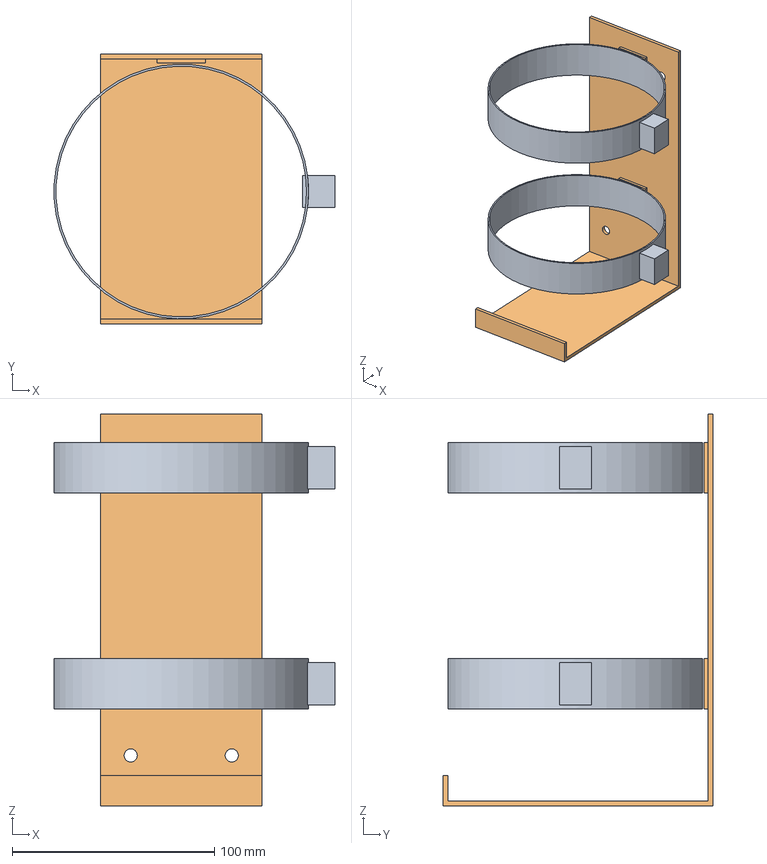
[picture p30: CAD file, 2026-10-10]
salida/accesorios/FL_ACC_02.step
138.9 x 133.5 x 194.0 mm

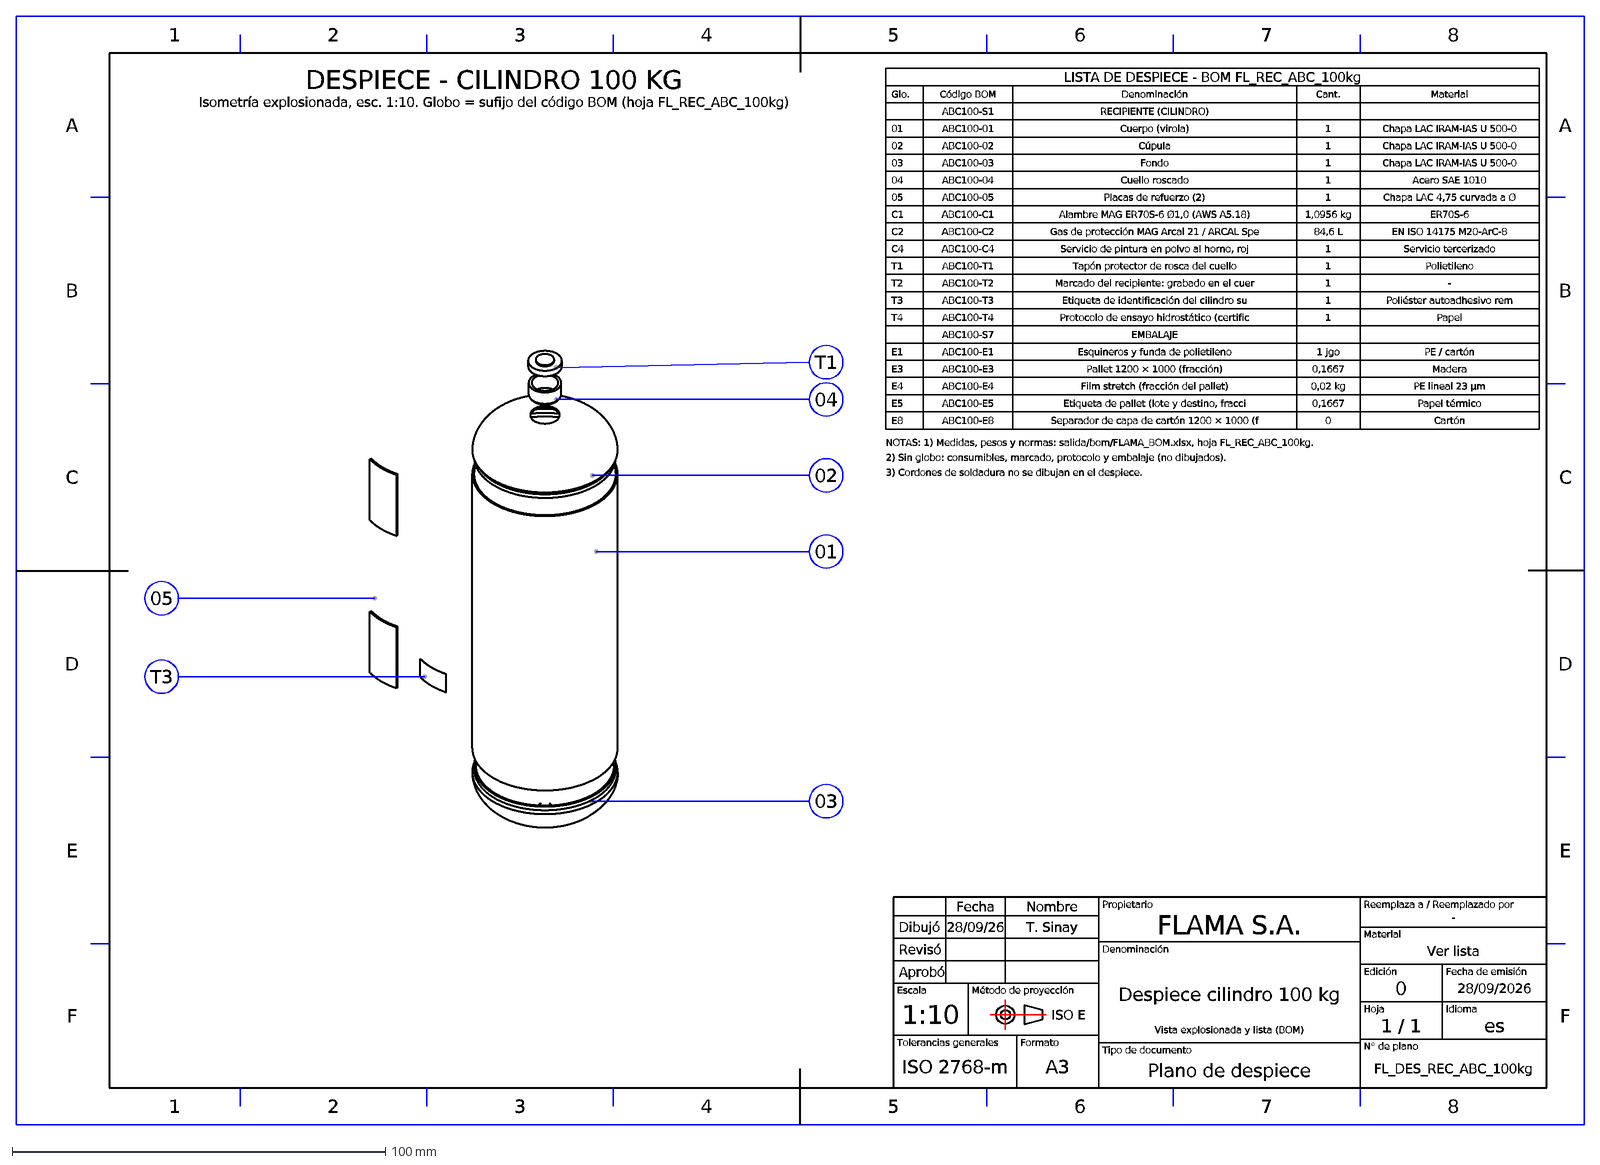
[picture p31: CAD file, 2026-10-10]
salida/cilindros/despiece/FL_DES_REC_ABC_100kg.dxf
1
2
3
4
5
6
7
8
F
E
D
C
B
A
T3
05
03
01
02
04
T1
DESPIECE - CILINDRO 100 KG
Isometría explosionada, esc. 1:10. Globo = sufijo del código BOM (hoja FL_REC_ABC_100kg)
LISTA DE DESPIECE - BOM FL_REC_ABC_100kg
Glo.
Código BOM
Denominación
Cant.
Material
ABC100-S1
RECIPIENTE (CILINDRO)
ABC100-01
Cuerpo (virola)
Chapa LAC IRAM-IAS U 500-0
ABC100-02
Cúpula
ABC100-03
Fondo
ABC100-04
Cuello roscado
Acero SAE 1010
ABC100-05
Placas de refuerzo (2)
Chapa LAC 4,75 curvada a Ø
C1
ABC100-C1
Alambre MAG ER70S-6 Ø1,0 (AWS A5.18)
1,0956 kg
ER70S-6
C2
ABC100-C2
Gas de protección MAG Arcal 21 / ARCAL Spe
84,6 L
EN ISO 14175 M20-ArC-8
C4
ABC100-C4
Servicio de pintura en polvo al horno, roj
Servicio tercerizado
ABC100-T1
Tapón protector de rosca del cuello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

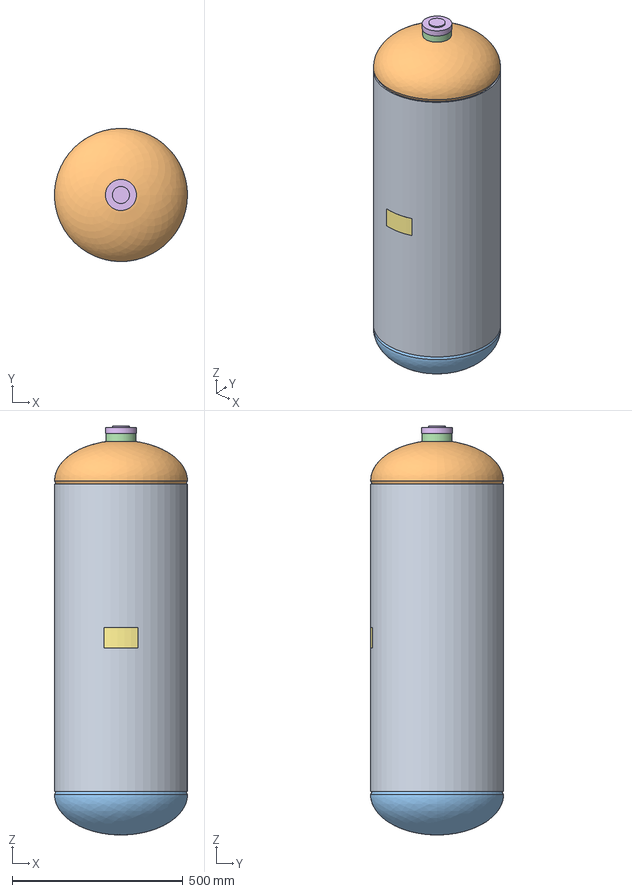
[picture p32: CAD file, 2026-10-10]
salida/cilindros/FL_REC_ABC_100kg/FL_REC_ABC_100kg.step
389.7 x 390.0 x 1198.3 mm
cuerpo
cupula
fondo
cuello
placas_refuerzo
tapon
etiqueta_rec

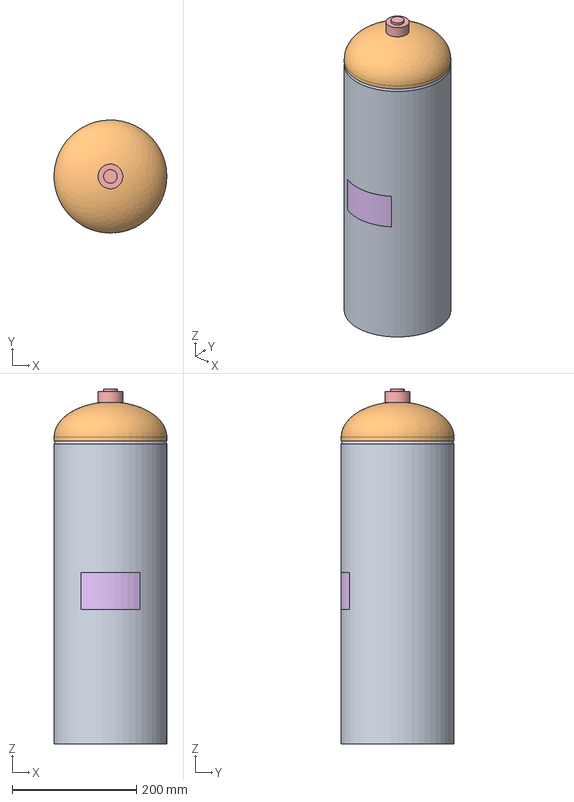
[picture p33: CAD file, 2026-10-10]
salida/cilindros/FL_REC_ABC_10kg/FL_REC_ABC_10kg.step
181.3 x 181.6 x 570.5 mm
cuerpo
cupula
fondo
cuello
tapon
etiqueta_rec

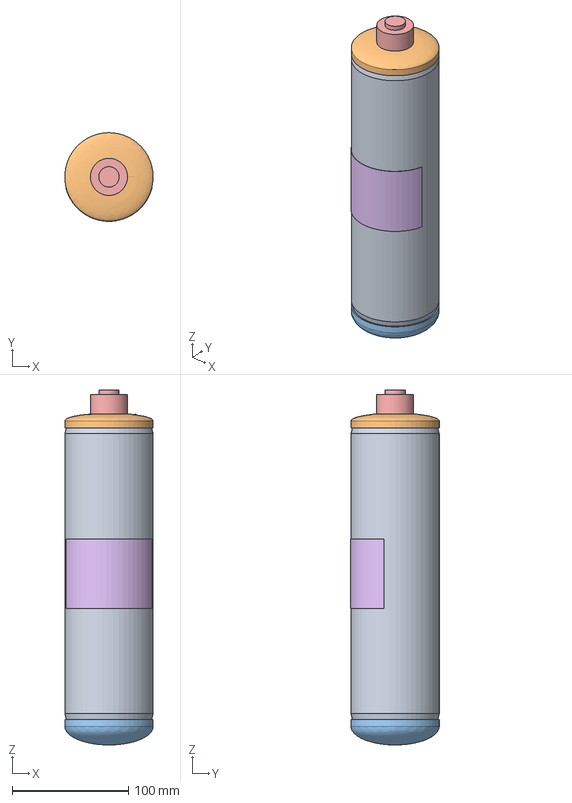
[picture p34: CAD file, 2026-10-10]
salida/cilindros/FL_REC_ABC_1kg/FL_REC_ABC_1kg.step
76.1 x 76.4 x 306.0 mm
cuerpo
cupula
fondo
cuello
tapon
etiqueta_rec

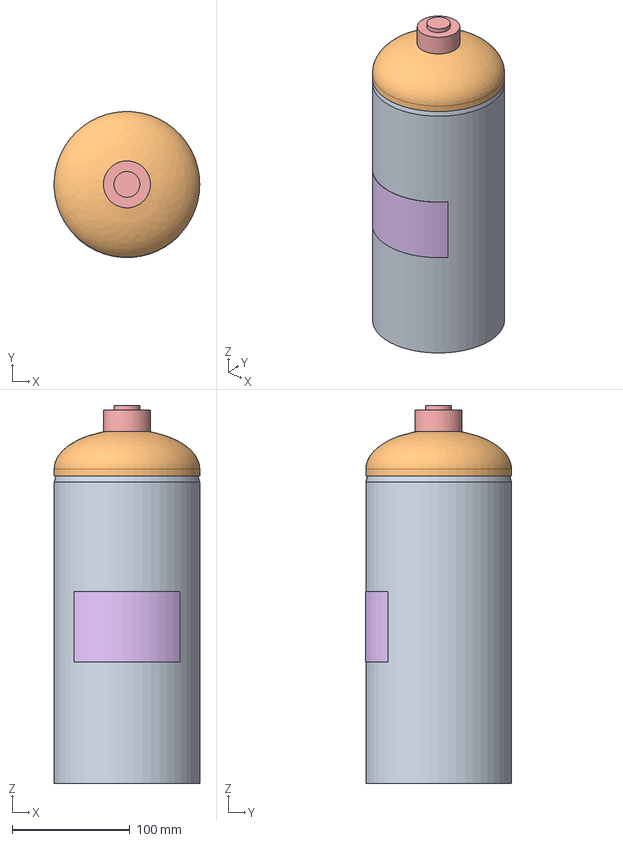
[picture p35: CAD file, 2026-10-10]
salida/cilindros/FL_REC_ABC_2.5kg/FL_REC_ABC_2.5kg.step
123.9 x 124.2 x 321.5 mm
cuerpo
cupula
fondo
cuello
tapon
etiqueta_rec

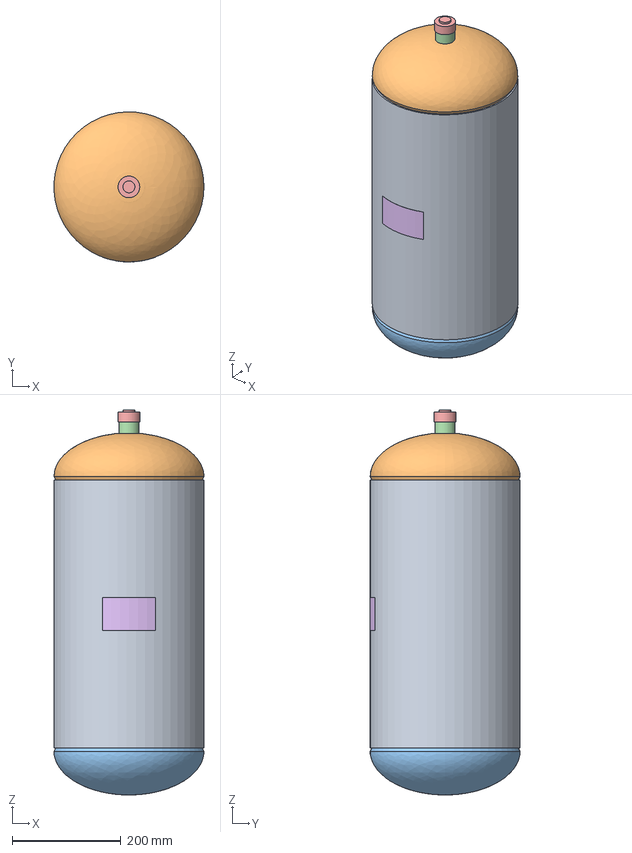
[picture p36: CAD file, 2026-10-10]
salida/cilindros/FL_REC_ABC_25kg/FL_REC_ABC_25kg.step
276.2 x 276.7 x 709.4 mm
cuerpo
cupula
fondo
cuello
tapon
etiqueta_rec

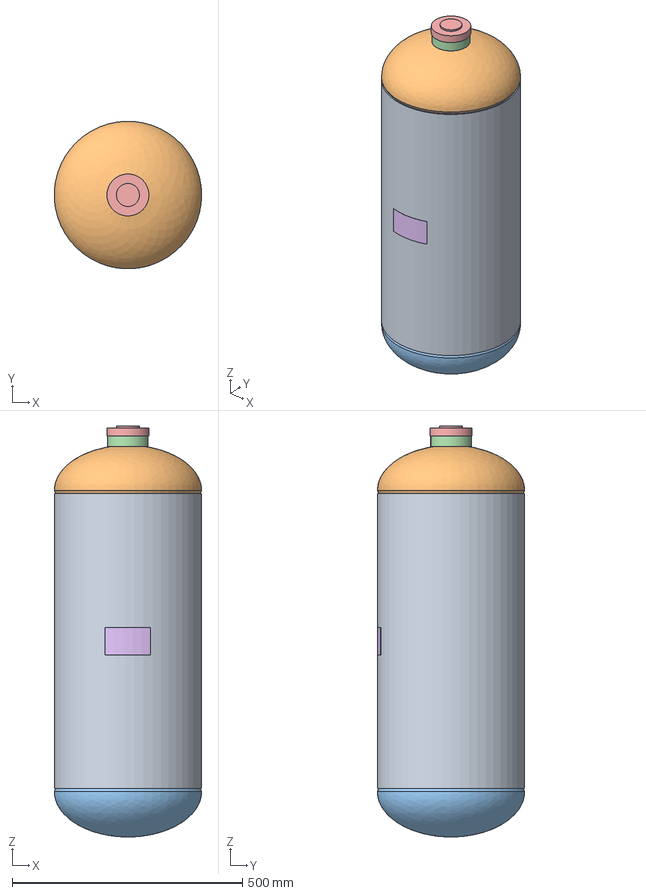
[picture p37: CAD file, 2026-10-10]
salida/cilindros/FL_REC_ABC_50kg/FL_REC_ABC_50kg.step
319.7 x 319.9 x 891.9 mm
cuerpo
cupula
fondo
cuello
tapon
etiqueta_rec

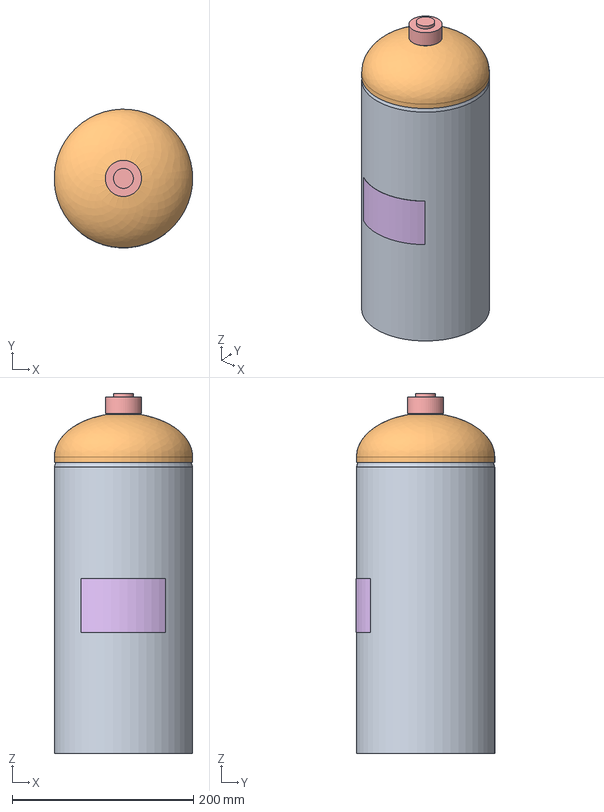
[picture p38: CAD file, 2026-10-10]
salida/cilindros/FL_REC_ABC_5kg/FL_REC_ABC_5kg.step
152.9 x 153.1 x 397.5 mm
cuerpo
cupula
fondo
cuello
tapon
etiqueta_rec

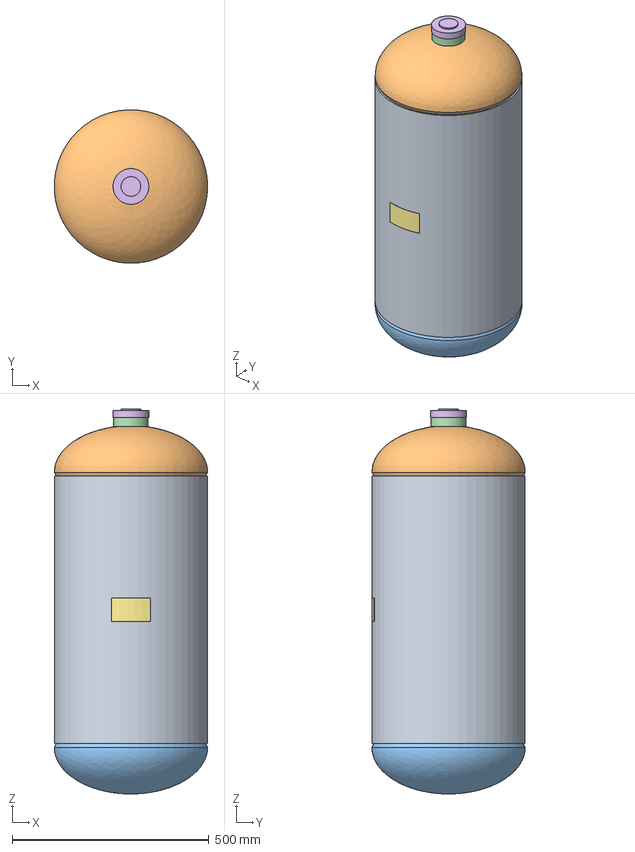
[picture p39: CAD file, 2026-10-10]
salida/cilindros/FL_REC_ABC_70kg/FL_REC_ABC_70kg.step
389.6 x 390.0 x 978.3 mm
cuerpo
cupula
fondo
cuello
placas_refuerzo
tapon
etiqueta_rec

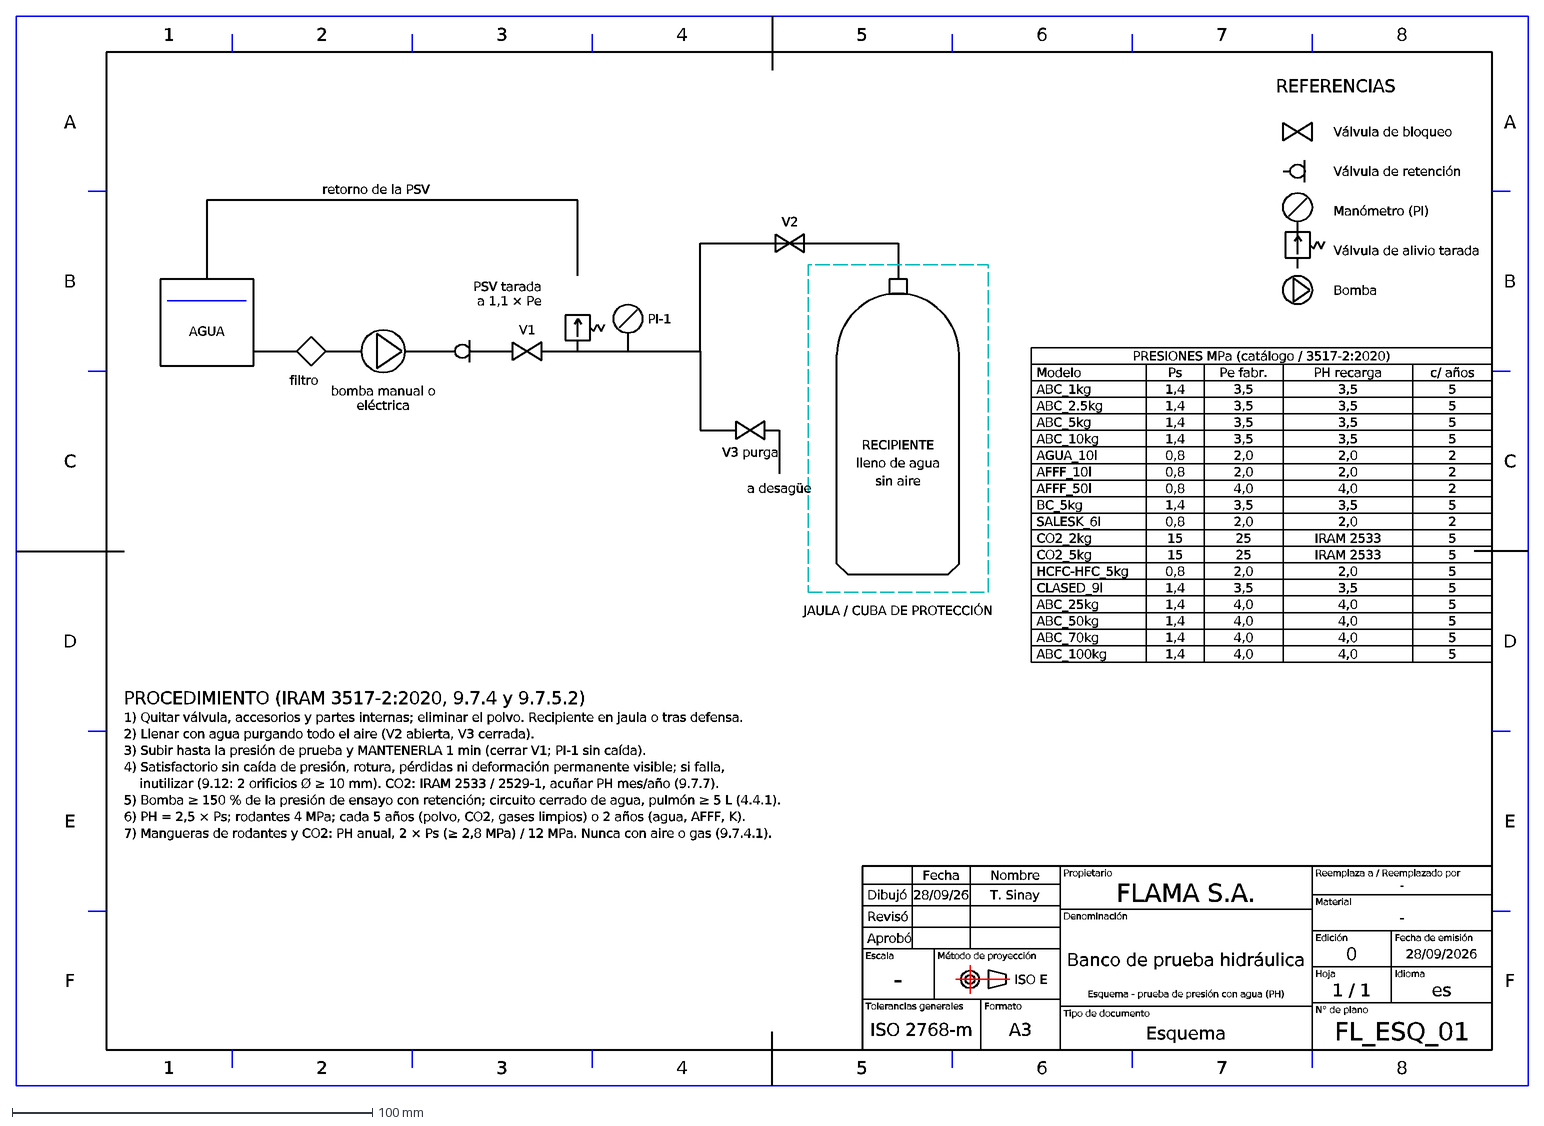
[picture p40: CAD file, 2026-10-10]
salida/esquemas/FL_ESQ_01.dxf
1
2
3
4
5
6
7
8
F
E
D
C
B
A
Fecha
Nombre
Dibujó
28/09/26
T. Sinay
Revisó
Aprobó
Escala
-
Método de proyección
ISO E
Tolerancias generales
ISO 2768-m
Formato
A3
Propietario
FLAMA S.A.
Denominación
Banco de prueba hidráulica
Esquema - prueba de presión con agua (PH)
Tipo de documento
Esquema
Reemplaza a / Reemplazado por
Material
Edición
0
Fecha de emisión
28/09/2026
Hoja
1 / 1
Idioma
es
N° de plano
FL_ESQ_01
AGUA
filtro
bomba manual o
eléctrica
V1
PSV tarada
a 1,1 × Pe
PI-1
V2
RECIPIENTE
lleno de agua
sin aire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

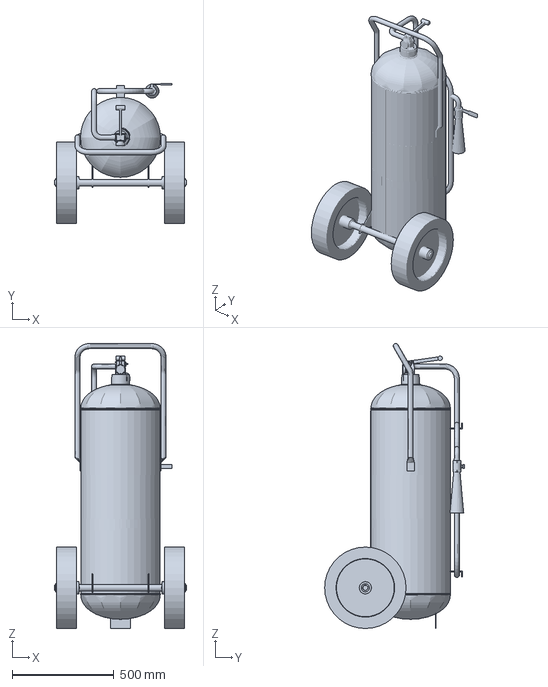
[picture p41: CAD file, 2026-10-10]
salida/FL_MAT_ABC_100kg/FL_MAT_ABC_100kg_3D.dxf
650.0 x 686.5 x 1400.0 mm

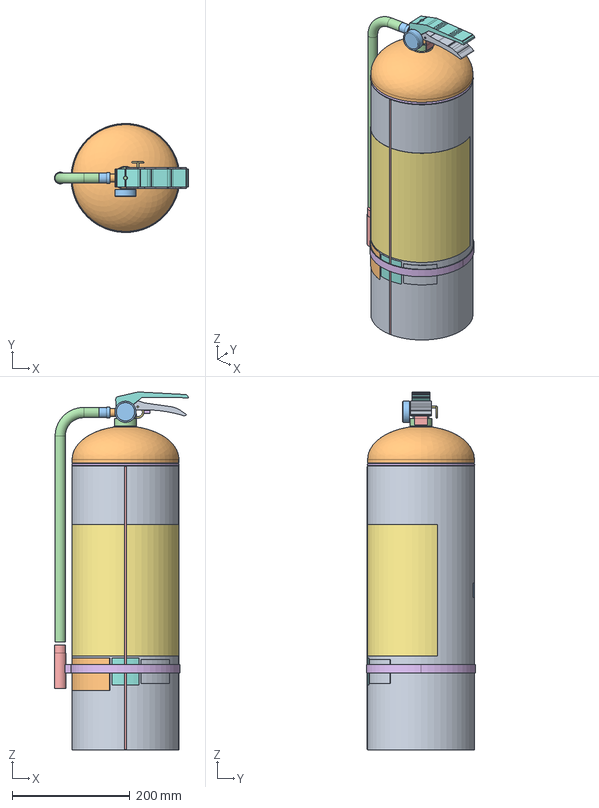
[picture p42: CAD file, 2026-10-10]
salida/FL_MAT_ABC_10kg/FL_MAT_ABC_10kg.step
228.0 x 185.0 x 607.7 mm
cuerpo
cupula
fondo
cuello
soldaduras
espiga
tuerca
cuerpo_valvula
manometro
vastago
resorte
eje
pasador
manija_superior
manija_inferior
cano_pesca
racor
manguera
tobera
suncho
etiqueta
oblea_pba
sello_iram
tarjeta_caba
etiqueta_serie
junta_cuello
faja_garantia
precinto

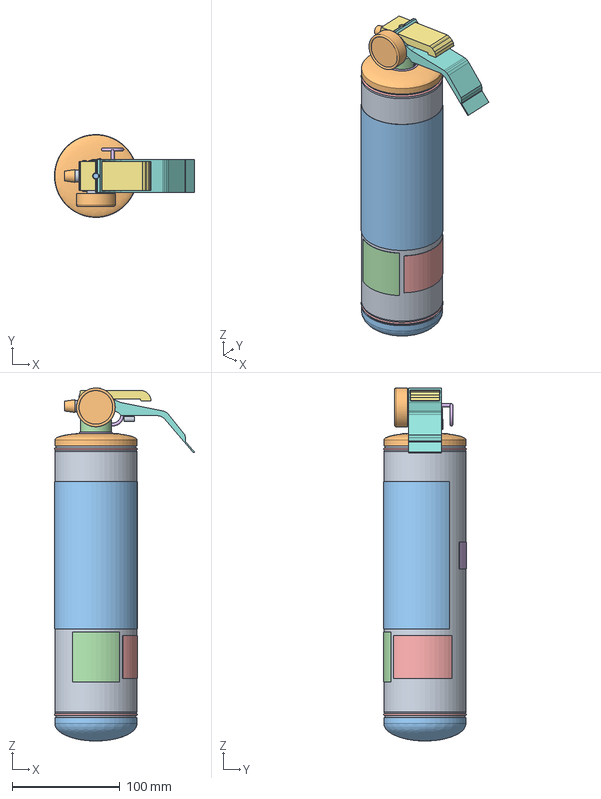
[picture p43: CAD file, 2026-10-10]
salida/FL_MAT_ABC_1kg/FL_MAT_ABC_1kg.step
129.9 x 76.9 x 327.4 mm
cuerpo
cupula
fondo
cuello
soldaduras
espiga
tuerca
cuerpo_valvula
manometro
vastago
resorte
eje
pasador
manija_superior
manija_inferior
cano_pesca
tobera
etiqueta
oblea_pba
sello_iram
etiqueta_serie
junta_cuello
faja_garantia
precinto

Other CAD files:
salida/despiece/FL_DES_ABC_5kg.dxf
salida/FL_MAT_ABC_2.5kg/FL_MAT_ABC_2.5kg.step
salida/FL_MAT_ABC_25kg/FL_MAT_ABC_25kg.step
salida/FL_MAT_ABC_50kg/FL_MAT_ABC_50kg_3D.dxf
salida/FL_MAT_ABC_100kg/FL_MAT_ABC_100kg.dxf
salida/FL_MAT_ABC_100kg/FL_MAT_ABC_100kg.step
salida/FL_MAT_ABC_10kg/FL_MAT_ABC_10kg.dxf
salida/FL_MAT_ABC_10kg/FL_MAT_ABC_10kg_3D.dxf
salida/FL_MAT_ABC_1kg/FL_MAT_ABC_1kg.dxf
salida/FL_MAT_ABC_1kg/FL_MAT_ABC_1kg_3D.dxf
salida/FL_MAT_ABC_2.5kg/FL_MAT_ABC_2.5kg.dxf
salida/FL_MAT_ABC_2.5kg/FL_MAT_ABC_2.5kg_3D.dxf
salida/FL_MAT_ABC_25kg/FL_MAT_ABC_25kg.dxf
salida/FL_MAT_ABC_25kg/FL_MAT_ABC_25kg_3D.dxf
salida/FL_MAT_ABC_50kg/FL_MAT_ABC_50kg.dxf
salida/FL_MAT_ABC_50kg/FL_MAT_ABC_50kg.step
salida/FL_MAT_ABC_5kg/FL_MAT_ABC_5kg.dxf
salida/FL_MAT_ABC_5kg/FL_MAT_ABC_5kg.step
salida/FL_MAT_ABC_5kg/FL_MAT_ABC_5kg_3D.dxf
salida/FL_MAT_ABC_70kg/FL_MAT_ABC_70kg.dxf
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

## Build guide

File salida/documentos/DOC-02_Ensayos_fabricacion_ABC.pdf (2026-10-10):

FLAMA S.A. | Ensayos de fabricación - matafuegos ABC | DOC-02
Edición 0 | FL_MAT_ABC_1kg a FL_MAT_ABC_100kg y FL_REC_ABC_* | 28/09/2026

# Ensayos obligatorios de fabricación - matafuegos ABC

## 1. Normas de referencia

- IRAM 3523 - Matafuegos manuales de polvo bajo presión (ABC 1 a 10 kg).
- IRAM 3550 - Matafuegos rodantes de polvo (ABC 25 a 100 kg).
- IRAM 3569 - Polvo químico seco ABC. IRAM 3533 - Manómetros para matafuegos.
- ISO 15614-1 / ISO 9606-1 - calificación de procedimientos y soldadores; ISO 5817 - niveles de calidad.
- Referencia complementaria: EN 3-7 y EN 1866-1 (matafuegos portátiles y rodantes, Unión Europea).

## 2. Datos de catálogo por modelo

Modelo | Carga | Ps (MPa) | Pe (MPa) | Descarga (s) | Alcance (m) | T (°C) | Norma
FL_MAT_ABC_1kg | 1 kg Ø3 | 1,4 | 3,5 | 8/9 | 2/3 | -20 a 50 | IRAM 3523
FL_MAT_ABC_2.5kg | 2,5 kg | 1,4 | 3,5 | 9/12 | 3/4 | -20 a 50 | IRAM 3523
FL_MAT_ABC_5kg | 5 kg | 1,4 | 3,5 | 10/13 | 5/6 | -20 a 50 | IRAM 3523
FL_MAT_ABC_10kg | 10 kg | 1,4 | 3,5 | 18/22 | 6/7 | -20 a 50 | IRAM 3523
FL_MAT_ABC_25kg | 25 kg | 1,4 | 4,0 | 40 | 5/6 | -20 a 50 | IRAM 3550
FL_MAT_ABC_50kg | 50 kg | 1,4 | 4,0 | 45 | 6/7 | -20 a 50 | IRAM 3550
FL_MAT_ABC_70kg | 70 kg | 1,4 | 4,0 | 50 | 7/8 | -20 a 50 | IRAM 3550
FL_MAT_ABC_100kg | 100 kg | 1,4 | 4,0 | 55 | 8/9 | -20 a 50 | IRAM 3550

## 3. Plan de ensayos

### 3.1 Ensayos de rutina (100 % de las unidades)

N° | Ensayo | Método y criterio | Frecuencia | Fuente
R1 | Control de chapa | certificado de colada; espesor ≥ nominal del plano FL_REC (micrómetro) | por bobina | N / C
R2 | Inspección visual de soldaduras | ISO 5817 nivel C: sin fisuras, poros abiertos ni falta de penetración visible en costura longitudinal, circunferencial y cuello | 100 % | N
R3 | Prueba hidráulica del recipiente (FL_ESQ_01) | presión de ensayo Pe del catálogo (3,5 MPa manuales; 4,0 MPa rodantes) mantenida 1 min (IRAM 3517-2:2020 9.7.5.2): sin caída de presión, pérdidas ni deformación permanente visible; bomba ≥ 150 % de Pe y jaula | 100 % | C / N
R4 | Secado interior | después de la PH, hasta que no se vea agua ni humedad condensada (IRAM 3517-2:2020 9.8.2, con cámara de inspección) | 100 % | N
R5 | Pintura | espesor y adherencia según DOC-01 | por lote | R
R6 | Carga de agente | pesada de polvo ABC gris IRAM 3569 con balanza calibrada; tolerancia 1 y 2,5 kg: 0/+100 g; 5 y 10 kg: 0/ +300 g; rodantes: +3 % (IRAM 3517-2:2020 tabla 3); recinto HR ≤ 70 % (9.4.8) | 100 % | N

FLAMA S.A. · DOC-02 · página 1 de 2

R7 | Presurización | N2

seco a la presión de
| | servicio (1,4 MPa a 20 °C); verificación con manómetro patrón; aguja del manómetro IRAM 3533 en zona verde
100 % | C / N
R8 | Estanqueidad | ensayo de verificación de pérdidas de propelente y agente (IRAM 3517-2:2020 9.4.10): inmersión o detector; control de presión a las 24 h (criterio FLAMA) | 100 % | N / R
R9 | Pesada final y marcado | masa total dentro de la tolerancia; etiqueta, n° de serie, sello IRAM, fecha; precinto y seguro colocados | 100 % | N / C

### 3.2 Ensayos por lote (muestreo)

N° | Ensayo | Método y criterio | Frecuencia | Fuente
L1 | Rotura (destructivo) | presurizar hasta 2 × la presión de PH sin fisuras ni pérdidas; luego hasta la rotura, sin desprendimiento de material; si rompe en una soldadura, ≥ 8 × Ps (criterio de IRAM 3504 5.1.4, norma hermana; confirmar en IRAM 3523/3550) | 1 por lote (IRAM 3504 7.1.4) | N* / R
L2 | Expansión volumétrica | a la presión de PH con la válvula colocada: deformación permanente ≤ 10 % de la total (IRAM 3504 5.1.3, norma hermana); secado a 105 °C ± 2 °C | 10 % del lote (IRAM 3504 7.1.3) | N* / R
L3 | Descarga | manuales: ≥ 8 s y ≥ 85 % descargado; rodantes: 25 kg ≥ 10 s, 50/70 kg ≥ 15 s, 100 kg ≥ 30 s, ≥ 85 % (IRAM 3517-2:2020 tabla 3); alcance según catálogo | 1 por lote | N / C
L4 | Polvo | certificado del lote IRAM 3569; humedad y fluidez según certificado | por lote de polvo | N
L5 | Manómetros y válvulas | certificado IRAM 3533; prueba de la válvula a Pe | por partida | N / R

### 3.3 Ensayos de tipo (certificación, laboratorio acreditado)

- Potencial extintor en fuegos normalizados clase A y B y ensayo de conductividad para clase C.
- Funcionamiento en los extremos del rango de temperatura del catálogo (−20 °C y +50 °C).
- Resistencia a la corrosión (niebla salina, DOC-01), caída y vibración (manuales), y rodadura y estabilidad (rodantes, IRAM 3550).
- Se repiten al cambiar el diseño, el proveedor del polvo, la válvula o el procedimiento de soldadura.

## 4. Recipientes ABC sueltos (FL_REC_ABC_*)

Se entregan con R1 a R5, L1 y L2 aprobados, con el n° de serie y la fecha de PH estampados, el interior seco y el cuello protegido con tapón. El armado final (R6 a R9) queda a cargo del comprador, que asume los ensayos de conjunto.

## 5. Registros

Por n° de serie: colada de chapa, soldador, fecha y resultado de PH, lote de polvo, peso, presión y estanqueidad. Conservar según el sistema de calidad (mínimo la vida útil del matafuego).
Fuente: C = catálogo FLAMA · N = norma citada (texto leído) · N* = norma hermana aplicada por analogía · R = valor de referencia habitual, a confirmar por FLAMA con la edición vigente de la norma IRAM (el texto de las normas IRAM es material protegido y no se transcribe).

FLAMA S.A. · DOC-02 · página 2 de 2

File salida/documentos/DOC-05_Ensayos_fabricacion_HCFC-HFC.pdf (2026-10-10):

FLAMA S.A. | Ensayos de fabricación - HCFC/HFC | DOC-05
Edición 0 | FL_MAT_HCFC-HFC_5kg (IRAM 3504) | 28/09/2026

# Ensayos de fabricación del extintor de gases limpios

Base: IRAM de Emergencia 3504:2001 (primera edición, vigencia de emergencia de un año; copia consultada con traducción parcial al portugués). Confirmar con la edición vigente. Los valores del catálogo FLAMA figuran como C.

## 1. Construcción

Ítem | Requisito | Apartado
Recipiente | acero al carbono ≥ 0,71 mm con recubrimiento anticorrosivo exterior (o aluminio 6061/6063 ≥ 0,71 mm sin soldaduras, o inoxidable ≥ 0,63 mm) | 4.3.1
Costuras | acero: como máximo una longitudinal y dos transversales (sin contar cuello y accesorios), por proceso automático: arco sumergido, resistencia, atmósfera inerte o brazing | 4.3.2
Fondo | espesor en la zona de apoyo ≥ 1,5 × espesor real de la parte cilíndrica | 5.1.1
Abertura | roscada, diámetro interior ≥ 19 mm | 5.1.2
Válvula | descarga continua o intermitente; traba con precinto identificado; si se puede quitar bajo presión, despresurización con ≥ 3 filetes enroscados; rosca ≥ 4 filetes | 4.4
Manguera | ≥ 350 mm (2,5 kg y mayores); PH a 2 × Ps sin pérdidas | 5.2
Gas impulsor | HCFC Mezcla B: argón; otros: argón o nitrógeno seco con punto de rocío ≤ −56,7 °C | 4.11
Presión de servicio | < 1,7 MPa (catálogo: 0,8 MPa) | 5.6 / C
Base | extintores de 2,5 kg y mayores se mantienen parados en forma estable | 4.13

## 2. Ensayos

Ensayo | Criterio | Apartado | Frecuencia
Estanqueidad y expansión (PH) | a la mayor de 1,5 × Pmáx de servicio, 2,5 × Ps o 0,8 MPa (FLAMA: 2,0 MPa; catálogo 2,0 MPa): sin pérdidas, fisuras ni roturas; deformación permanente ≤ 10 % de la total. Luego secado a 105 °C ± 2 °C | 5.1.3 / 8.2 | 10 % del lote
Rotura | a 2 × la presión de 5.1.3 sin fisuras ni pérdidas; hasta rotura sin desprendimiento de material; si rompe en una soldadura, a ≥ 8 × Ps | 5.1.4 / 8.3 | 1 por lote
Corrosión | niebla salina (IRAM 121): 96 h sin corrosión galvánica y recubrimiento adherido; 240 h: funciona y se recarga, recipiente sin corrosión | 5.1.5 | tipo
Capacidad | 1 y 2,5 kg: 0 / −2 %; 5 y 10 kg: 0 / −3 % (balanza de 50 g) | 5.5 / 8.5 | rutina
Funcionamiento continuo | ≥ 90 % de la carga en ≥ 8 s, acondicionado 16 h a 50 °C y a −20 °C | 5.8.1 / 8.8.2 | tipo
Funcionamiento intermitente | ≥ 90 % descargado en pulsos de 2 s cada 10 s | 5.8.3 / 8.8.3 | tipo
Caudal | variación ≤ 10 % del valor medio de tres extintores | 5.8.4 / 8.8.4 | tipo

FLAMA S.A. · DOC-05 · página 1 de 2

Trato rudo | 3 caídas desde 0,9 m (hasta 2,5 kg)
o 0,6 m (mayores): pérdida ≤ 10 % de Ps; traba liberable con ≤ 180 N; funciona y extingue
5.9 / 8.9 | tipo
Vibraciones | 10 a 60 Hz en tres ejes y 2 h en resonancia; luego funcionamiento y alcance | 5.7 / 8.7 | tipo
Potencial extintor | 5 kg: 1 A y 5 B (tabla 2); 1 kg: 2 B; 2,5 kg: 1 A 3 B; 10 kg: 2 A 10 B | 5.12 | tipo
Conductividad | apto clase C: no conductor (IRAM 3544) | 5.13 | tipo
Pérdidas | inmersión, solución tensioactiva o detector de gases | 4.12 / 8.10 | 100 %
Plásticos | envejecimiento 180 d a 100 °C y UV 720 h (ASTM G 153) | anexo A | tipo

## 3. Marcado

Fabricante, n° de recipiente y año grabados; placa IRAM 3534 con las leyendas de precaución por uso en espacios cerrados y de contenido bajo presión, y datos del gas y del impulsor según IRAM 3526. Color rojo 03-1-050 de IRAM-DEF D 1054 (salvo inoxidable) (6.1 a 6.3).

## 4. Inspección de lotes

10 % del lote a PH y expansión; si falla alguno, se ensaya el 100 %; lote rechazado si antes del 50 % falla más del 10 %. Rotura: un recipiente por lote. Extintor terminado: IRAM 15/18, nivel II, AQL 4 % (PH de manguera, funcionamiento, pérdidas) y 6,5 % (resto) (7.1 a 7.3).
Fuente: C = catálogo FLAMA · N = norma citada (texto leído) · N* = norma hermana aplicada por analogía · R = valor de referencia habitual, a confirmar por FLAMA con la edición vigente de la norma IRAM (el texto de las normas IRAM es material protegido y no se transcribe).

FLAMA S.A. · DOC-05 · página 2 de 2

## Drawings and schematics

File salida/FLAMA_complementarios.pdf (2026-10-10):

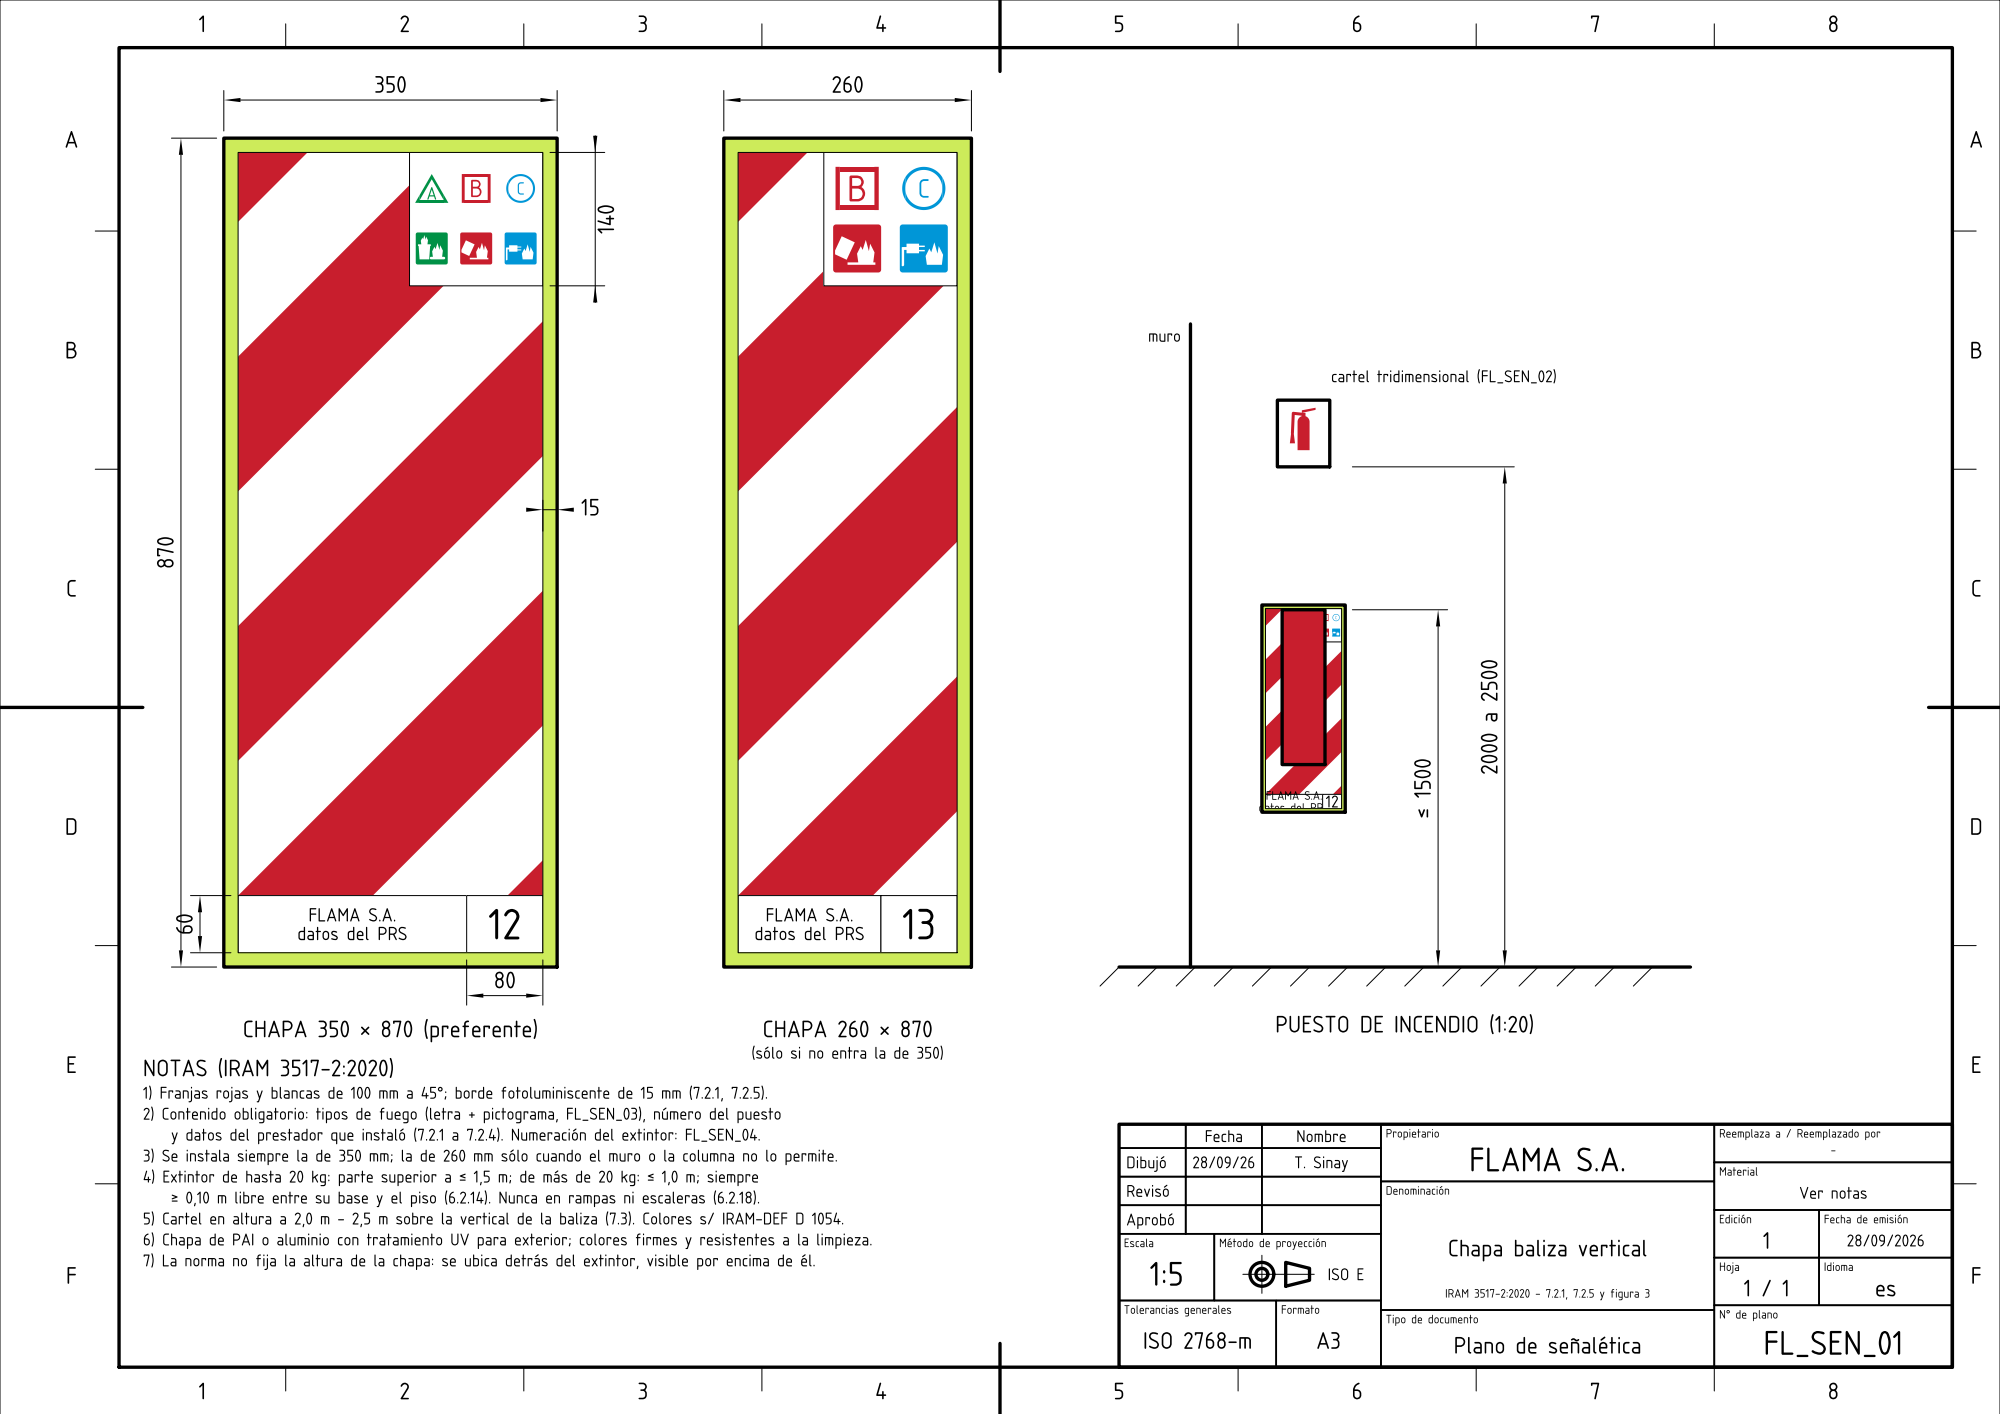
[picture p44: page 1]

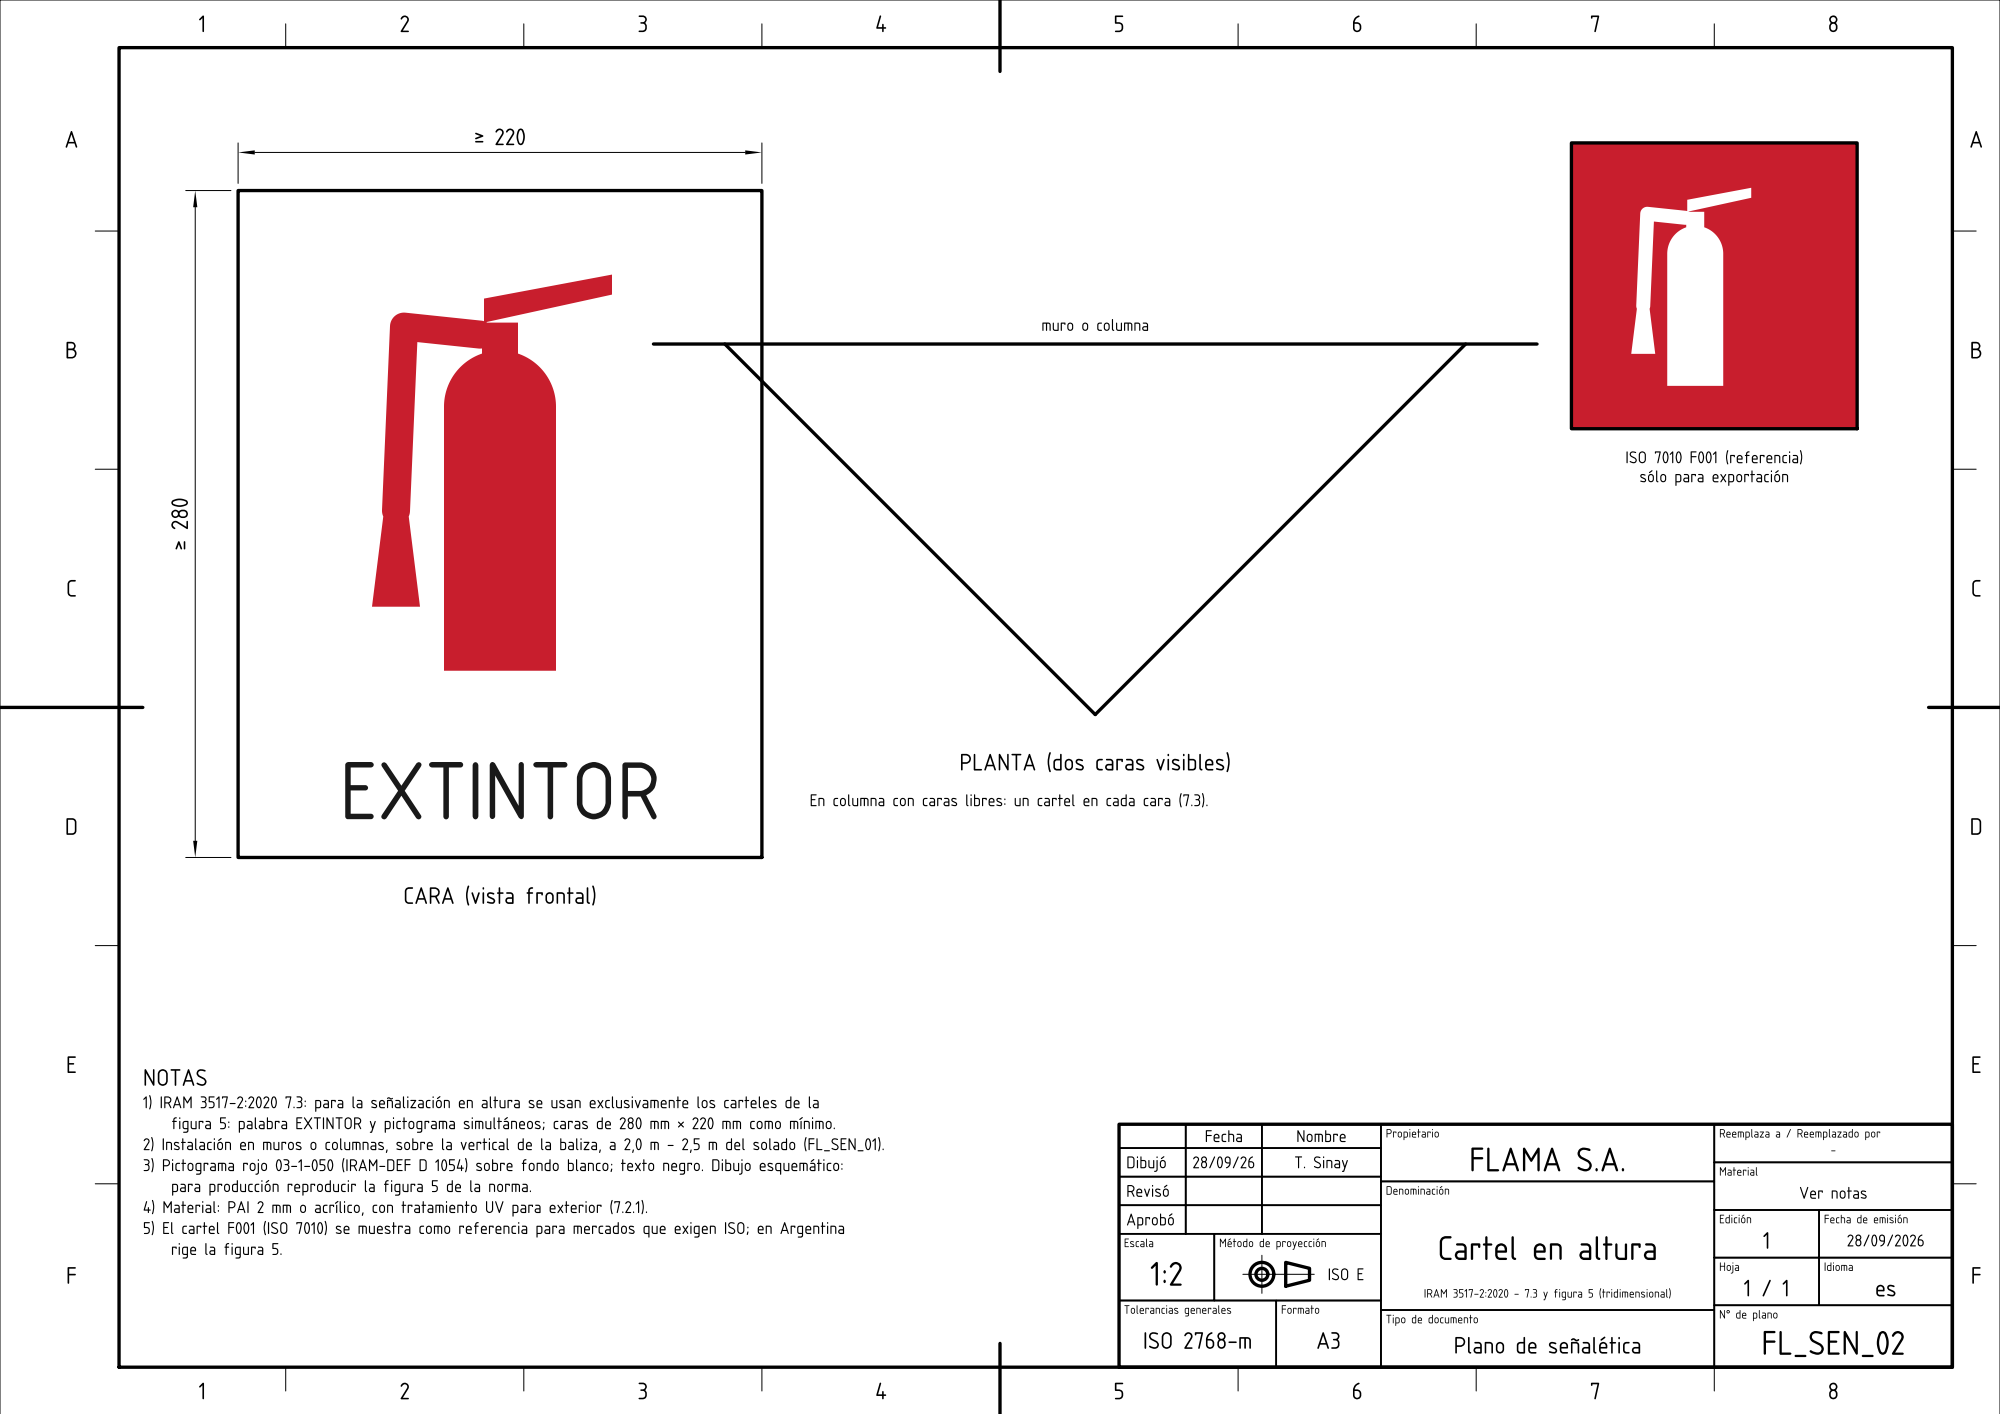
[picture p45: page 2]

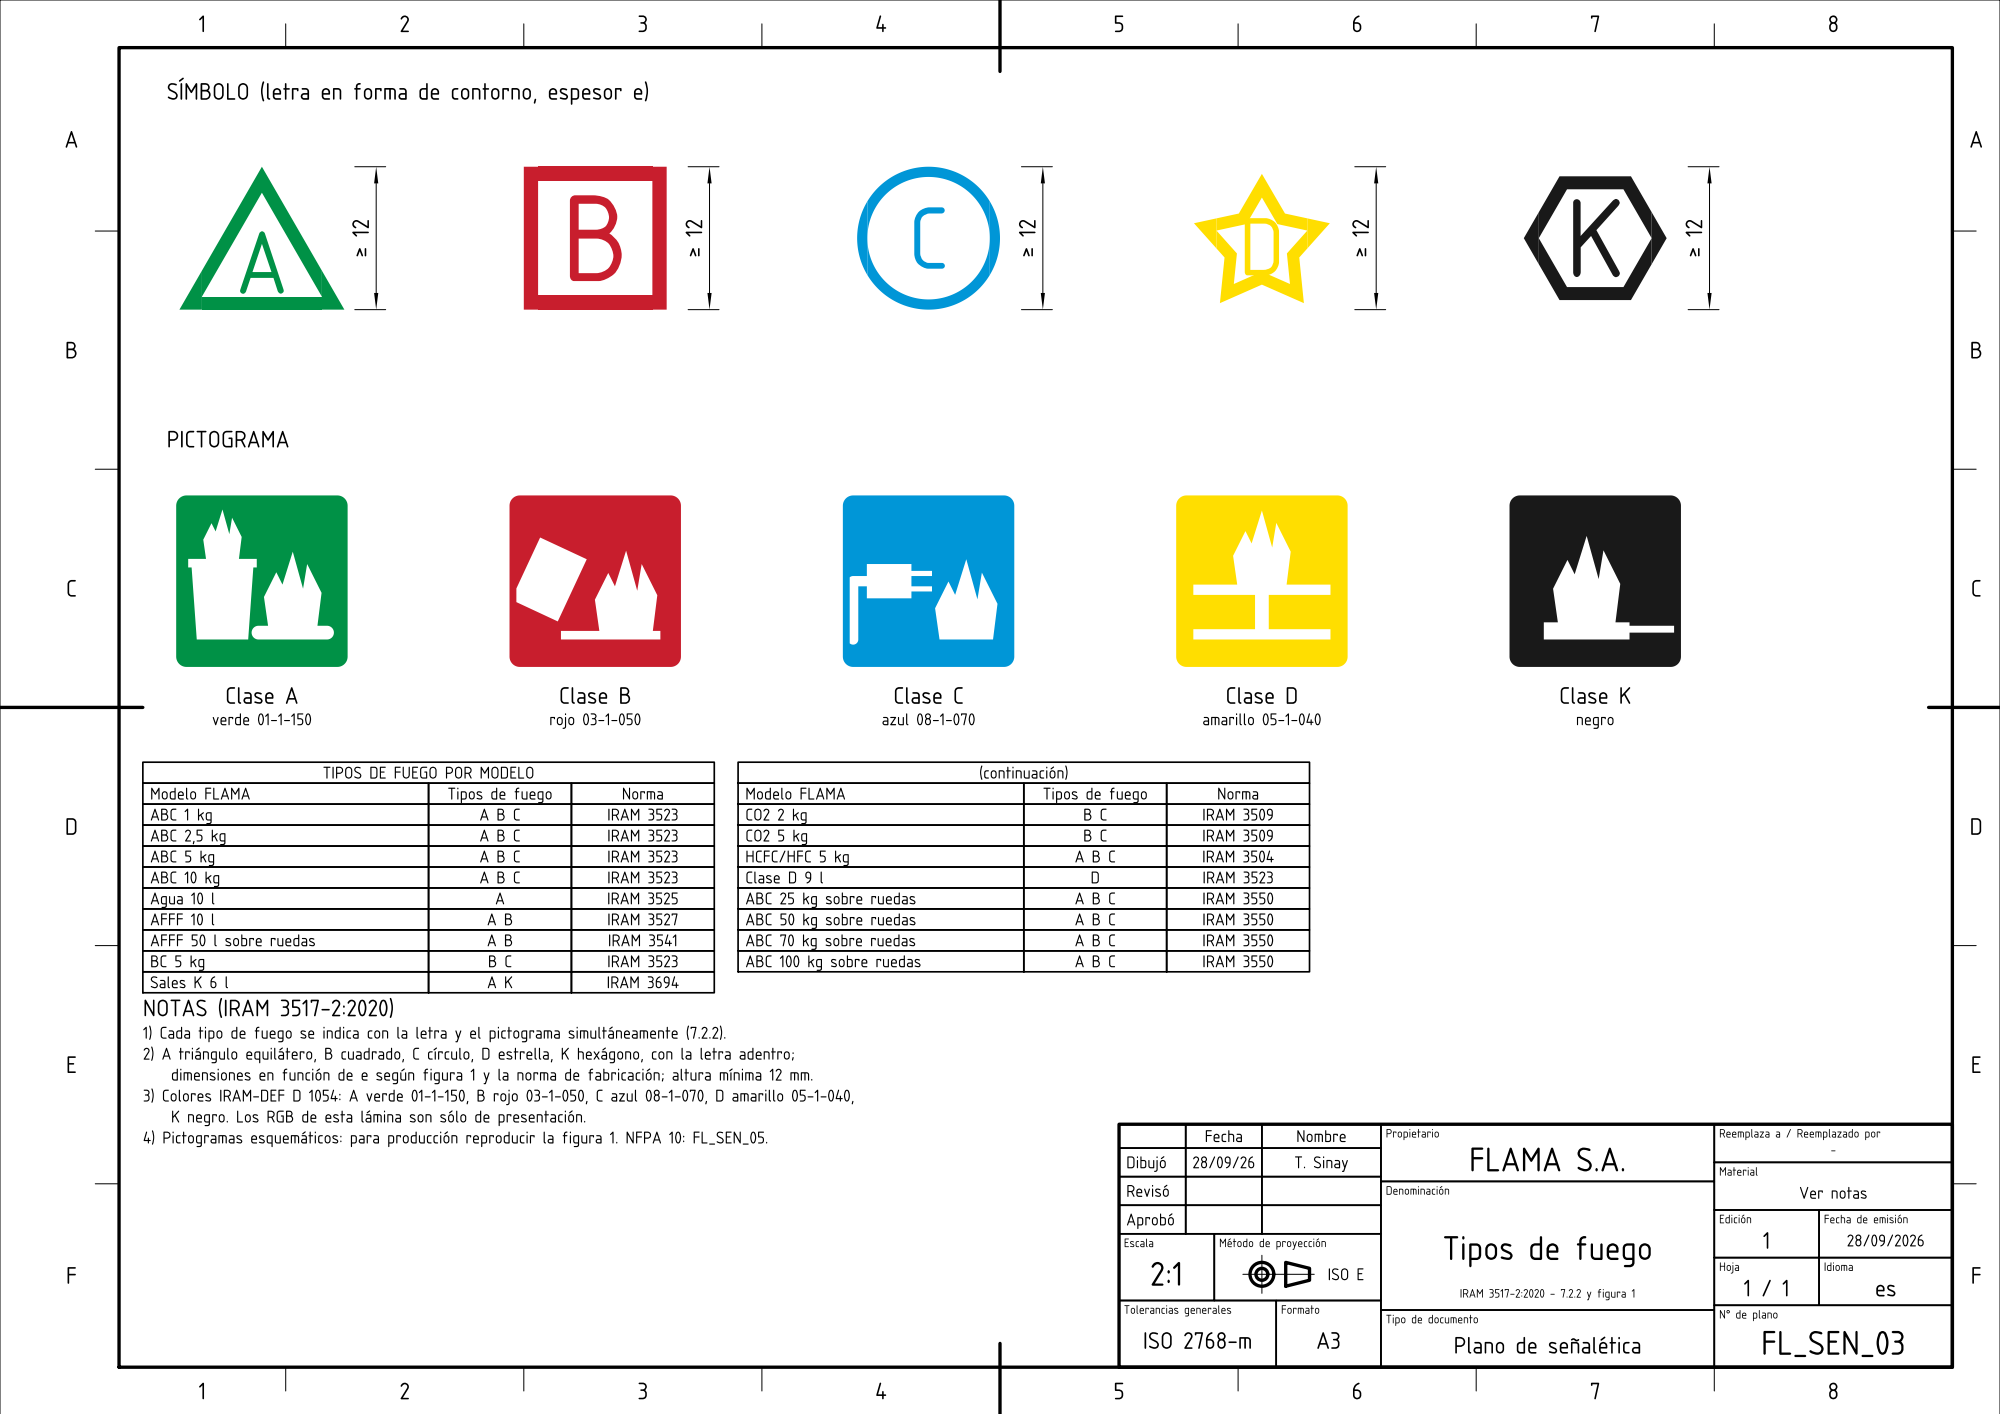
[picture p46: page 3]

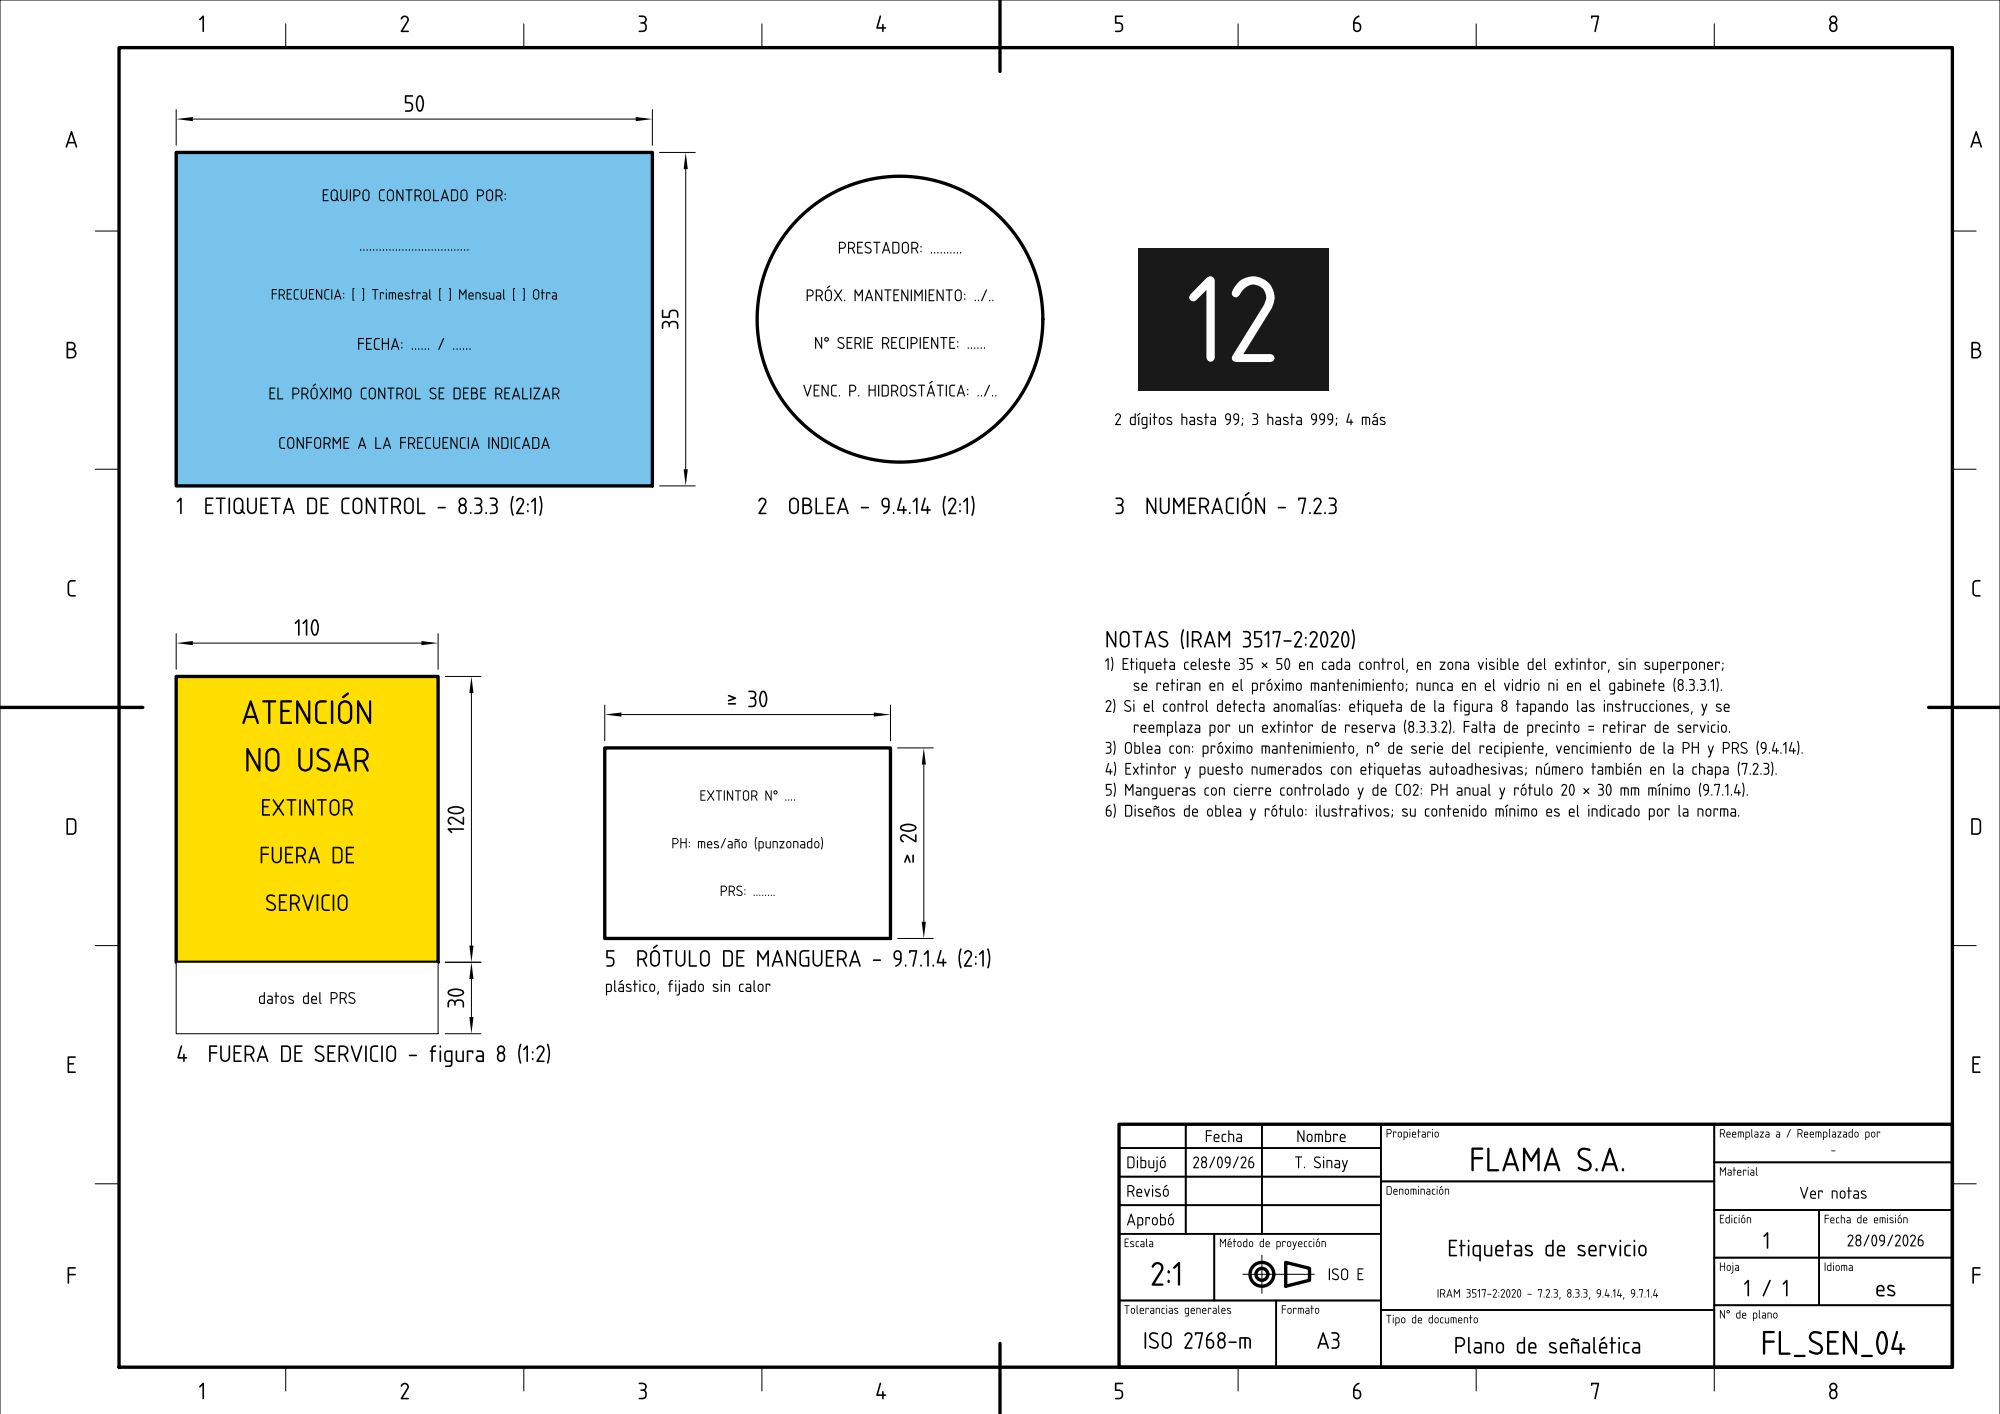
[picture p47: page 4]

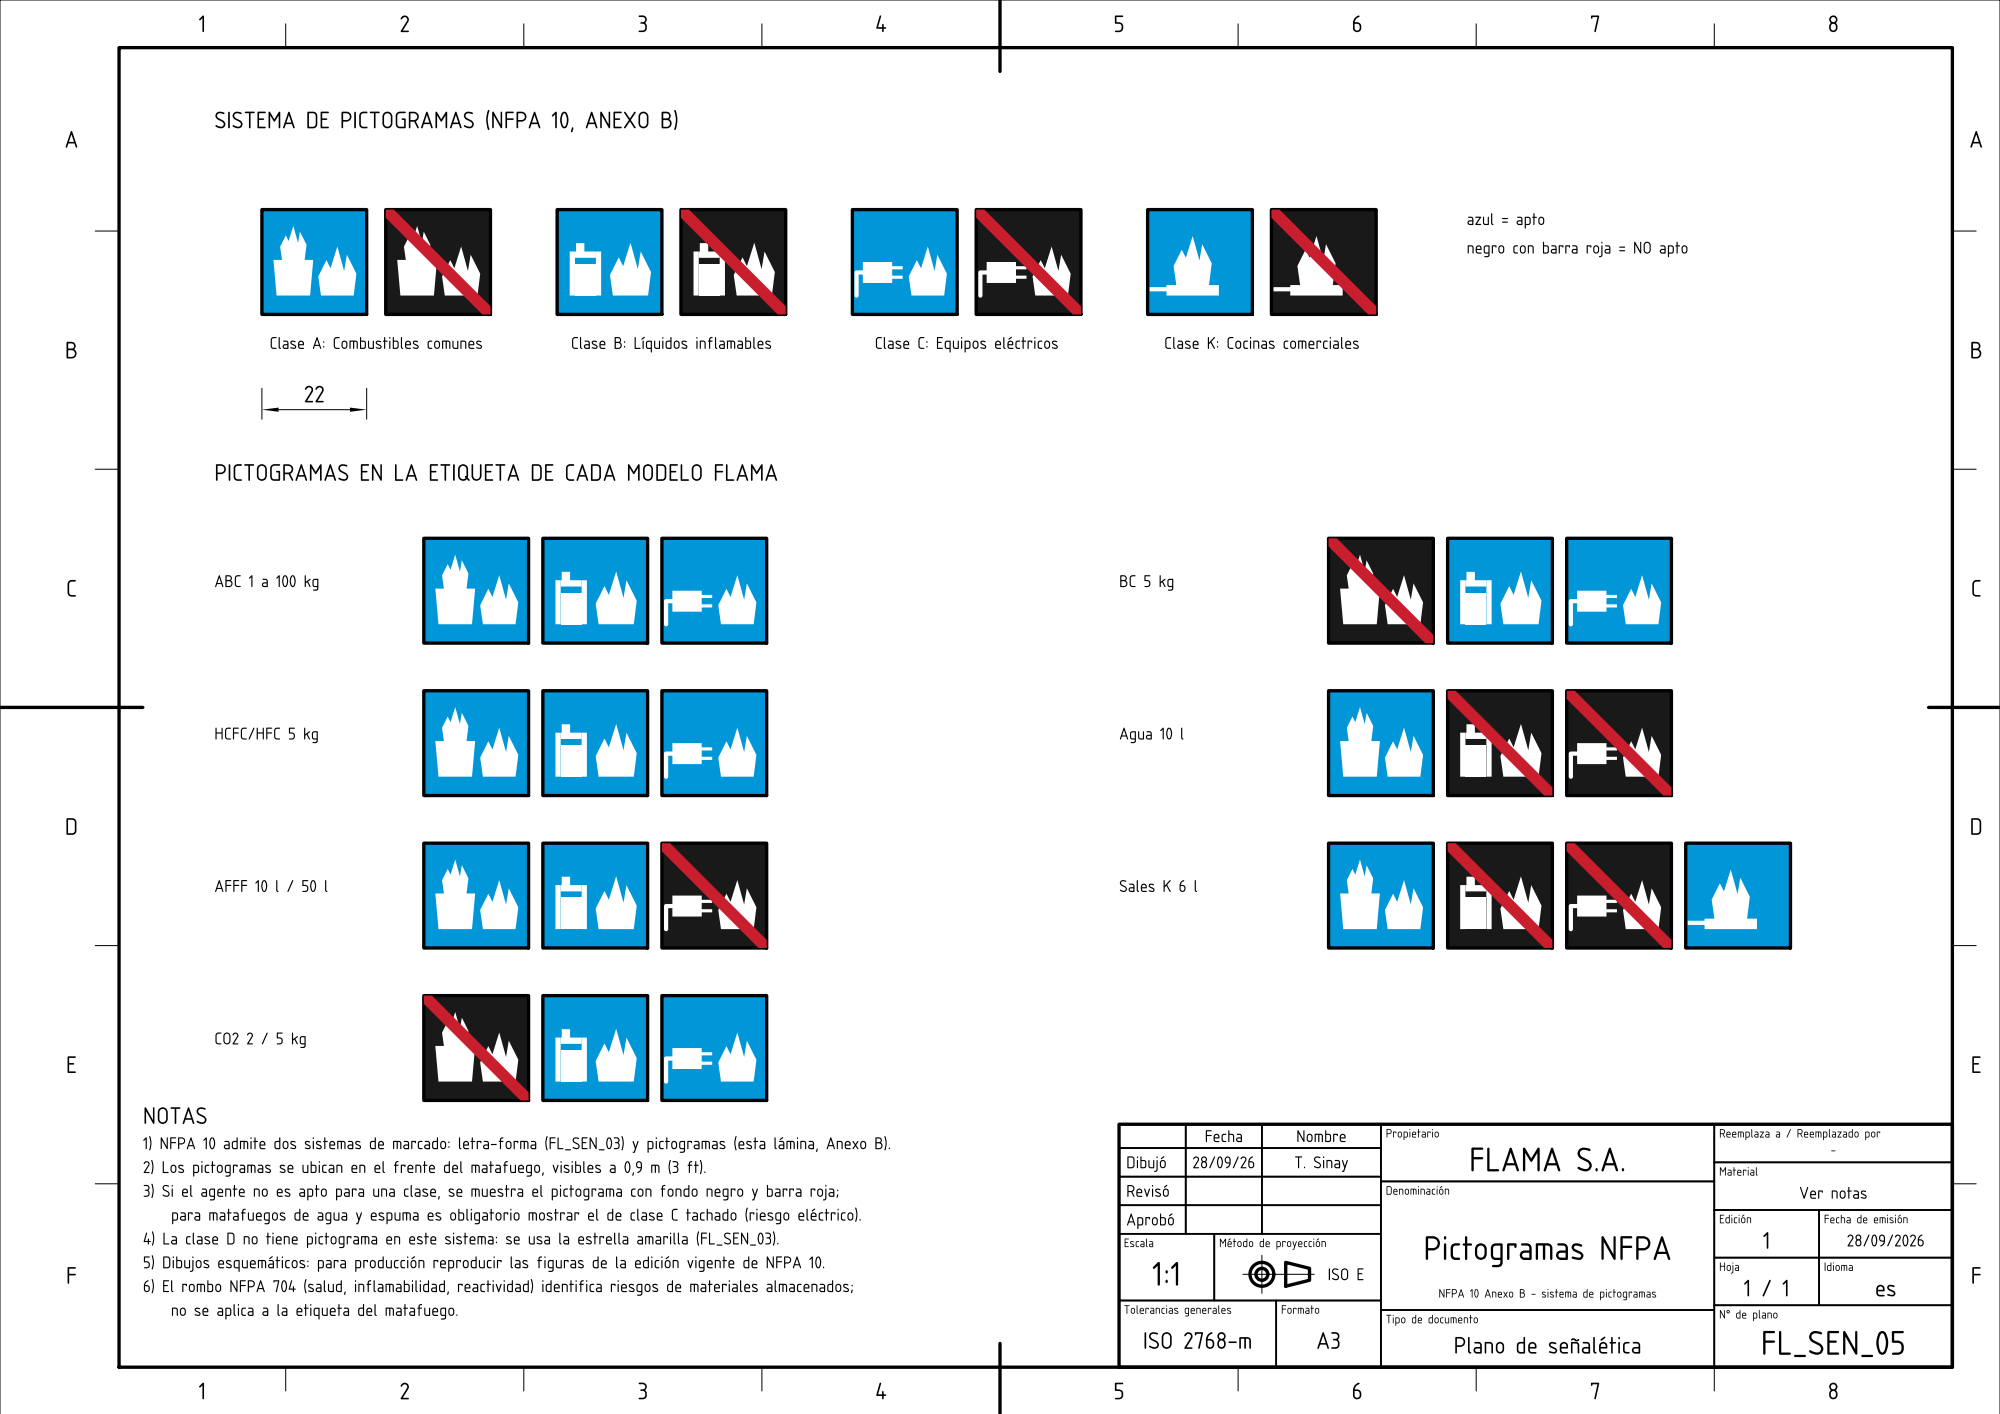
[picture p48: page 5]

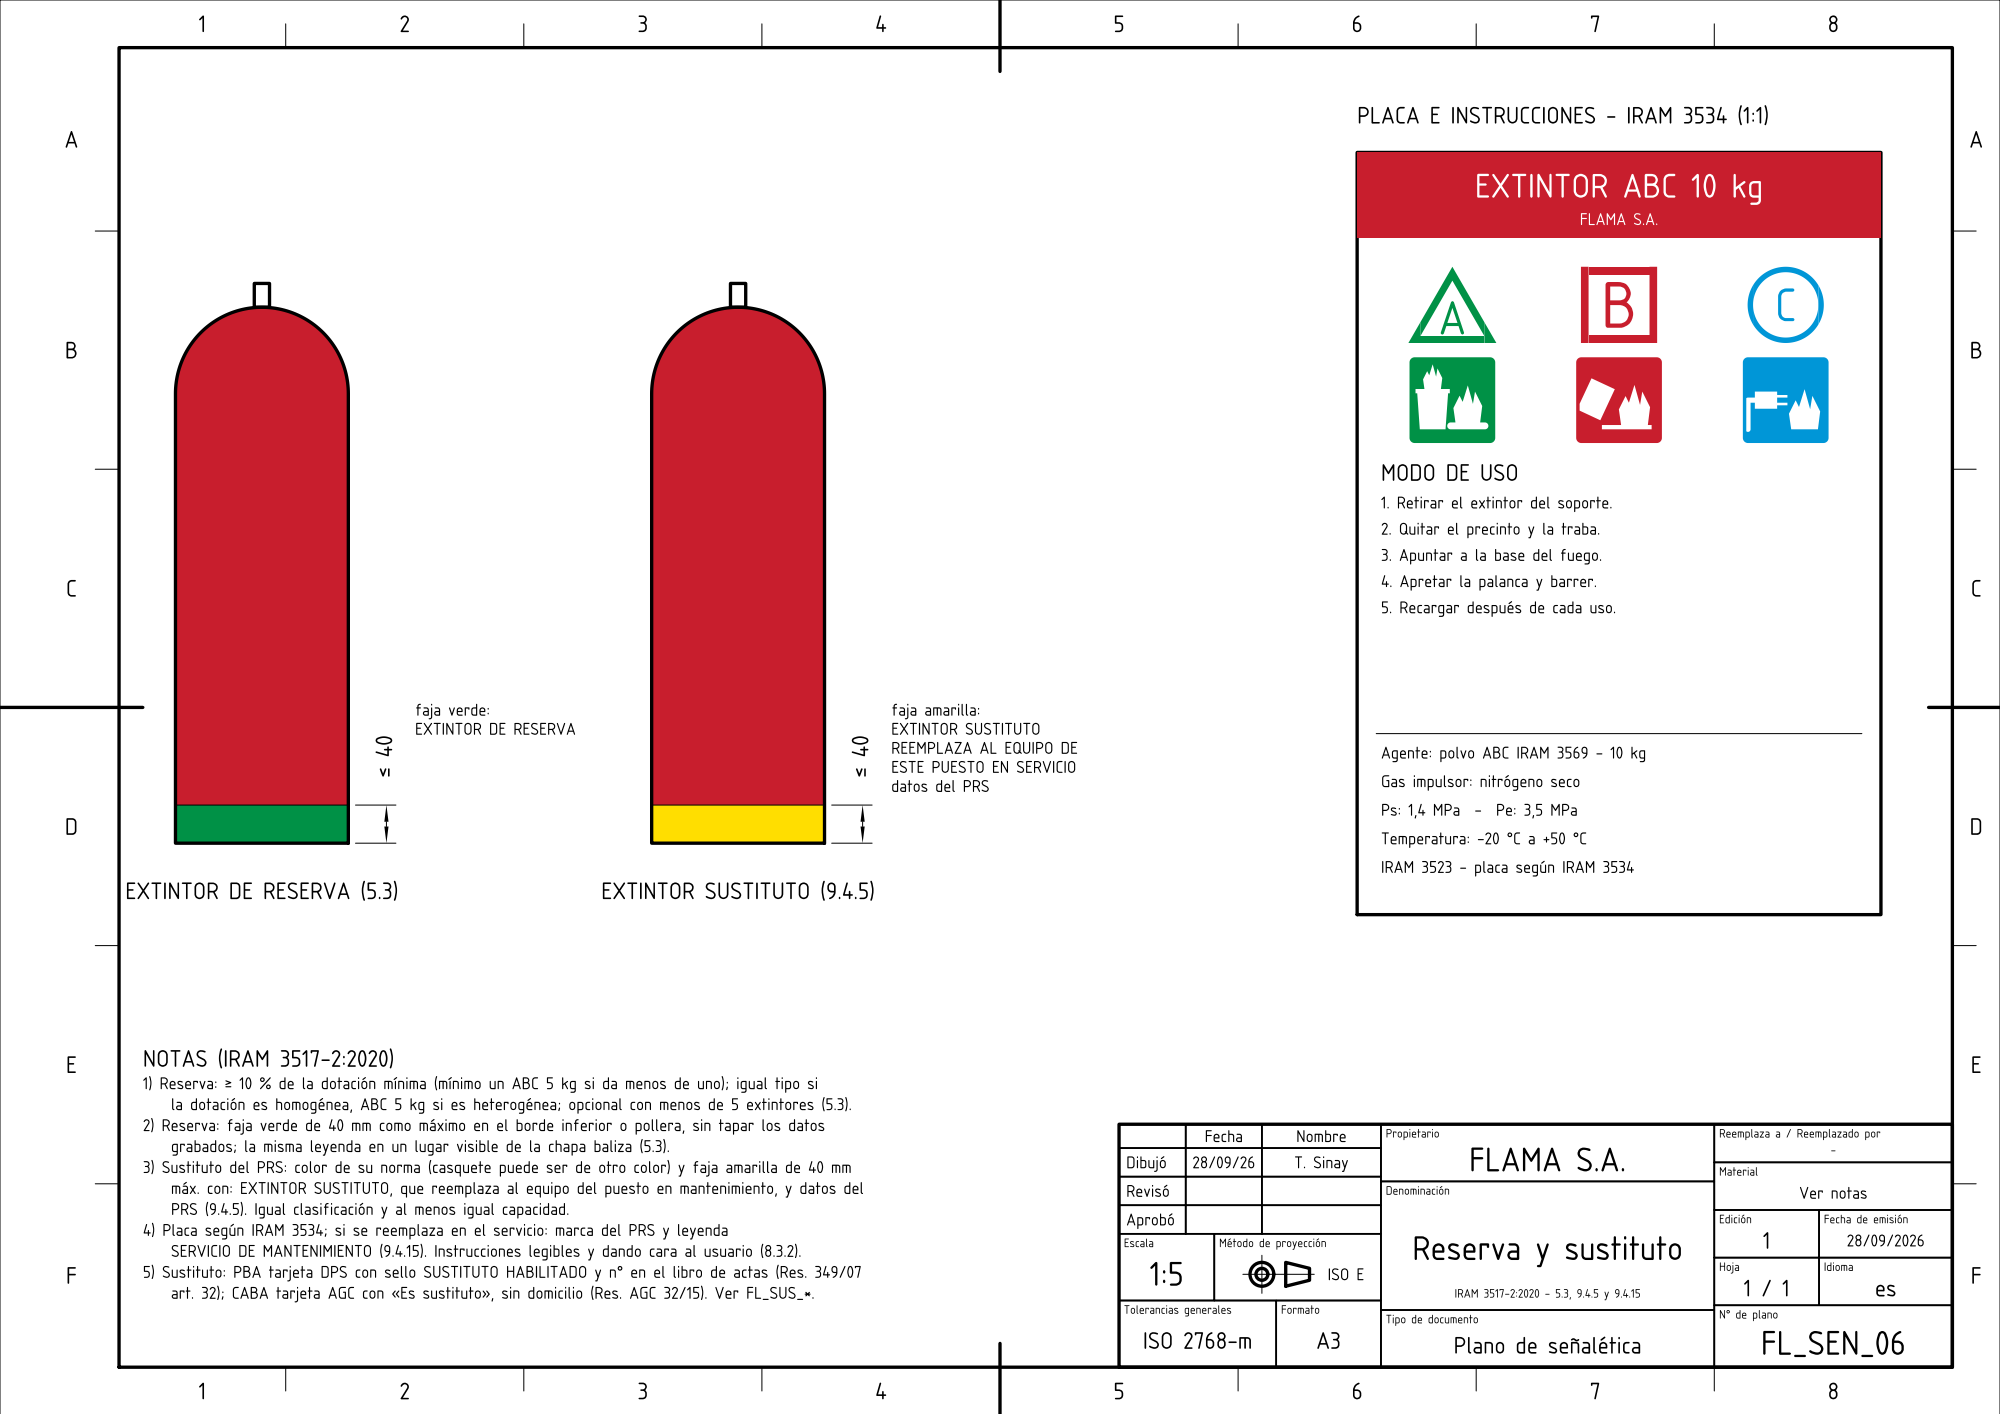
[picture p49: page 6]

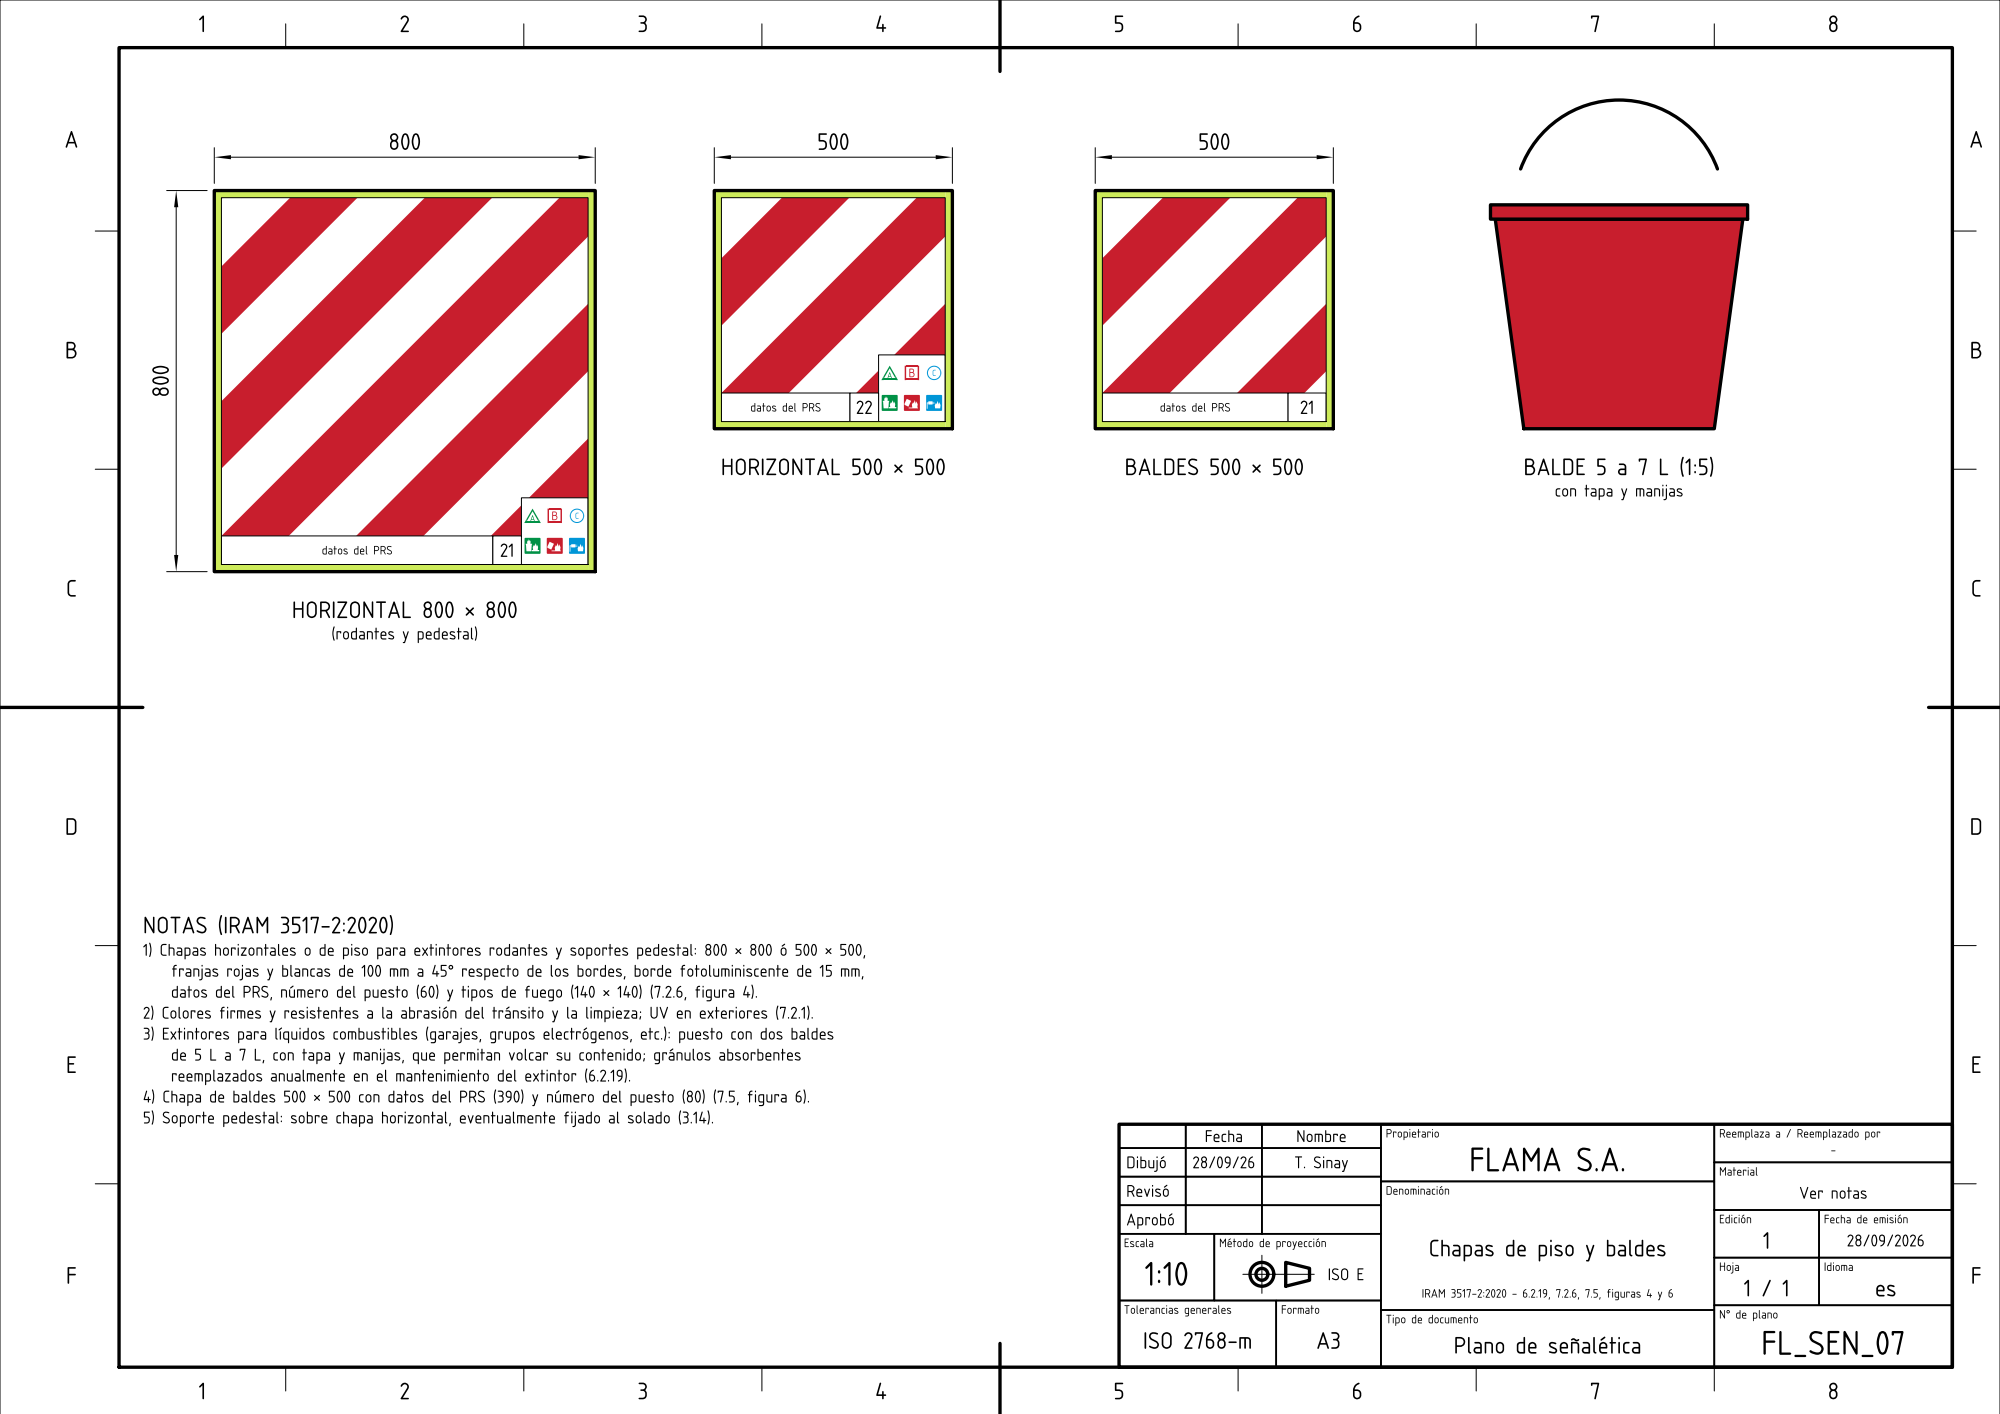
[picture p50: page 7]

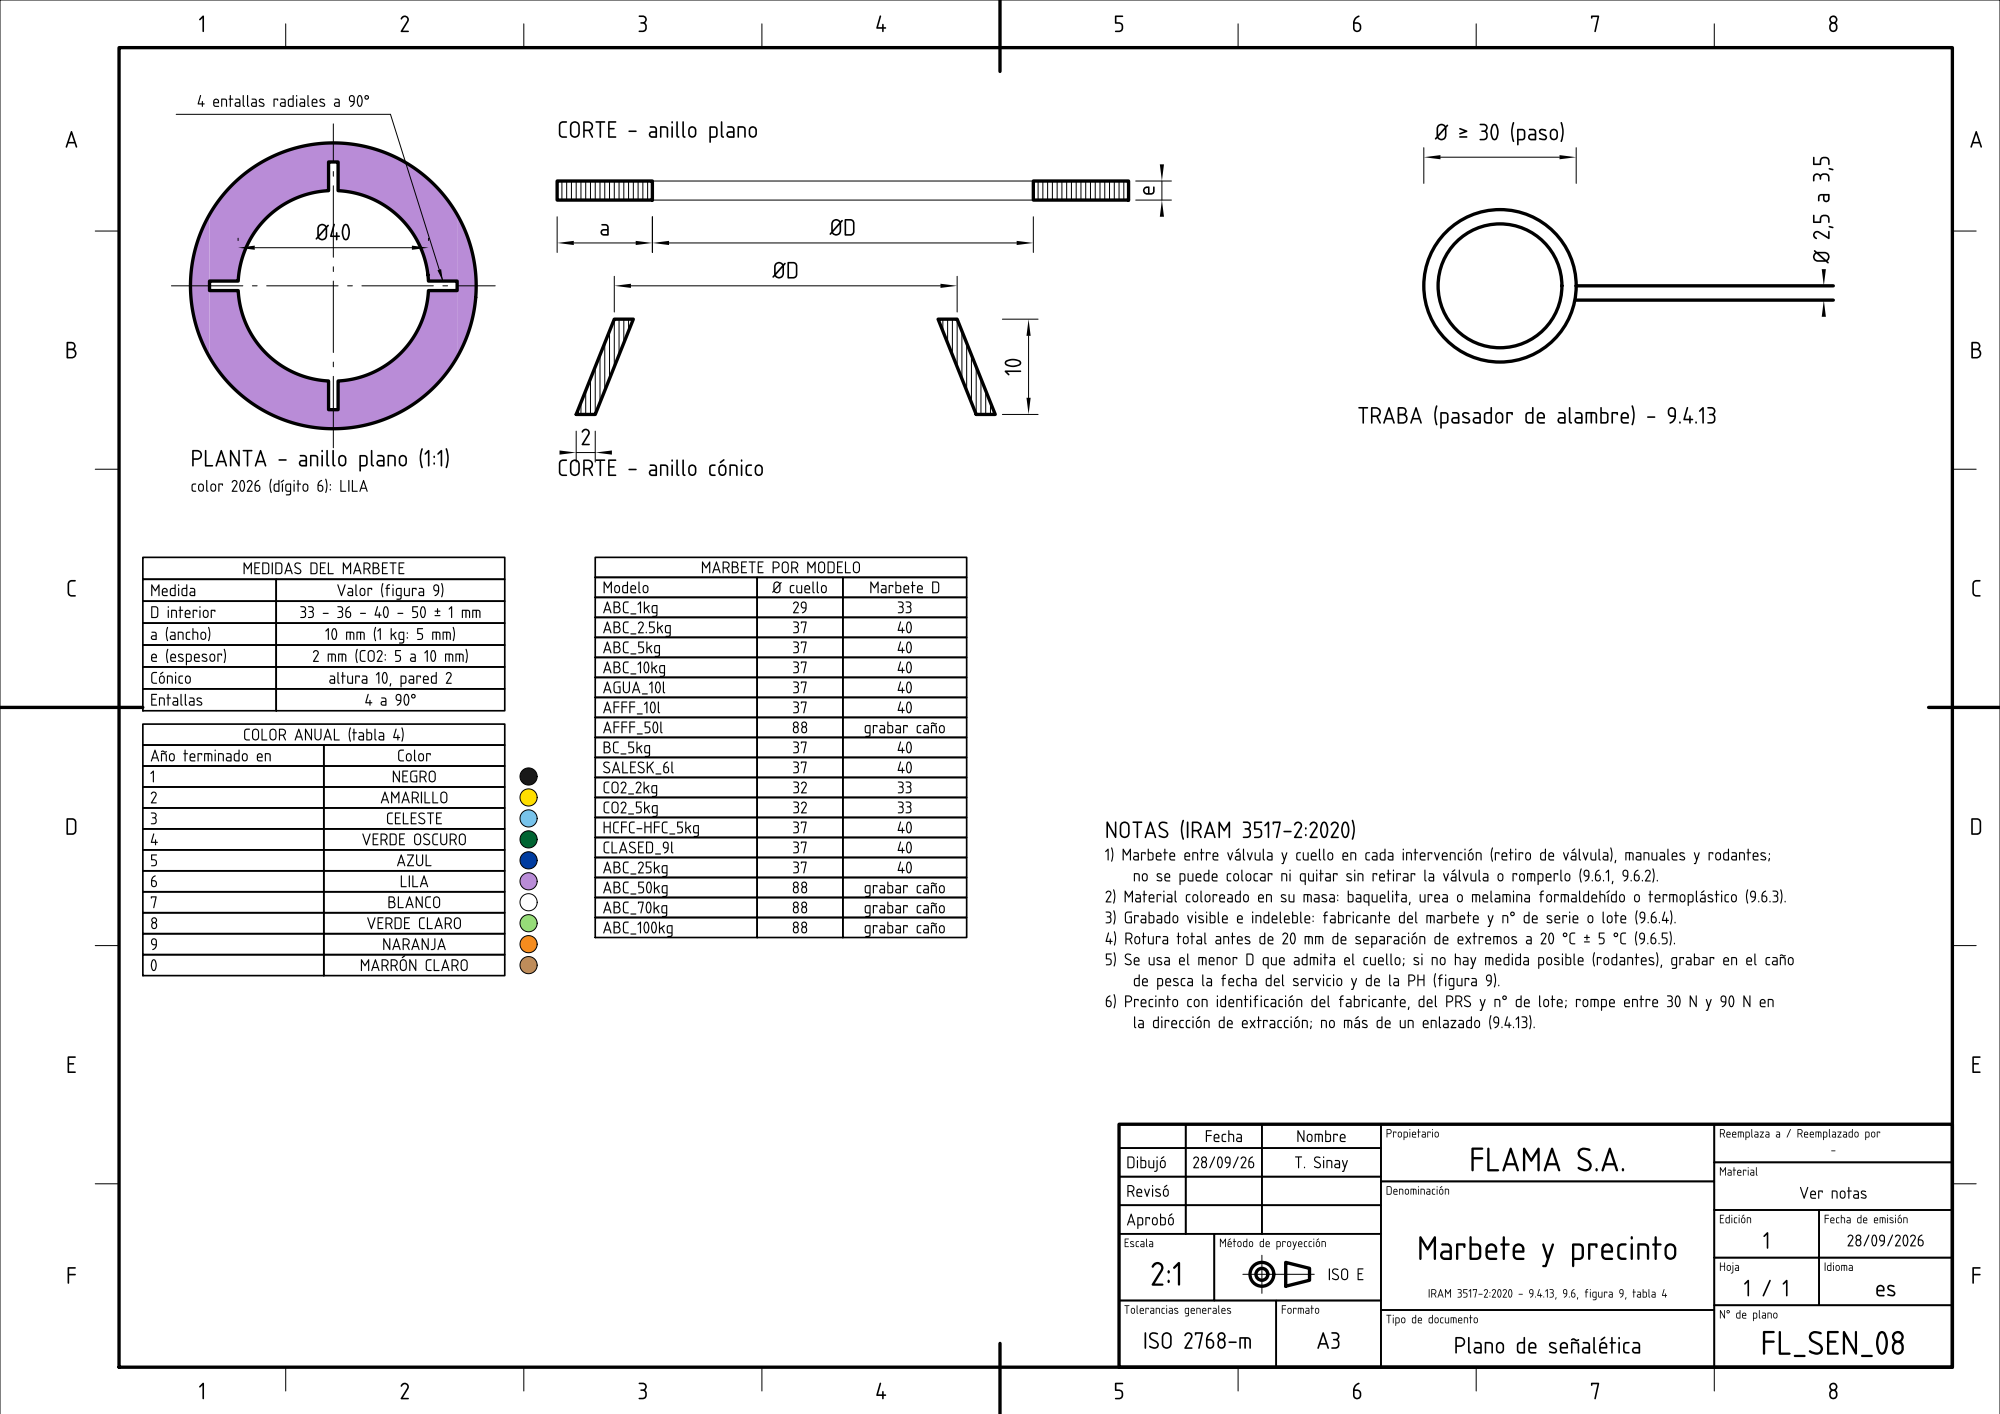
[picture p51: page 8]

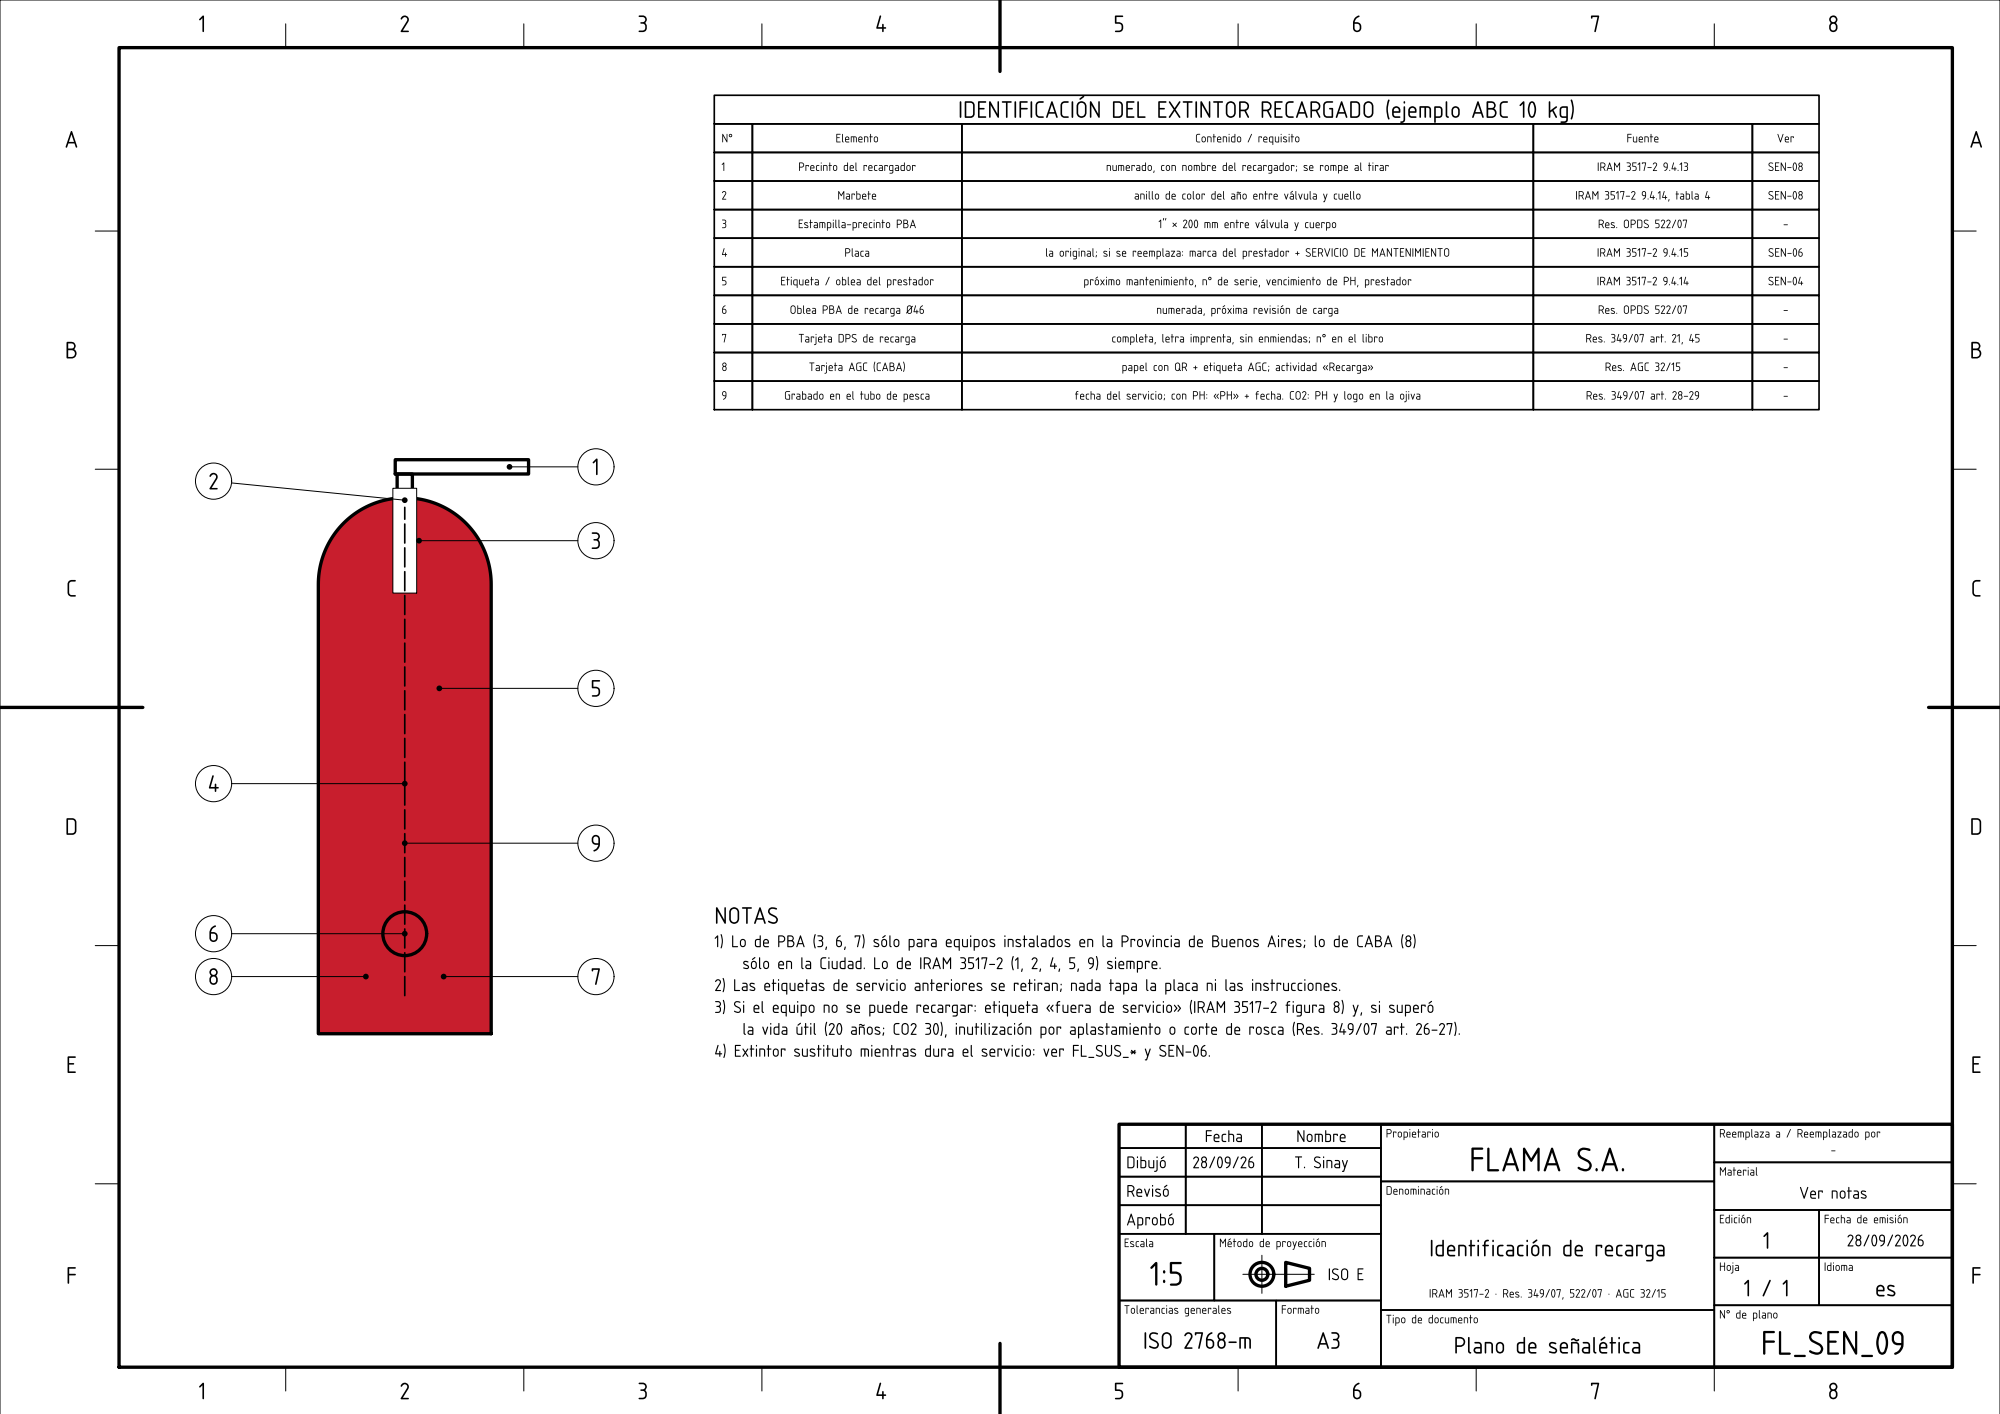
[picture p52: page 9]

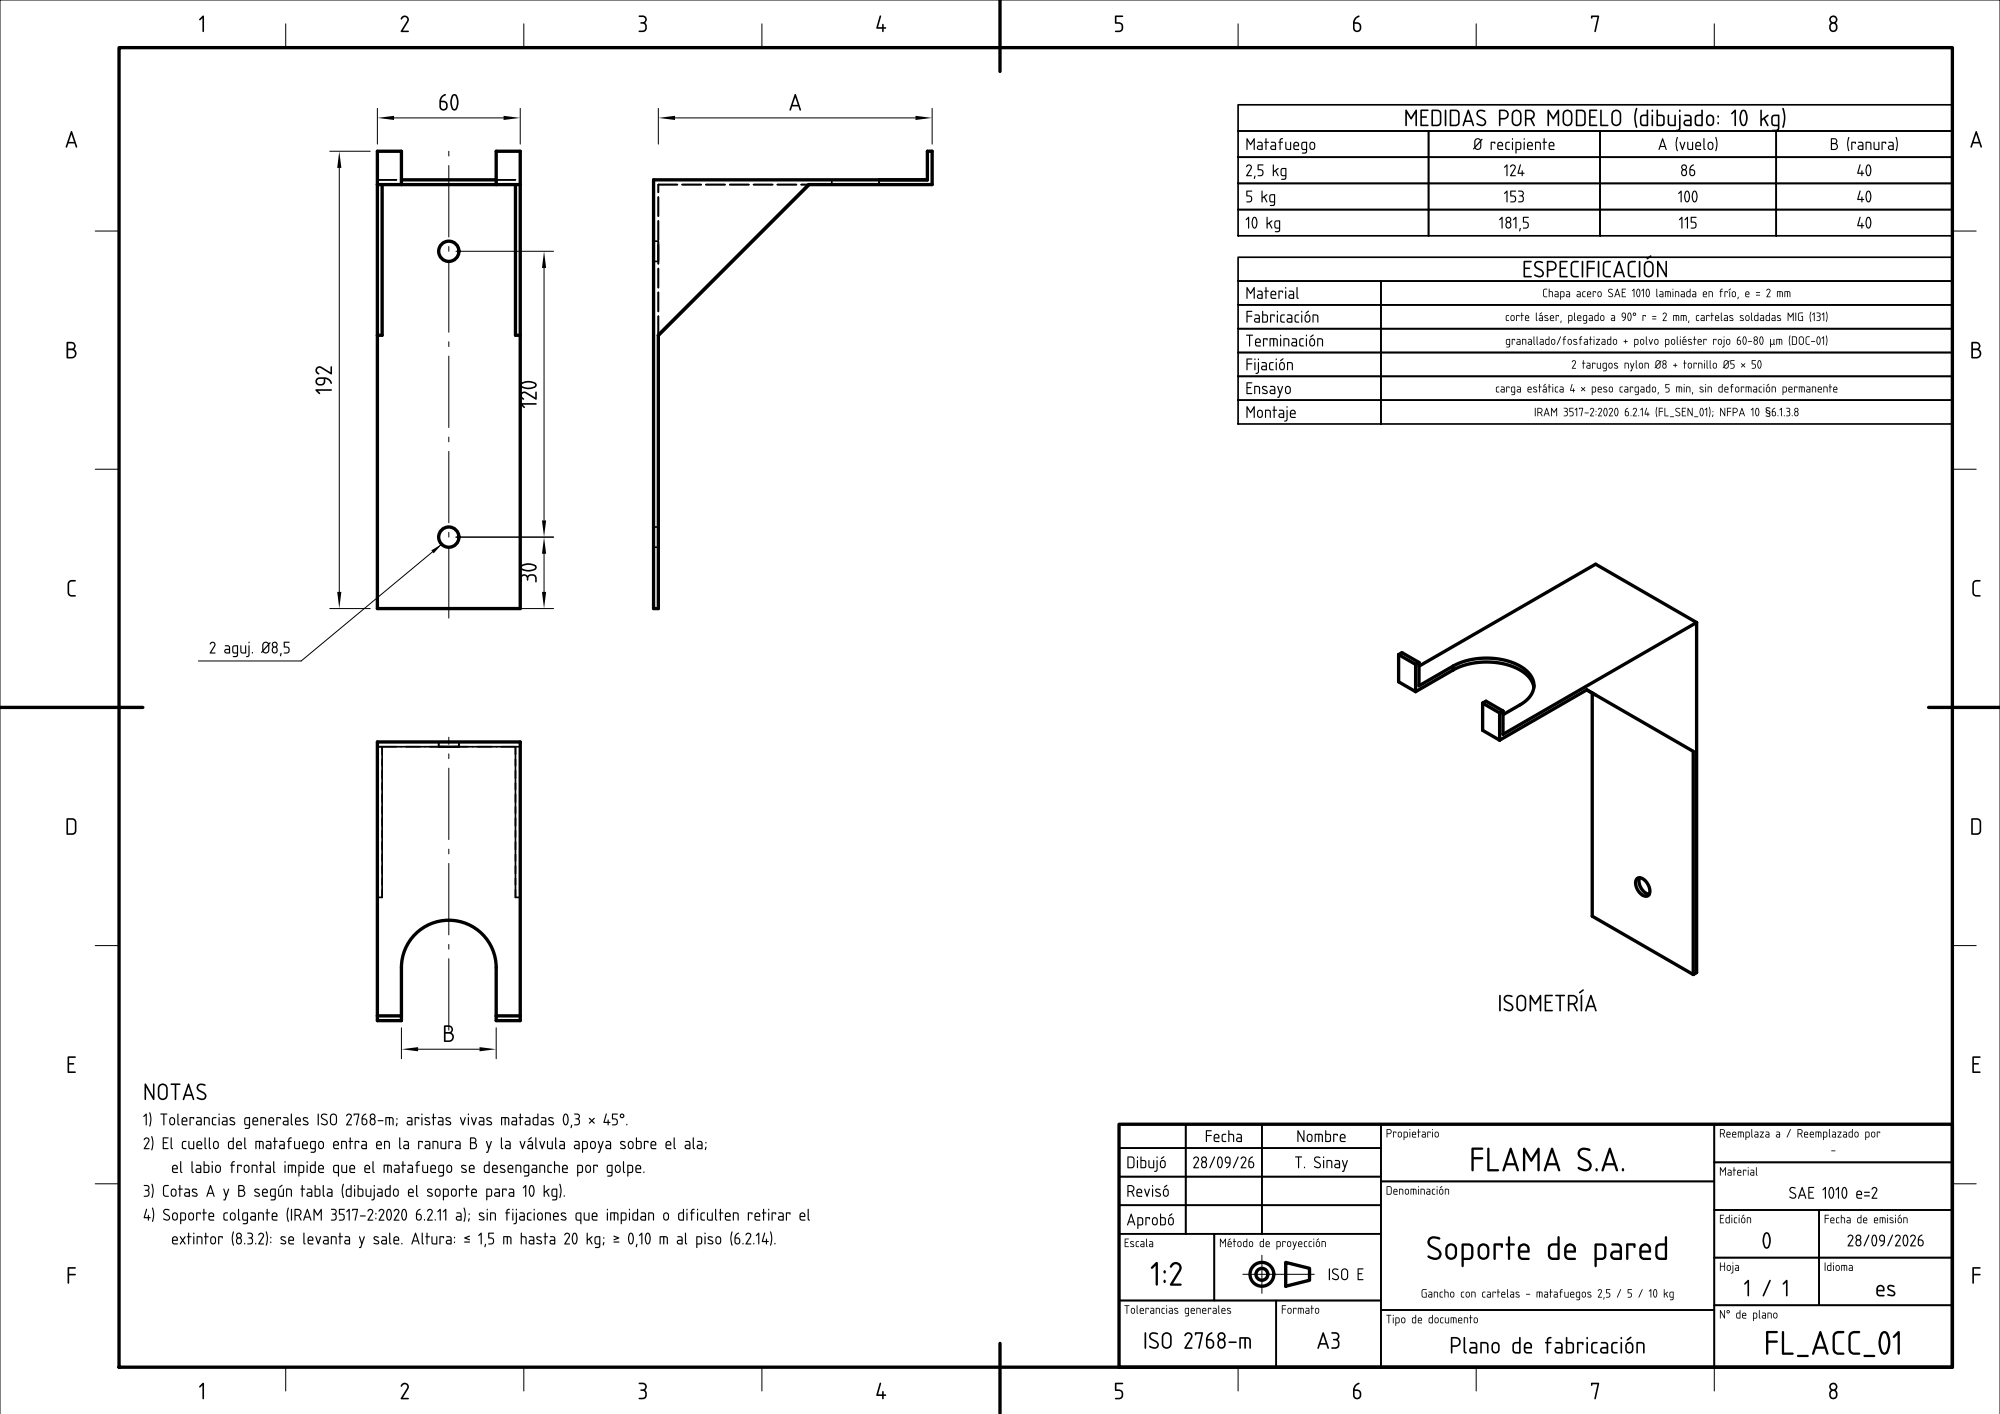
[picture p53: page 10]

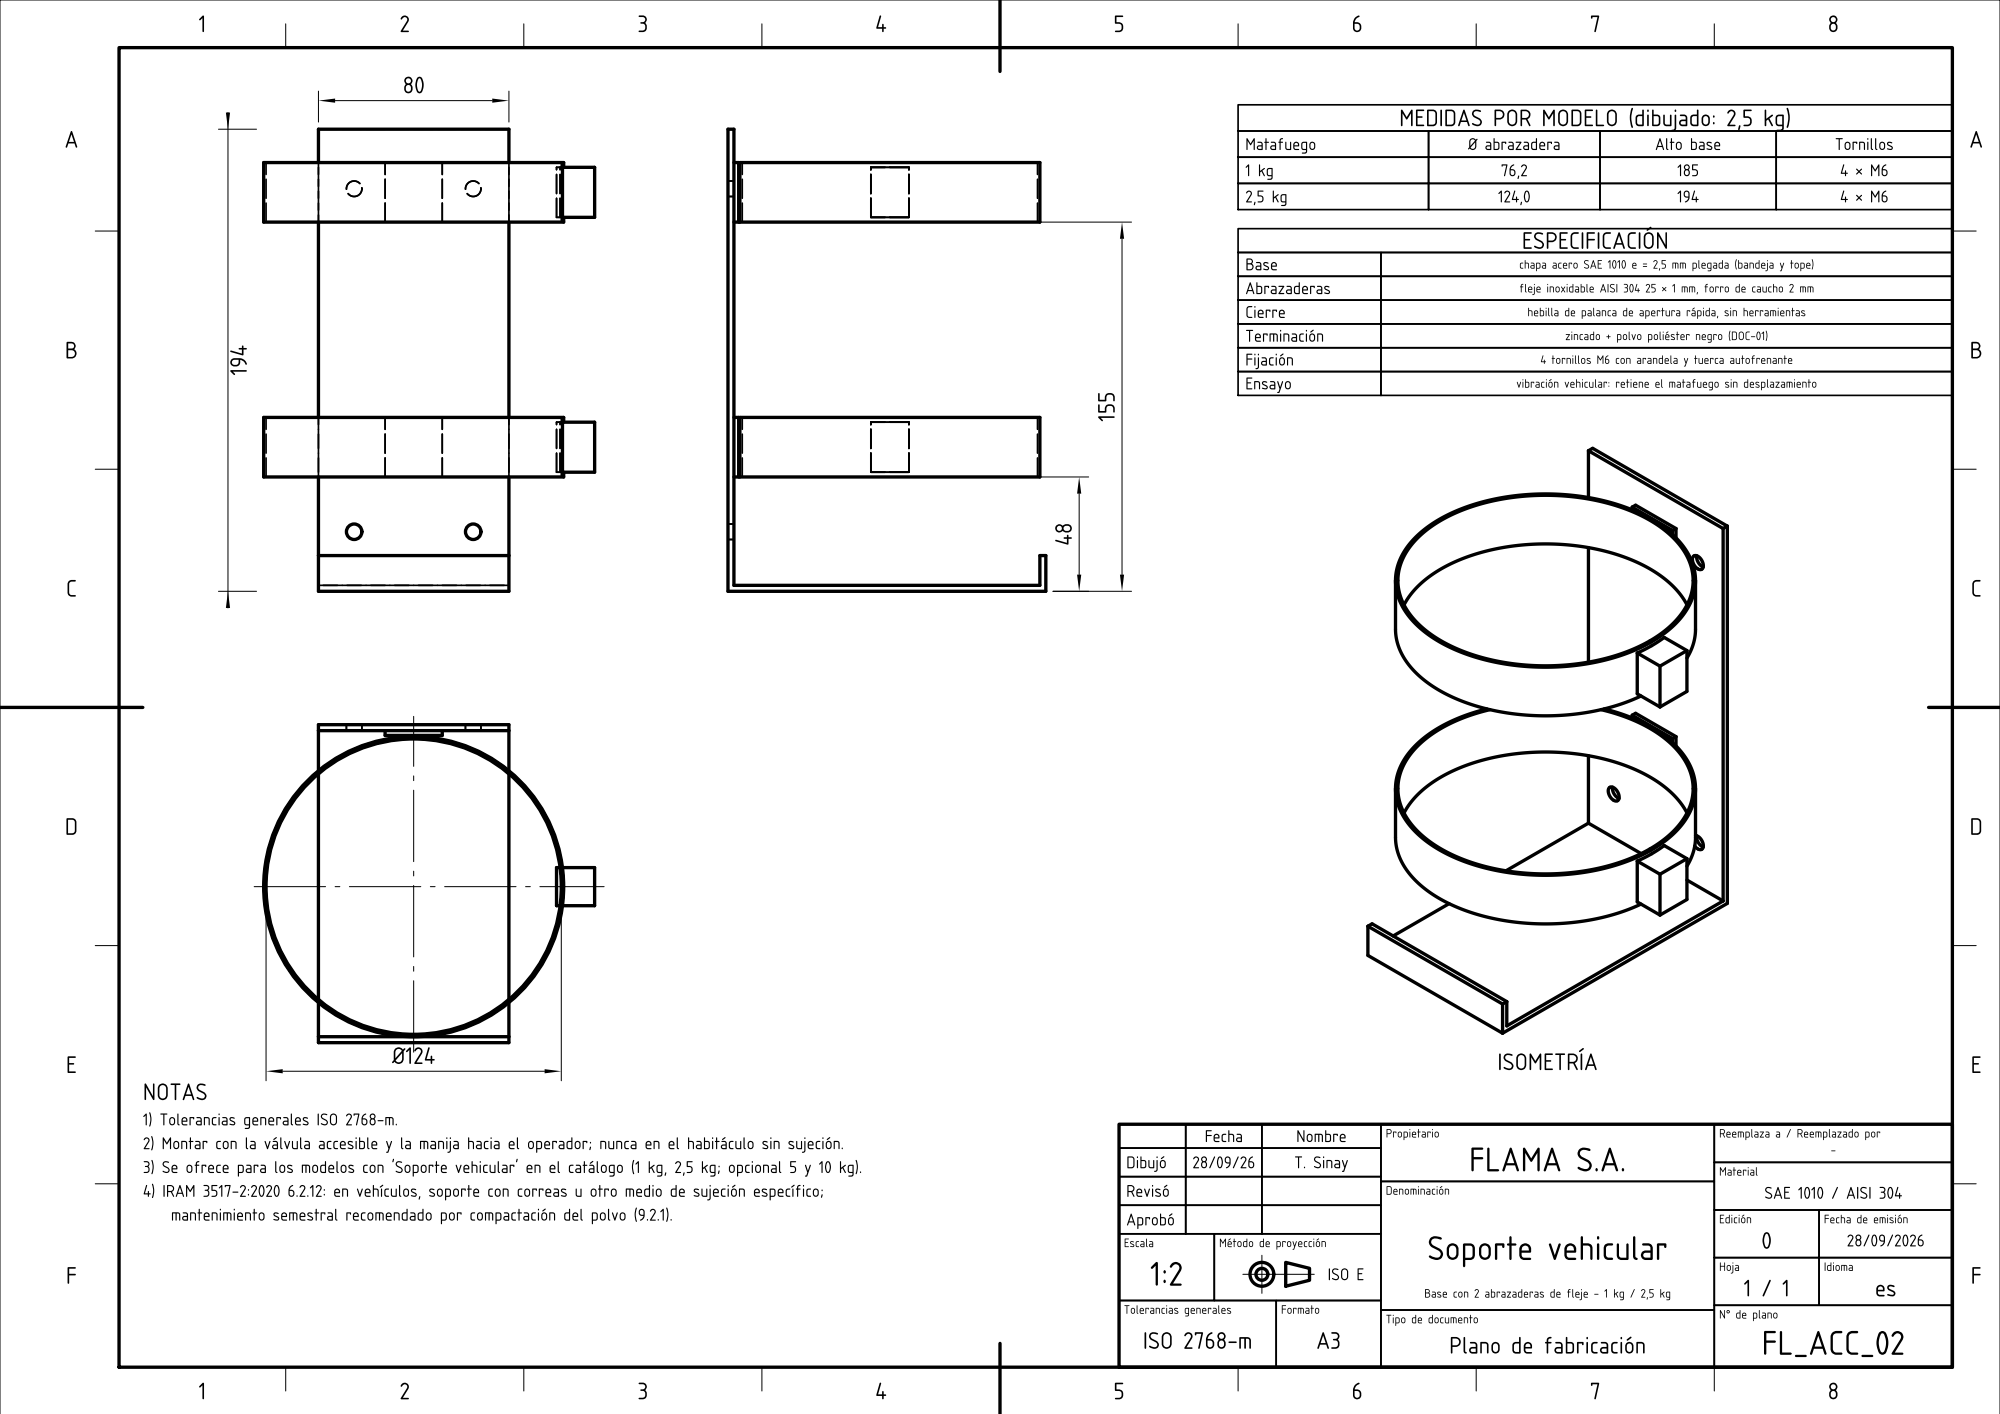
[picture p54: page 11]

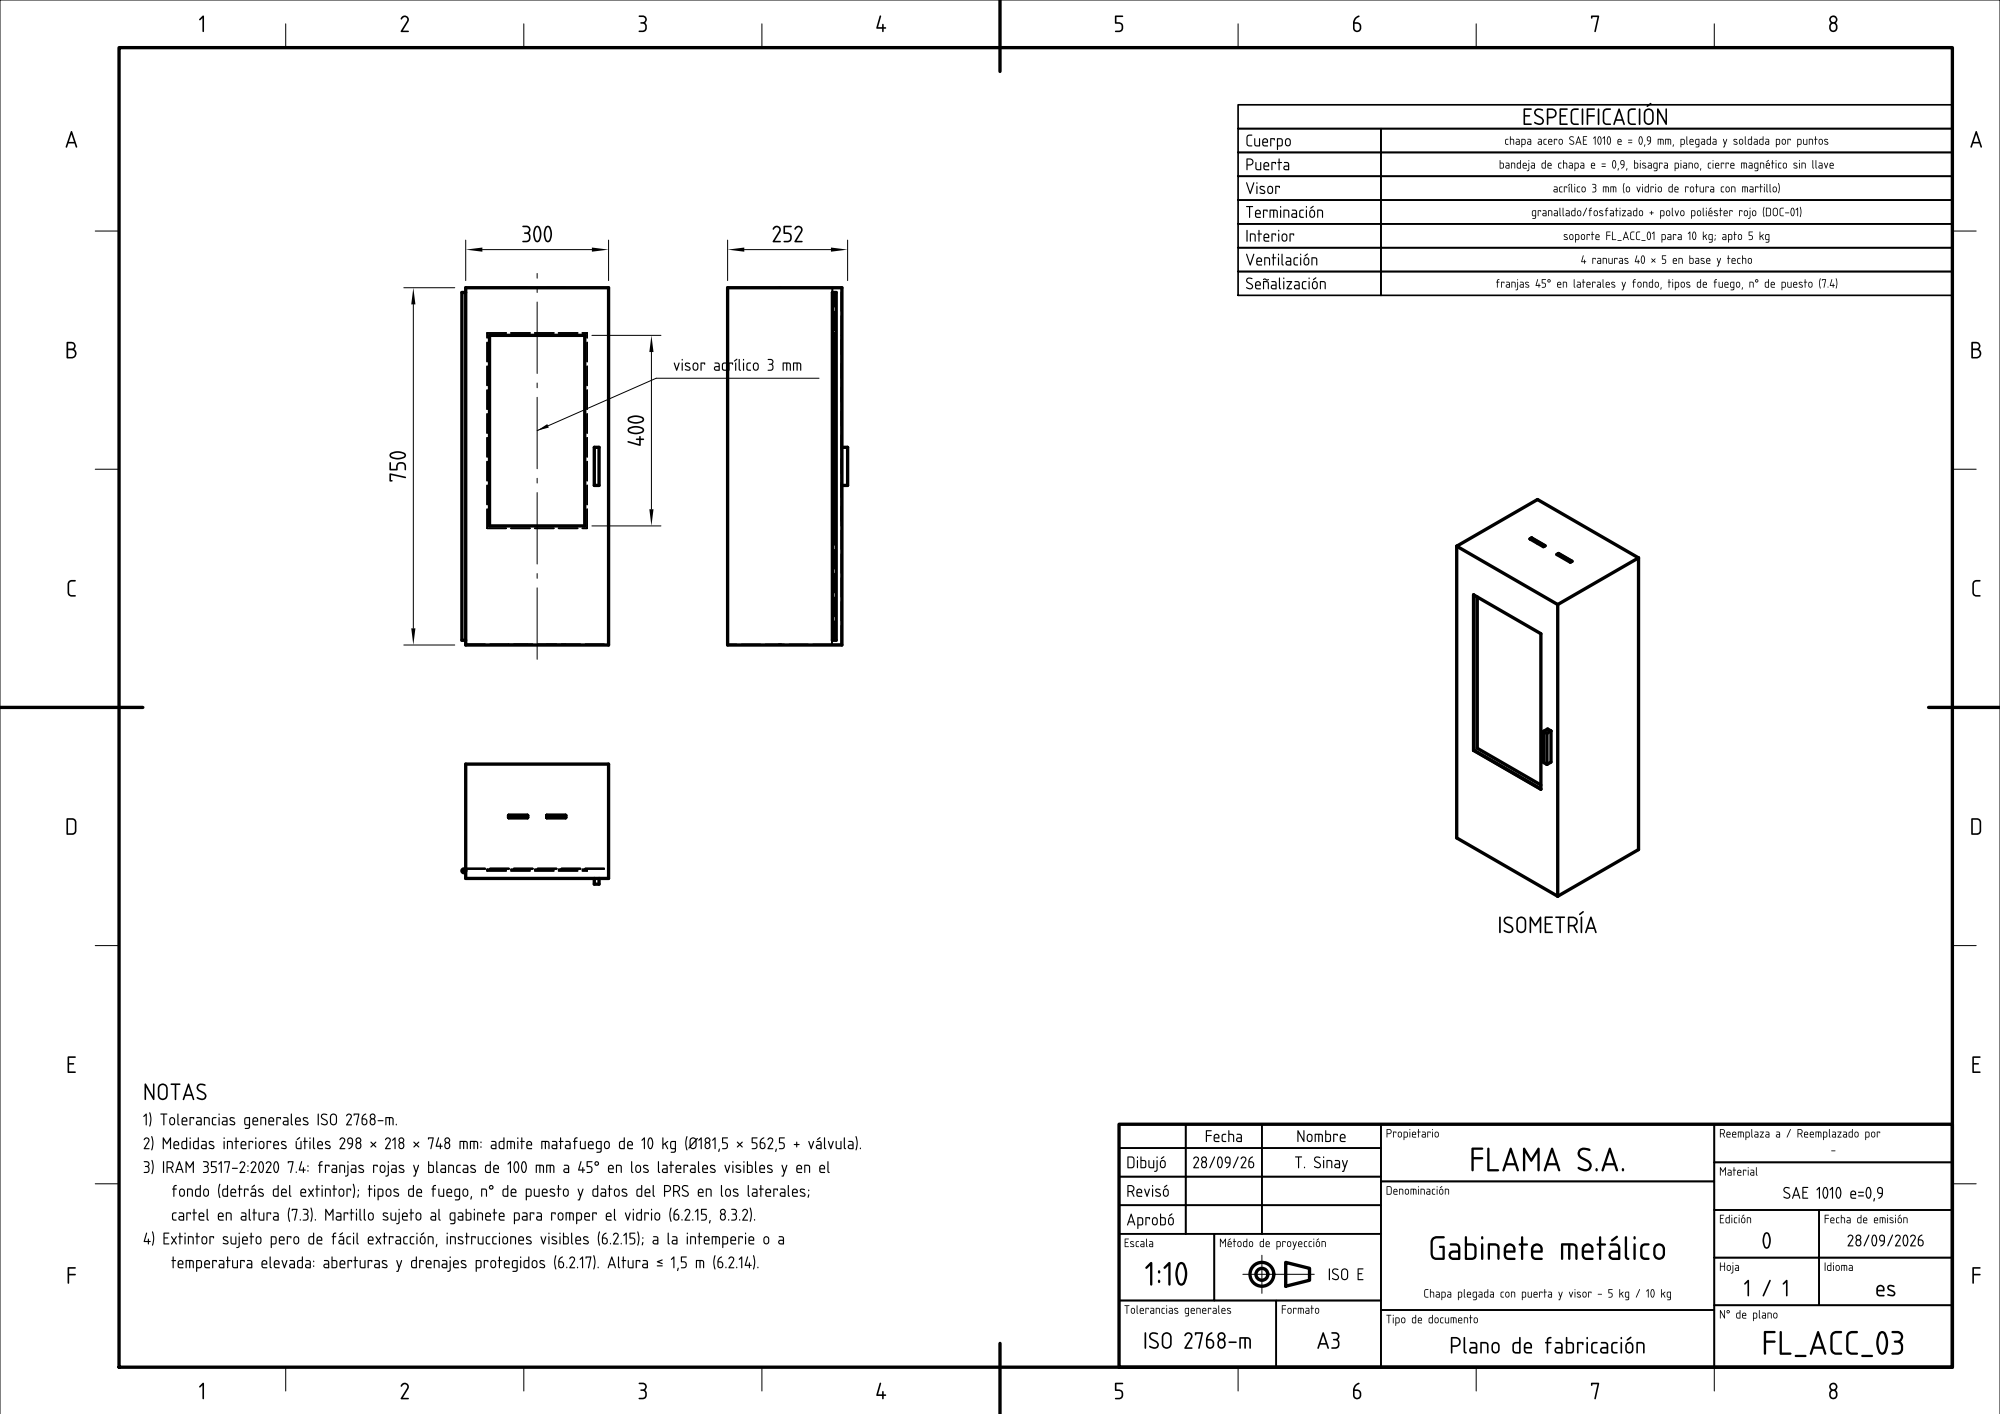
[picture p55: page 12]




FLAMA S.A. | Tratamiento superficial y pintura | DOC-01
Edición 0 | Recipientes, soportes y gabinetes FLAMA | 28/09/2026

# Tratamiento superficial, pintura y saponificación

## 1. Alcance

Preparación de superficie y pintura exterior de recipientes de acero al carbono (ABC, BC, HCFC/HFC, clase D, rodantes), cilindros de CO2, soportes y gabinetes; terminación de recipientes de acero inoxidable (agua, AFFF, sales K). El interior de los recipientes no se pinta salvo indicación del plano.

## 2. Secuencia de proceso (acero al carbono)

Paso | Operación | Especificación | Fuente
1 | Desengrase | Alcalino por aspersión o inmersión; enjuague. Superficie libre de aceite (ensayo de gota de agua). | R
2 | Granallado | Granalla de acero angular (ISO 11124-3), grado Sa 2½ (ISO 8501-1). Perfil de rugosidad fino a medio (comparador ISO 8503-1/-2), Rz ≈ 30 a 60 µm, adecuado a 60-100 µm de polvo. | N / R
3 | Limpieza de polvo | Aire seco sin aceite; polvo residual ≤ clase 2 (ISO 8502-3). | N
4 | Conversión (opcional) | Fosfatizado de hierro o zinc, o nanocerámico; mejora la adherencia y la resistencia a la corrosión bajo película. Enjuague con agua desmineralizada y secado. | R
5 | Tiempo de espera | Pintar dentro de las 4 h del granallado, con humedad relativa ≤ 85 % y temperatura de chapa ≥ 3 °C sobre el punto de rocío (ISO 8502-4). | N / R
6 | Pintura en polvo | Poliéster (TGIC-free, apto exterior) rojo 03-1-050 de IRAM-DEF D 1054 (IRAM 3504 6.3; 3517-2:2020 7.2.2), acabado brillante (3517-2 9.10). Espesor seco 60 a 100 µm. | N / R
7 | Curado | Según ficha técnica del polvo (típico 10 min a 180-200 °C de temperatura de pieza). Controlar con registrador de temperatura en pieza. | R

## 3. Acero inoxidable (agua, AFFF, sales K)

Recipiente AISI 304 soldado TIG (141). Después de soldar: decapado de las zonas térmicamente afectadas con pasta o gel de decapado y pasivado (ácido nítrico o cítrico, ASTM A967 / A380). Terminación exterior: pintura en polvo poliéster roja sobre imprimación compatible con inoxidable, o sin pintar con etiqueta roja según el diseño aprobado. Nunca granallar inoxidable con granalla de acero al carbono (contaminación con hierro); usar microesfera de vidrio u óxido de aluminio.

## 4. Controles de calidad de la pintura

Ensayo | Método | Criterio de aceptación | Frecuencia | Fuente
Espesor de película seca | ISO 2808 / ISO 19840 | 60 a 100 µm; ningún punto < 80 % del nominal | cada lote | R
Adherencia (cuadriculado) | ISO 2409 | clase 0 ó 1 | cada lote | N / R
Impacto | ISO 6272-1 | sin fisuras ni desprendimiento con la energía de la ficha del polvo | por partida de polvo | R

FLAMA S.A. · DOC-01 · página 1 de 2

Grado de curado | frote con MEK (ASTM
D5402)

sin ablandamiento ni pérdida de brillo

cada turno | R
Brillo y color | ISO 2813 / ISO 7724 | rojo 03-1-050 (IRAM-DEF D 1054), brillante; ΔE ≤ 1,5 contra patrón | cada lote | N / R
Niebla salina | IRAM 121 / ISO 9227 (NSS) | IRAM 3504 5.1.5: 96 h sin corrosión galvánica y recubrimiento adherido; 240 h sin corrosión del recipiente. FLAMA: 500 h, ampollamiento 0(S0) ISO 4628-2; avance en la incisión ≤ 2 mm (ISO 4628-8) | semestral / cambio de proceso | R
Resistencia a agentes extintores | ISO 2812-4 (gota) | 24 h de contacto con cada agente del tipo: sin ablandamiento, ampollas ni cambio de color | calificación de polvo | R
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










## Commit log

2026-09-28 Planos FLAMA S.A.: 17 extintores, 3 hojas c/u (vistas ISO E, corte y detalles, especificaciones), STEP y DXF 3D
    Generador paramétrico: sólidos OpenCascade -> proyección HLR -> DXF con
    rótulo IRAM 4508, capas IRAM 4502, cotas IRAM 4513, escalas IRAM 4505.
    Incluye scripts para AutoCAD 2027 y verificación dimensional contra catálogo.
    Claude-Session: https://claude.ai/code/session_01E33CYXtZ2f33D1RjoRdR65
    [FL-ABC-001.step, FL-ABC-001_3D.dxf, FL-ABC-001_H1.dxf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]
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2026-09-29 autocad_mcp: 22 herramientas con validación, anotaciones, paginación y evaluación
    - nombres con prefijo autocad_, parámetros Pydantic, errores accionables
    - dibujo 2D, sólidos 3D (caja, cilindro, revolución, booleanas), consulta paginada
    - fija mcp<2 (el SDK 2.x renombró FastMCP y el servidor no arrancaba)
    - evaluacion.xml con 10 preguntas verificadas contra los DXF
    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
2026-09-29 Nomenclatura FL_MAT_<TIPO>_<tamaño> y un plano por matafuego (3 presentaciones)
    - 17 planos: FL_MAT_*.dxf con Hoja1_Conjunto, Hoja2_Corte_Detalles y
    Hoja3_Especificaciones; PDF de 3 páginas por plano
    - el código es también el N° de plano del rótulo; título y código se
    ajustan al ancho de la celda
    - .bat y MCP adaptados (convierte los 17 planos a DWG, abre por hoja)
    - verificación: 17 planos / 51 láminas sin errores
    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
    [FL-ABC-001.step, FL-ABC-001_3D.dxf, FL-ABC-001_H1.dxf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]
2026-09-29 Planos según IRAM: recuadro 25/10, rótulo 175x51, lista con peso, líneas 4:2:1, flechas 1:4
    - IRAM 4504/4508/4502/4509/4513: márgenes, rótulo y lista de materiales con código y
    peso calculado, grupo de líneas 0,7/0,35/0,18 con ocultas en línea media, flecha 1:4
    - cada tipo con su descarga: tobera polvo, chorro pleno, lanza espumígena, lanza K,
    lanza clase D, difusor CO2 con empuñadura y soporte; inox con costura TIG (141)
    - materiales definidos para todas las piezas y verificación de masa contra catálogo
    - composición centrada: formato/escala automáticos, isometría en zona libre, detalles
    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
    [FL_MAT_ABC_100kg.dxf, FL_MAT_ABC_100kg.step, FL_MAT_ABC_100kg_3D.dxf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]
2026-09-29 Recipientes ABC sueltos, señalética NFPA/IRAM, accesorios, esquemas de ensayo y documentos técnicos
    - FL_REC_ABC_*: planos de fabricación de los 8 recipientes ABC para venta suelta (DXF/PDF/STEP)
    - FL_SEN_01..05: chapa baliza, cartel F001, símbolos de clase con colores NFPA 10,
    tarjeta de control y etiqueta, sistema de pictogramas NFPA 10 Anexo B
    - FL_ACC_01..03: soporte de pared, soporte vehicular y gabinete modelados en 3D (3 vistas ISO E)
    - FL_ESQ_01..03: banco de prueba hidráulica, línea de carga ABC, flujo de recarga
    - DOC-01..04: pintura/granallado/saponificación, ensayos de fabricación ABC,
    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
    [FL_ACC_01.dxf, FL_ACC_01.step, FL_ACC_02.dxf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]
2026-09-29 Aplica IRAM 3517-2:2005 (texto completo) a documentos, esquemas y señalética
    - DOC-03 reescrito con apartados citados: control trimestral, mantenimiento anual,
    PH 2,5 x Ps mantenida 1 min, intervalos 5 años (polvo, CO2, halogenados) y 2 años
    (agua, AFFF), anexo E, recinto de polvo, marbete, inutilización
    - DOC-02: tolerancias de carga y descarga del anexo E; PH 1 min
    - FL_ESQ_01..03: presiones de PH de recarga e intervalos, procedimiento 4.3.3.6
    - FL_SEN_04: etiqueta celeste 35x50, oblea y disco marbete (3.3.6, 3.6.1, 3.10)
    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
    [FL_ACC_01.dxf, FL_ACC_01.step, FL_ACC_02.dxf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]
2026-09-29 Señalética, documentos y esquemas según IRAM 3517-2:2020 e IRAM 3504
    - FL_SEN_01..08 rehechas con la 3517-2:2020: chapas baliza vertical 350/260 x 870,
    horizontales 800/500 y de baldes (figuras 3, 4, 6), cartel tridimensional (figura 5),
    símbolos y pictogramas con colores IRAM-DEF D 1054 (figura 1), etiquetas de control,
    fuera de servicio, oblea, numeración y rótulo de manguera, reserva y sustituto,
    marbete (figura 9, tabla 4) y traba/precinto
    - DOC-03 reescrito sobre la 3517-2:2020 (PH rodantes 4 MPa, mangueras anuales, tabla 3,
    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
    [FL_ACC_01.dxf, FL_ACC_01.step, FL_ACC_02.dxf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]
2026-10-03 BOM multinivel en Excel y planos de despiece FL_DES
    - flama/bom.py: BOM por plano (17 terminados + 8 cilindros FL_REC) desde el modelo 3D,
    con subconjuntos, materia prima, consumibles, carga, identificacion, soporte y embalaje;
    hojas de recargas por caso (polvo nuevo/recuperado, HCFC recuperado) y explosion de MP.
    - flama/despiece.py: isometria explosionada por subconjunto con globos y lista ligada al BOM.
    - generar.py: opciones --bom y --despiece.
    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
    [FLAMA_BOM.xlsx, FL_DES_ABC_100kg.dxf, FL_DES_ABC_10kg.dxf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]
2026-10-03 BOM: carga segun tolerancia normativa y hoja Carga_N2
    - Carga objetivo = nominal con la tolerancia de IRAM 3517-2 tabla 3 / IRAM 3523 tabla II
    (centro de banda cuando es 0/+X); sin volumen libre minimo artificial.
    - AFFF separado en agua y concentrado 3 %; densidad aparente BC 1,05 (referencia).
    - Hoja Carga_N2: volumen libre, masa de N2/argon por Ps a 20 C, grado de llenado de CO2.
    - Resumen: tara de catalogo (catalogo - carga - gas) frente a tara del modelo.
    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
    [FLAMA_BOM.xlsx, FL_DES_ABC_100kg.dxf, FL_DES_ABC_10kg.dxf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]
2026-10-04 BOM: quimica de agentes como entrada y control de volumen por densidad
    - Quimica_agentes: composicion, mecanismo, saponificacion y densidad min/tip/max
    de cada agente (fuentes: HDS de fabricantes) como celdas de entrada.
    - Carga_N2 por formulas: volumen libre y gas con densidad min/tip/max, control
    NO ENTRA / LIBRE INSUFICIENTE, densidad minima exigible al polvo y volumen
    de recipiente necesario.
    - Gas impulsor de agua, AFFF y acetato: aire comprimido (catalogo, IRAM 3517-2 tabla 2).
    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
    [FLAMA_BOM.xlsx, FL_DES_ABC_100kg.dxf, FL_DES_ABC_10kg.dxf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]
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
